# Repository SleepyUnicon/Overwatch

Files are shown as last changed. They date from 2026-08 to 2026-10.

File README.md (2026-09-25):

<div align="center">

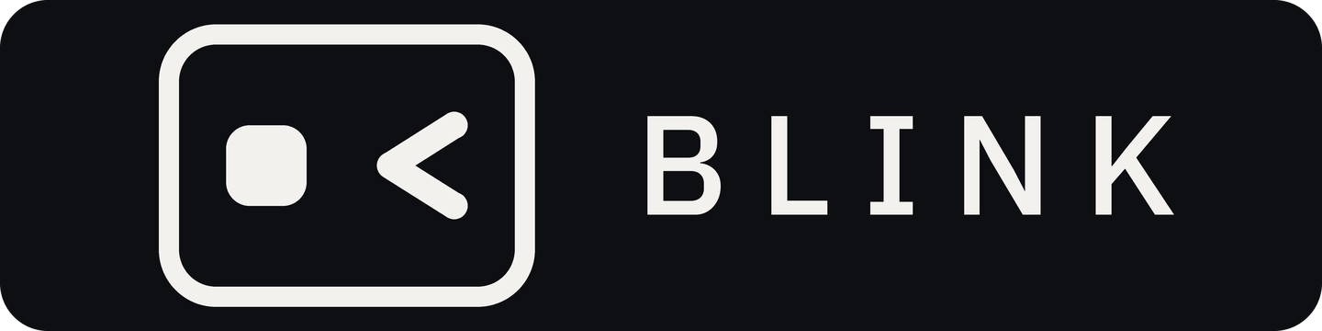
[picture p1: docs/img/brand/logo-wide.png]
OVERWATCH


**Your Claude Code and Codex usage, as two live dials on your desk.**

<p>
  
  
  <a href="https://github.com/openai/codex"><img alt="Works with Codex" src="https://img.shields.io/badge/works%20with-Codex-10A37F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"></a>
</p>
<p>
  
  
  
  
</p>

<table>
  <tr>
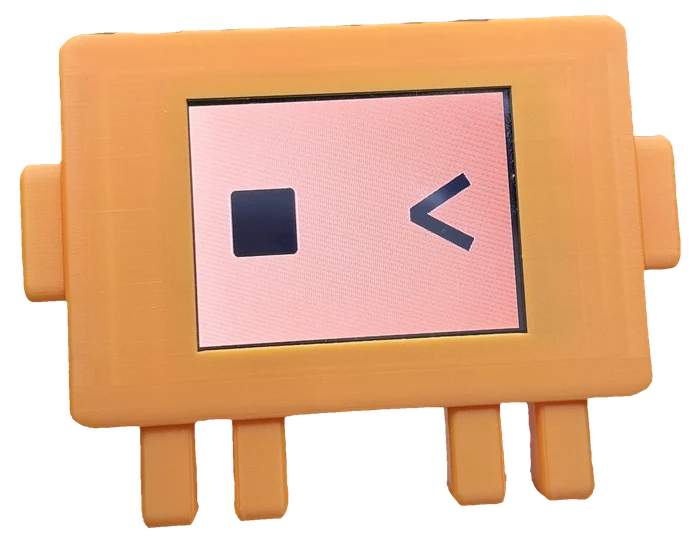
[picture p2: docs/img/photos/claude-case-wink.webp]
The Claude case, mid-overwatch
    <td align="center"></td>
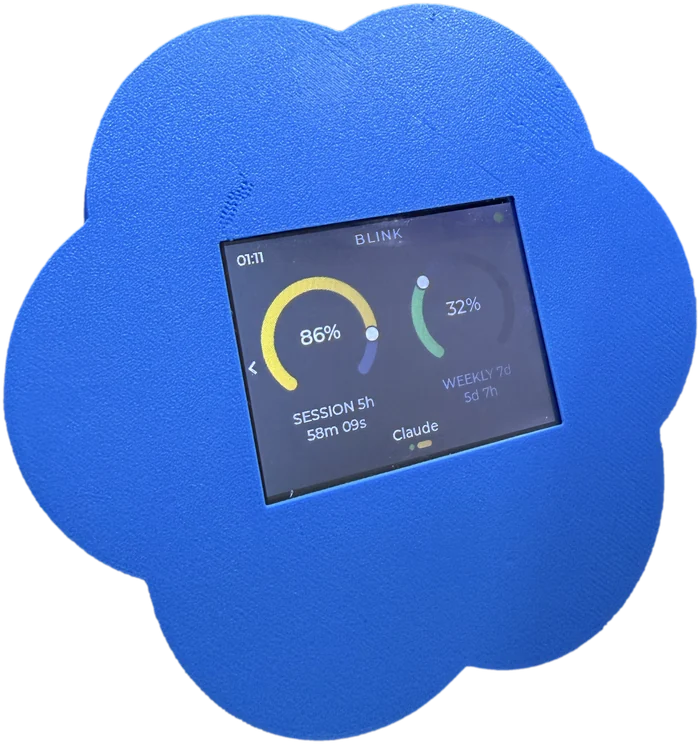
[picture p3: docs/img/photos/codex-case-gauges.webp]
The Codex case, dials live
    <td align="center"></td>
  </tr>
  <tr>
    <td align="center"><sub><b>Claude edition</b></sub>&nbsp;</td>
    <td align="center"><sub><b>Codex edition</b></sub>&nbsp;</td>
  </tr>
</table>

### Don't want to build one?

Ask me for a kit - the printed parts and a flashed board. Free.

</div>

## What it is

OVERWATCH is a small touchscreen that shows the same numbers as Claude Code's `/usage` command, always in view: your **5-hour session** and your **7-day week**, each as a dial that turns from green to amber to red, with a countdown to its reset. It plugs into your computer over USB, sets itself up in one command, and keeps itself updated.

## Open source

**OVERWATCH is open source, and it is free.** Everything the device is made of is
here: the firmware that draws the dials, the app that reads your usage, the
build scripts, the tests. Nothing is held back, nothing is a trial, nothing
expires. The board is an ESP32 "Cheap Yellow Display", about $12 anywhere, and
the case is a 3D print - the files are on
[MakerWorld](https://makerworld.com/en/models/3294736-overwatch-claude-code-codex-usage-monitor).

**You can do anything you like with it, for yourself.** Build one. Build ten.
Change it, rewrite it, put your own name on it. Give them to your friends. Use
it at home, at school, in a club. You will never owe me anything for it.

**The one thing you cannot do is sell it.** Not the device, not the software,
not a product with this inside it. Making money out of OVERWATCH is the only thing
the licence forbids. If that is what you want to do, write to me and ask -
the answer is often yes.

And if you would rather not build one at all, I sell finished units, put
together and tested by hand. That is what pays for the work that goes into
this.

## Features

- **Two dials, two countdowns.** Session and weekly limits, and the time until each one resets.
- **An activity light.** Amber the moment any session - Claude or Codex - is waiting on you; a green pulse while everything is still working; red when a turn dies on an error - a rate limit, most often.
- **A page per provider.** Claude and Codex each get their own screen. Swipe to switch; the needles move from one reading to the other.
- **It sleeps when your computer does.** About thirty seconds after the computer stops answering, the screen closes its eyes and dozes; it opens them the moment the computer is back. A tap while it sleeps shows the last figures.
- **Claude Desktop too.** With Desktop alone the dials show percentages, a five-hour countdown whenever Desktop is holding a reset time, and a weekly countdown once one has been learned. Desktop keeps that reset time only while a window is running and clears it in between, so the countdown comes and goes; the fill rate covers the gaps. The dials follow Desktop's own refresh - about every 5 minutes while you are using it, up to 15 when it sits idle - where Claude Code updates them live.
- **Nothing to sign in to.** It reads figures Claude Code and Codex have already written to disk. No credential, no network, nothing sent anywhere.
- **Updates over the cable.** A new release asks on screen; one tap installs both the firmware and the app. Both halves are signed.
- **Cheap, open hardware.** An ESP32 "Cheap Yellow Display" (~$12) and a 3D-printed case.
- **Company units.** A unit built for a company shows its logo - a still or a short clip - after the boot animation, written once at the factory.

## The screens

<table>
  <tr>
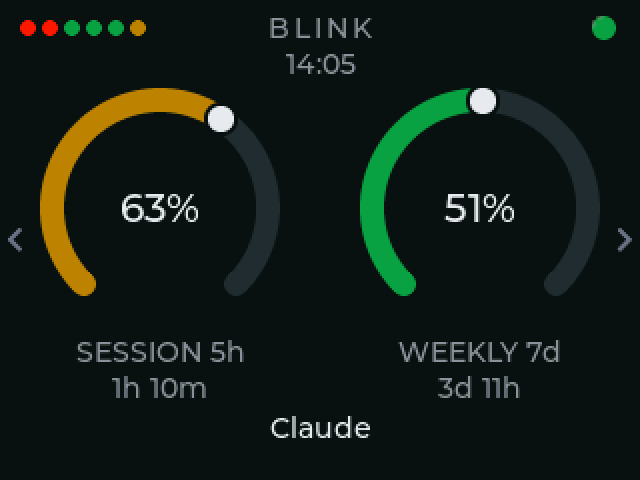
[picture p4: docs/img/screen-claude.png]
The Claude page: six coloured marks in the top-left corner, one per live session, the clock under the OVERWATCH wordmark, and the session and weekly dials.
    <td width="33%"></td>
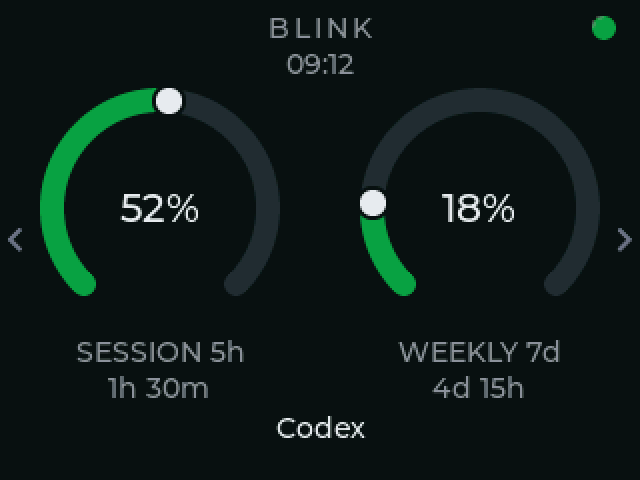
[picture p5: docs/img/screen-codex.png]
The Codex page, with its own session and weekly dials.
    <td width="33%"></td>
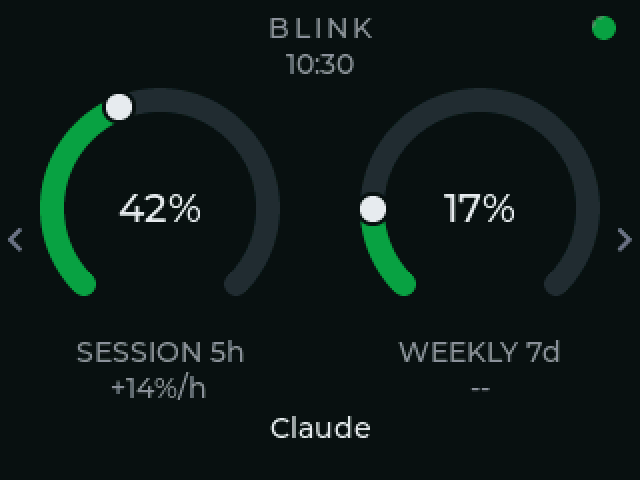
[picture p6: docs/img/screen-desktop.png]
Claude Desktop alone: the session dial shows a fill rate where a countdown would otherwise be.
    <td width="33%"></td>
  </tr>
  <tr>
    <td align="center"><sub><b>Claude</b></sub>&nbsp;</td>
    <td align="center"><sub><b>Codex</b></sub>&nbsp;</td>
    <td align="center"><sub><b>Desktop alone</b></sub>&nbsp;</td>
  </tr>
</table>

Session and weekly, the countdown to each reset, and the time under the wordmark.
The marks in the top-left corner are your live sessions - one per session,
coloured by what each is doing. Claude and Codex each get a page of their own,
and a swipe moves between them. With Claude Desktop alone there is often no reset
time to count down to, so the session dial shows how fast it is filling instead.

*Rendered by the shipping firmware's own drawing code, not mocked up.*

## Setup

One file. Download it, run it, delete it. It copies itself to `~/.overwatch/bin`, finds the board, and starts again every time you log in.

```bash
# macOS (Apple silicon)
curl -fsSL https://github.com/SleepyUnicon/Overwatch/releases/latest/download/overwatch-macos-arm64.tar.gz | tar xz && ./overwatch/overwatch
# macOS (Intel):  .../overwatch-macos-x86_64.tar.gz
# Linux:          .../overwatch-linux-x86_64.tar.gz

```

On Windows, in PowerShell or Command Prompt:

```
curl.exe -fsSL -o overwatch.zip https://github.com/SleepyUnicon/Overwatch/releases/latest/download/overwatch-windows-x86_64.zip && tar -xf overwatch.zip && .\overwatch\overwatch.exe
```

```bash
~/.overwatch/bin/overwatch status      # is the panel getting data?
~/.overwatch/bin/overwatch uninstall   # put everything back
```

Needs Claude Code 2.1.100 or newer. The installer changes one file, `~/.claude/settings.json` (the status line command and one hook per lifecycle event), says so before it does, and keeps your own status line running. Everything it does is reversible with `uninstall`.

## Something's wrong?

```bash
~/.overwatch/bin/overwatch status
```

That one command says whether the service is running, whether Claude Code and Codex are being read, and how old the numbers are. If the panel is dark or wrong, unplug the board and plug it back in first - the app finds it again on its own. If that does not fix it, open an issue on this repository with the output of `overwatch status` and the last lines of `~/.overwatch/bridge.log`; nothing in either is a secret.

**If the board says the app is old.** The board and the app ship together, so normally they match. If they have come apart - the board on a later version than the computer - the board's own update screen cannot fix it, because the half that is behind is the half it cannot reach. `overwatch status` says so and names the cure:

```
Board       COM25 (CH340) -- id 20500d33ff1c, firmware 1.3.2
            the board is on 1.3.2 and this app is 1.3.1 -- they ship together
            run: overwatch update
```

**On Windows, if the board never appears:** the board's USB chip needs a driver Windows does not ship, and the installer puts it in for you - it is the one step that asks for the Windows permission prompt, and it only asks when there is something to install. If you skipped that prompt, or installed an older version, run:

```
%USERPROFILE%\.overwatch\bin\overwatch.exe driver
```

`overwatch status` says which of these you are looking at: a board Windows cannot use yet reads as *"a board is plugged in, but Windows has no driver for it"*, not as an empty desk.

## What it works with

For Claude Desktop, the app learns usage by reading Claude Desktop's own local files on your machine, never anything else - it only ever reads them, and nothing about your usage or your conversations ever leaves the machine.

| You use | You get |
|---|---|
| Claude Code, in a terminal or an IDE | Everything |
| Codex CLI | Everything, on its own page |
| Claude Desktop, without Claude Code | Five-hour percentage and countdown, refreshed within seconds of a turn; weekly percentage on Desktop's own schedule (about 5 min in use, up to 15 idle); a weekly countdown too, once one has been learned, published only while nothing contradicts it; no activity light |
| claude.ai in a browser | Nothing - there is no usage data to read |

## Privacy

OVERWATCH never sees a credential and never sends anything anywhere. It keeps the last usage payload Claude Code wrote, readable by you alone, in `~/.overwatch/`. The device holds no token: nothing to leak, nothing to revoke if you lend it.

## Building units

`tools/burn.sh` programs a unit end to end: it builds signed firmware with the bootloader, flashes it, stamps the edition (Claude or Codex, write-once), and confirms the stamp survives a power cycle. Add `--logo` and the unit shows a company logo after the boot animation. The script fails loudly rather than half-succeeds, and CI runs it on every push against a scripted board so a change to it cannot quietly ship a unit that boots wrong. Details in [docs/README-full.md](docs/README-full.md#programming-a-unit).

## Read more

- **[The full README](docs/README-full.md)** - how the numbers are found, what the installer changes line by line, ports and multiple boards, updates and signing, the decisions behind the first release
- **[firmware/README.md](firmware/README.md)** - building, flashing and signing the firmware yourself
- **[docs/multi-provider.md](docs/multi-provider.md)** - how two sources are merged into one reading
- **[docs/windows-check.md](docs/windows-check.md)** - the ten-minute check a Windows release needs a person for
- **[docs/fleet-testing.md](docs/fleet-testing.md)** - the one command that proves a release on three real desks and three real boards, and what a green run does and does not prove

<div align="center">
<sub>Firmware: Zephyr, C. App: Python, one binary.</sub>&nbsp;<br>
<sub>Board: ESP32-2432S028.</sub>&nbsp;<br>
<sub>Source under <a href="LICENSE">PolyForm Noncommercial 1.0.0</a>.</sub>&nbsp;<br>
<sub>Free to build for yourself. Never to sell.</sub>&nbsp;<br>
<sub>A fork of <a href="https://github.com/KfirLevy258/Blink">Blink</a> by Kfir Levy.</sub>&nbsp;
</div>

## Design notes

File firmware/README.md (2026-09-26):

# Overwatch firmware

The firmware that runs on the **ESP32-2432S028 "Cheap Yellow Display" (CYD)**: two
270° gauges for your Claude Code **session (5 h)** and **weekly (7 d)** usage, a wall
clock, per-model breakdown, and over-the-air updates. Built on **Zephyr** + LVGL,
booting through **MCUboot**, with flash encryption on units whose eFuses are burned.

The firmware version lives in [`src/version.h`](src/version.h) and is reported over
serial in the boot `hello` message.

## How it gets your usage

The board picks a data source at boot - you never choose one:

1. **USB bridge.** If a host daemon answers the boot `hello` over serial, the board
   takes its usage from there (streamed as NDJSON). No Wi-Fi or token on the device.
2. **Wi-Fi.** Otherwise, if it has stored Wi-Fi credentials and a sign-in token, it
   fetches usage itself over TLS, about once a minute.
3. **First-time setup.** With neither available, it shows a setup screen and hosts a
   short phone flow to get onto Wi-Fi and signed in. The setup Wi-Fi is WPA2 with a
   random per-device password carried in the on-screen QR, so the phone types nothing.

## Prerequisites

- **Zephyr v4.3.x** with its Python venv, and **Zephyr SDK 0.17.4**. The build
  scripts find the workspace themselves (`tools/lib_zephyr.sh` looks under
  `~/zephyrproject`, `~/zephyr-v*` and the same two under `~/Projects`); set
  `OVERWATCH_ZEPHYR` to override.

  **Not v4.4.0.** Measured 2026-09-09: its mbedTLS is 4.1.0, which removed the
  legacy `mbedtls/sha256.h` that [`src/ota.c`](src/ota.c) includes, and the
  LVGL it pins moved `gesture_limit` out of the public `lv_indev` headers,
  which [`src/ui_settings.c`](src/ui_settings.c) reads. 4.3.1 has both
  (mbedTLS 3.6.6, `gesture_limit` in `lv_indev_private.h`) and wants SDK
  0.17.4 rather than the 1.0.1 that 4.4.0 asks for. Do not register both SDKs
  at once -- 1.0.1's CMake config breaks 4.3.1's configure even when 0.17.4 is
  registered alongside it.
- The **CYD board** on USB (a CH340 serial port, `/dev/cu.usbserial-*` on macOS).
- Your **signing keys** (see [Keys](#keys)).

## Build

```bash
. tools/lib_zephyr.sh && overwatch_zephyr_activate   # from the repo root

cd firmware
west build --sysbuild -d build-sb -b esp32_devkitc/esp32/procpu . \
  -- -DSB_CONFIG_BOOTLOADER_MCUBOOT=y -DUSE_CCACHE=0 \
  -DSB_CONFIG_BOOT_SIGNATURE_KEY_FILE="\"$HOME/.overwatch/ota_signing_key_p256.pem\""
```

Notes:

- **This builds the shipped configuration: USB only.** `CONFIG_OVERWATCH_WIFI_MODE`
  defaults to `n`, so the captive-portal setup, the OAuth sign-in, the refresh-token
  store and the on-device usage fetch are never handed to the compiler -- absent from
  the image rather than unreachable within it, and about half its size. The source
  stays in `src/`; add `-DEXTRA_CONF_FILE=wifi.conf` to build it back in. `tools/release.sh`
  refuses to publish an image that contains it, checking the artifact and not only the
  config.
- **Sysbuild + MCUboot is required.** Flash encryption needs the MCUboot boot chain;
  a plain single-image build produces something the encrypted chip can't boot.
- The board target is **`esp32_devkitc/esp32/procpu`** - there's no upstream CYD board,
  so [`boards/esp32_devkitc_esp32_procpu.overlay`](boards/) describes the wiring.
  Building with a different `-b` pollutes the build dir; recover with `-p always`.
- **Display SPI is pinned at 25 MHz.** The common 40 MHz CYD overclock white-screens
  some panels (init never latches) - see the overlay comment.

### WiFi mode does not currently link

Tried on 2026-09-26, to test the over-the-air update path. It fails at the
link step:

```
section `.dram0.noinit' will not fit in region `dram1_0_seg'
region `dram1_0_seg' overflowed by 18020 bytes
```

`dram1_0_seg` is 0x18000 -- 96 KB. Two obvious knobs were tried and BOTH
were verified applied in the generated .config, and neither moved the
overflow by a single byte:

| tried | from | to | overflow |
|---|---|---|---|
| `CONFIG_HEAP_MEM_POOL_SIZE` | 86016 | 65536 | 18020 |
| `CONFIG_LV_MEM_SIZE_KILOBYTES` | 64 | 44 | 18020 |

An identical figure across three builds says the thing that does not fit is
none of those -- it is something fixed in `.dram0.noinit`, most likely the
WiFi driver's own static buffers. Whoever picks this up should start by
reading that section out of the map rather than turning config knobs, and
should expect this to be a memory-LAYOUT question (what lives in dram0
against dram1 on this SoC) rather than a sizing one.

Also note `west blobs fetch hal_espressif` is required first; without it
the configure step fails on a missing `libble_app.a`.

None of this is reachable in the shipped build anyway -- `ota.c` is
compiled into every image but `ota_check()`/`ota_install()` are only called
from `net_worker()`, which only standalone mode starts. So the over-the-air
path has never executed on any board.

## Flash

**Not every CYD is fused, so check which one you have first.** A unit whose
flash-encryption eFuses are burned boots *only* images encrypted with its device key;
an unfused unit boots plaintext and cannot read an encrypted image at all. Cross the
two and the board sits in a boot loop (`invalid header: ...`) until it is re-flashed
the other way. Nothing is bricked - flashing burns no eFuses - but a cycle is lost
finding out.

```bash
espefuse.py --port <port> summary | grep FLASH_CRYPT_CNT
```

An **odd** number of bits set means encryption is on; `0` is a plaintext board.

**Fused unit** - use the script, which re-reads the eFuse itself and refuses a
plaintext chip (override with `OVERWATCH_SKIP_EFUSE_CHECK=1`):

```bash
tools/flash_encrypted.sh        # defaults to the first /dev/cu.usbserial* port
```

**Plaintext unit** - two commands, because `west flash` writes only the app at
`0x20000` and leaves MCUboot at `0x1000` untouched:

```bash
west flash -d build-sb --esp-device <port> --esp-baud-rate 115200
esptool.py --port <port> --baud 115200 write_flash 0x1000 build-sb/mcuboot/zephyr/zephyr.bin
```

Port notes: opening the port resets the board, and only one process can own it at a
time. To watch the console without disturbing behavior, use
`tools/passive_log.py <port>` (resets once on open, then read-only). To wipe stored
Wi-Fi / token / setup password for a clean first-run test, erase the NVS region:
`esptool.py --port <port> erase_region 0x3b0000 0x30000`.

Flash map (4 MB): MCUboot `0x1000`, slot 0 `0x20000`, slot 1 `0x170000`,
scratch `0x2C0000` (unused in swap-move mode), **company logo `0x330000`
(512 KB, see `src/logo_parse.h`)**, settings `0x3B0000`. The logo partition is
written only by `tools/burn.sh --logo` / `tools/flash_encrypted.sh --logo` and
read memory-mapped at boot; erase it (`erase_region 0x330000 0x80000`) to turn
a bench board back into an individual unit. `tools/flash_encrypted.sh` erases
it by default -- pass `--keep-logo` when re-flashing a dev board that should
keep its logo.

## Keys

Two secrets live **outside the repo**, in `~/.overwatch/`:

| Key | Purpose |
|-----|---|
| `flash_key.bin` | Encrypts what's written to flash. Override with `OVERWATCH_FLASH_KEY`. |
| `ota_signing_key_p256.pem` | Signs firmware images (ECDSA P-256) so the board will boot them. Override with `OTA_SIGNING_KEY`. |

**Back both up off this machine.** The eFuse copy of the flash key is sealed and
unreadable - the file is the only usable copy. Lose the signing key and you can no
longer ship updates that installed devices will accept (only a USB reflash with a new
key recovers).

## Releasing an update

```bash
# 1. bump OVERWATCH_FW_VERSION in src/version.h, commit
# 2. from the repo root:
tools/release.sh
```

`release.sh` builds from the committed tree (it refuses a dirty tree or a reused
version), signs the image, and attaches `overwatch-fw.bin` + `manifest.json` to the
`overwatch-v<version>` release on **`SleepyUnicon/Overwatch`** - which is the feed every board reads.

On the device there are two ways in, and it picks by itself:

- **Standalone (WiFi).** The board streams the image into its spare slot, verifies the
  SHA-256, reboots, and MCUboot swaps it in.
- **Tethered (USB bridge).** This mode has no network of its own -- `run_usb()` never
  starts `net_worker` -- so the board only *approves*, and the daemon fetches the
  release and writes slot0 with esptool. About 75 s, and no swap, because the bytes
  land where the bootloader already looks. The trade is no automatic rollback on that
  route; it is acceptable only because a machine that can reflash the board is by
  definition already cabled to it. Requires `pip install esptool` wherever the daemon
  runs.

A check runs as soon as the board is up (and daily after that). Anything newer raises a
prompt on the gauge screen -- **Update now** / **Later** -- and the settings row still
offers **Software update → Install x.y.z** on demand. Either route reports the outcome
on the next boot.

## How updates stay safe

Four independent layers, each guarding one thing:

- **TLS with pinned roots** authenticates the *download*.
- **The manifest's SHA-256** pins the *exact bytes*, end to end.
- **MCUboot's ECDSA P-256 signature check** gates *what may boot* - only images signed
  with your private key run, so even a hash-passing forgery is rejected.
- **Automatic rollback** - a fresh image boots in test mode and must prove itself
  (fetch usage) within 90 s. If it hangs or crashes, the watchdog reboots and MCUboot
  restores the previous version, which then reports *"Update failed, previous version
  restored."*

The first three hold on both routes. The fourth does not apply to the USB one, which
writes the running slot in place -- there is no spare copy to fall back to. The daemon
compensates where it can: it verifies the asset against its manifest before writing,
and it reads the chip's eFuses and refuses outright if it cannot tell whether flash
encryption is burned, since a plaintext write to a fused board leaves it dark.

On a fused unit, flash encryption keeps secrets (Wi-Fi password, token) unreadable at
rest. **An unfused development board has no such protection** - its stored Wi-Fi
password and OAuth token are readable from a flash dump, so treat one as a device that
holds live credentials in the clear. Published images hold no secrets either way -
installability is gated by the signing key, not secrecy.

## Hardware notes

Things worth knowing when hacking on the CYD:

- The radio occasionally boots blind (all scans empty) after a soft reset; the firmware
  self-reboots to re-roll it, bounded by a `.noinit` counter.
- Touch (XPT2046) needs averaging (`reads = <8>`), and devicetree properties are
  last-one-wins - a stray duplicate silently degrades it.
- The backlight (GPIO 21) runs on LEDC PWM and is adjustable in Settings.
- A Wi-Fi join only completes from a clean boot on this driver, which is why the
  first-run flow reboots on purpose (invisibly - the CONNECTING bar spans the reset).

## Source map

| Area | Files |
|---|---|
| Boot, orchestration, workers | `main.c` |
| Boot splash (streamed past LVGL) | `ui_boot.c`, `bootanim_dec.c` |
| First-run setup screen | `ui_setup.c` |
| Phone captive portal | `portal.c`, `dns_hijack.c` |
| Gauges, warnings, model card | `usage_view.c` |
| Settings + software-update UI | `ui_settings.c` |
| OTA engine (check, install, verify) | `ota.c`, `ota_parse.c` |
| Networking, time, sign-in, fetch | `net_wifi.c`, `net_time.c`, `oauth.c`, `usage_client.c`, `usage_parse.c`, `tz_fetch.c` |
| Persisted config (A/B, CRC-sealed) | `cfg_store.c` |
| Serial NDJSON protocol | `proto.c`, `msg_parse.c` |

Parsers and the protocol have host-side unit tests under [`../tests/`](../tests/).

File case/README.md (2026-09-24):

# The Overwatch case

A bezel that shows the **picture and nothing else**, and an **empty** tray that
plugs into the back of it. Two printed parts, no screws, no posts, nothing
inside the body at all.

| part | | print it |
|---|---|---|
| `front_bezel.stl` | 90.8 × 54.8 × 11.2 | face **down** |

Assembled the case is **46.2 mm** front to back — the bezel stands 6.2 in front of the tray, so the tray's own 40.0 is not the whole depth.
| `back_tray.stl` | 90.8 × 53.1 × 40.0 | open side **up** |

```sh
openscad -D 'PART="front"' -o front_bezel.stl overwatch_case.scad
```

## What changed, and why

The version before this had two faults that between them cost a panel.

**The aperture was sized to the glass, and the glass was a press fit in it** —
0.3 mm nominal, which an FDM hole can easily print *undersize*. The only way
the panel went in was by being pressed, and pressing a glass module into a
too-small hole cracks the flex between the glass and its board. It then lights
up white and never draws, with nothing in any log to say why.

**Four snap pegs sat inside the panel's footprint** — x=±40, y=±12 against a
board of ±43 × ±25. To reach their sockets they travelled through the space the
board occupies, so assembling it would have pressed four posts into the back of
the panel. They had been moved out of the corners to save border and never
checked against the board.

Both are gone. **The lip now overlaps the glass**, so the glass does not pass
through the aperture at all — it goes in from behind and rests against the lip.
There is no press fit left to be tight. And there are no pegs, because there is
nothing inside.

## The window

Sized to the **lit area**, not the glass. The glass carries 5.7 mm of dead
black each side and 3.4 top and bottom; that dead black was the border you
could see. It is under plastic now.

| | |
|---|---|
| at the glass | 59.6 × 45.2 |
| at the face | 63.6 × 49.2 — chamfered out 2.0 per side |
| visible border | 13.6 sides, 2.8 top and bottom |

The **chamfer is on the left and right only** — 3 mm per side. It keeps the
corners from catching a fingertip reaching for the edge of the picture.

Chamfering all four edges cost 3 mm of border top and bottom, where there is
only 5.4 to begin with: it left a **1.4 mm knife edge** against sides of 9.4
and 15.4. The sides can afford the taper and the top and bottom cannot, so the
top and bottom walls stay square and the border there is 4.4.

The window sits on the **glass's** centre, not the board's — 8 mm of red on
the left against 9 on the right, so centring it on the board would put the
picture half a millimetre out.

### Where the picture actually is

**Measured on the board, 2026-09-24**: the picture starts 11 mm in from one end
of the 86 mm board and 17 mm in from the other — so it is **58.0 wide** and its
centre is **3.0 mm off the board's**.

Two independent measurements agree. Reading off the printed case gave 13 and 20
from the *case* edge; with the board inset 2.4 each side that is 10.6 and 17.6
from the board edge, against 11 and 17 here — within 0.6 mm. The board reading
is the one used, because it does not depend on the case having printed to size.

58.0 also lands 0.4 mm off the nominal 57.6 for a 2.8" 4:3 panel. That kind of
agreement usually means both numbers are right.

The window is drawn 1 mm larger all round, so it sits **1.0 mm outside the
picture on every side** — a sliver of black glass shows and nothing is covered,
which is the direction to err.

**The vertical inset has not been measured.** The picture is assumed centred on
the board's 50 mm, which the glass being full height makes likely — but it is
an assumption, not a measurement. If it turns out to be off, `act_h` and a
vertical offset are the two numbers to add.

### Square corners

`ap_r` is 0.4 — half a nozzle, i.e. as square as an FDM part gets. The
display's own corners are sharp, so a rounded window would leave four crescents
of black glass showing at the corners and nothing else.

## Clearances

**1.0 mm everywhere the panel touches**, against 0.4 before. The old 0.4 is
what made it a press fit, and the press fit is what broke the flex.

## How the halves join

At the **rim**. The bezel carries a 1.4 mm rim reaching back past the board;
the tray's spigot plugs into it. Friction — and the join is at the perimeter
where there is room for it, not through the middle where the panel is.

`rim_fit` (0.2 per side) is the number to tune. Loose, lower it; will not
seat, raise it. Only the tray needs reprinting.

## The panel's seats, and why they are not dead square

The panel has sharp corners, so the seats are cut as square as the geometry
allows — but "as square as allows" is a real limit here, not a shrug.

**The corner radius comes from the clearance.** A sharp corner in a pocket
rounded by *r* clears by `r − √2·|clear − r|` while *r* > clear, and by the
full `clear` once *r* ≤ clear. So `seat_r = clear` is the point where the
corner clears exactly as much as the flats do, and sharper buys **nothing**.

**It cannot go sharper anyway.** The seat's corner is at (44, 26); the outer
profile's corner arc is centred at (41.4, 23.4) with r=4. Dead square leaves
**0.323 mm** of wall there — under one extrusion, so it prints as a hole.

| seat r | wall at the corner | corner clearance |
|---|---|---|
| 1.5 | 0.944 | 0.793 ← what V1 had |
| **1.0** | **0.737** | **1.000** ← here |
| 0.0 | 0.323 | 1.000 — unprintable |

Corner *relief* — a small circle centred on the corner — is out for the same
reason: it would have to be under 0.323 to stay inside the wall. Tried it; it
punched straight through the outside face at all four corners.

### What actually held the first V1 off was the clearance

Not the rounding. At `clear` = 0.4 the board's corner fell **1.556** from the
arc centre against a **1.5** radius: fouling by 0.056 before the printer added
its own corner fillet. At `clear` = 1.0 it clears by the full millimetre. The
rounding only mattered because the clearance was too small to absorb it.

## The bezel-to-tray joint

Measured off the two STLs, on the mating flats:

```
bezel rim opening   ±44.00   outer ±45.40   (a 1.40 ring)
tray spigot         ±43.80   inner ±41.80   (a 2.00 wall)
                 -> 0.20 a side
```

Two surfaces land **at the same moment**: the tray's shoulder on the rim's back
face at z=11.2, and the spigot's nose on the board's back face at z=6.2. The
spigot is 5.0 long and the rim cavity is 5.0 deep, so the joint closes flush
with no step — and the panel is held with **zero nominal slack**.

That is the one number to watch. It is right if the panel really is 3.4 of
glass on a 1.6 board; if it measures 5.2 rather than 5.0, the difference goes
into the glass. Standing the spigot off 0.3 would trade that risk for 0.3 of
play — the shoulder would still be the hard stop, so the joint stays flush.

The corners clear comfortably: the spigot's corner-most point is 0.054 from the
rim opening's arc centre against a 1.0 radius.

## The connector edge

The display's connectors sit on the **back** of the panel and start right at
the edge on the case's right-hand side — negative x, the same edge the USB
comes out of. The spigot's nose overlaps the board by 1.2 all the way round,
so on that edge it landed straight on them.

Nothing *inboard* of the spigot's inner face needed any help: that is open
cavity, 33 deep. Only the 1.2 band where the nose overhangs the board was in
the way, so that band is cut back over `panel_conn` = 3.4 (the 3.0 measured
behind the board, plus 0.4).

```
spigot's -x wall at z=1.0 (in the relief) : -43.80 .. -43.00   0.8 thick
spigot's -x wall at z=4.5 (past it)       : -43.80 .. -41.80   2.0 thick
```

The spigot keeps its full **outer** face there, so it still locates in the
rim — it just stops touching the board on that one edge. The panel bears on
the other three, which is plenty given the glass is also carried by the lip
all the way round.

## The ESP32's perch

The board lies **flat against the back wall**, component side toward it, with
its pins and dupont shells pointing forward into the body — the only place with
room for them. Two rails stand off the wall, each with a groove the board's
long edges slide into. It goes in **from the right** until its port end meets
the wall, so the USB-C lines up with the slot by construction.

The rails' inner faces sit *inside* the board's width, which only works because
it slides in sideways — they could not capture an edge they did not overlap.

### The slot is cut to the board

| | board | slot | slack |
|---|---|---|---|
| width | 27.94 | **28.24** | 0.15 a side |
| thickness | 1.60 | **1.75** | 0.15 total |

It used to leave 0.50 a side and 0.30 on the thickness, which is a rattle, not
a fit. FDM takes most of the new figure back — a slot prints 0.1–0.2 narrow —
so 0.15 lands near zero slack in the plastic.

`esp_fit` is the number to open up if the board will not go in. **Do not force
it.** Forcing a fit is how the first display's flex went.

The three faces are now named rather than derived by arithmetic on the rail's
centreline: `y_grip` (the lip's inner edge, over the board), `y_slot` (where
the board's edge stops) and `y_out` (the rail's outer face). The slot is cut
from the centreline outward so it stays open inboard — a slot closed on both
sides is one the board cannot enter.

### Everything inside is clipped to the cavity

The perch is sized for the **board**, then intersected with `tray_inside()`,
the same shape that hollows the box. Without that clip the end stop — board
width plus the gap plus both rails, 35.14 across — drove a 3 mm tab straight
through the bottom of the case, and the rails broke through by 0.41 over their
last few millimetres.

The cavity is not a box. The underside slants at 15°, so it is **narrower at
the back**: its floor is at −17.43 where the board's groove sits (z 30.4–32.0)
but has climbed to −15.56 by the back wall. A part that clears the floor at
the front can still be outside the case at the back. Clipping makes that
impossible to get wrong again, whatever the perch is later resized to.

### The numbers are the board's own

| | spec | the model used to say |
|---|---|---|
| length | **48.26** | 52.0 — 3.7 too long |
| width | **27.94** | 28.0 |
| pins below the board | **8.50** | *nothing at all* |

### The standoff is set by the PLUG, not the socket

`esp_stand` = 6.0 mm. The connector is only 3.16 tall, so 4 would clear it —
but a USB-C plug's overmould is about 7 across, centred on that socket:

| standoff | plug reaches | back wall at 38 |
|---|---|---|
| 4 | 39.08 | **fouls** |
| 5 | 38.08 | **fouls** |
| **6** | **37.08** | clears by 0.92 |

At 4 mm the cable hits the case before it seats — and the socket would have
looked perfectly fine in a render.

## The vents

**Two rows of hexagons across the top of the back wall**, with the board
directly underneath.

The cell size is not a style choice. The slanted underside has risen to
y = −15.56 by the time it reaches the back wall, so the usable height there is
**42.96 mm** — and the board takes 27.94 of it. That leaves about 12 mm for two
rows, which sets `hex_r` at 2.6.

The board is centred on y=0, spanning −13.97 to 13.97: clear of the floor by
1.59 and topping out just under the vents at 13.6.

### They were sealed too, and by the same arithmetic

The cell was extruded from `rim_d + tray_d + back_t - 1` = 39, through
`back_t + 2` = 4, so it cut 39→43. The back wall spans **38→40**. Every cell
kept a 1 mm skin on its inside face — the identical fault to the port, one
wall over. It now starts at `rim_d + tray_d - 1` = 37.

**Genus was how both were caught.** A closed box with *n* holes through its
walls is genus *n*: it read 0 while both were skinned, and 1 once only the port
was open.

It is not the check to keep, though — genus counts *every* handle, including
three small channels where the lower rail merges into the sloping floor. Shrink
the rails (`-D esp_l=5`) and the tray reads exactly 22, one port and 21 cells.

Cast a ray through each cell instead. That answers the question actually being
asked — **is this hole a hole** — and it does not care what else the part does.

### The port

A **stadium, not a rectangle** — 12.95 × 7.10, fully round-ended, centred at
z = 33.58. Its position is derived, not chosen: `rim_d + tray_d - esp_stand +
usb_shell_h/2`, which puts it on the socket's centreline by construction.

The size is the **plug's**, not the receptacle's. The spec's maximum cable
overmould is 12.35 × 6.50; `usb_fit` adds 0.60 for slop and for FDM printing
holes 0.2–0.4 under. Sizing this opening 8.94 × 3.16 to match the socket would
look right and pass no cable at all.

#### It was sealed shut, and the cavity was why

The opening is cut `wall + 2` long, from x 42.4 to 46.4 — correct for a 2.0
wall whose inner face is at 43.4. But `tray_inside()` carried the **spigot's**
width all the way to the back, putting the real inner face at 41.8 and making
the sides 3.6 thick. The cut stopped 0.6 short and left a skin across the port.

The same mistake cost the board its slot. `x_wall` is `face_w/2 - wall` =
43.4, so the stop sits 48.26 from there — but with the cavity ending at 41.8
the gap was only 46.66, and the ESP32 is 48.26. **It would not have gone in.**

The cavity now steps: the spigot's width through the spigot, where it has a
rim to enter, and the body's width through the body, where it has no reason to
give up 1.6 mm a side. Both faults close together.

A useful tell: a hollow box with a hole through one wall is **genus 1**. While
the skin was there OpenSCAD reported genus 0.

#### Which side is it on?

The viewer's **right**, which is **negative x**. That sign is the whole trap
and I had it backwards.

The screen's face is at z=0 and the body runs back to +z, so the viewer looks
**along +z** with +y up. For a right-handed frame, a viewer whose forward is
+z and whose up is +y has their right hand pointing at **−x**. Write "the USB
is on the right" as +x and the case comes out mirrored — port on the far side,
and the wide border mirrored with it.

Nothing catches this. The box is symmetric enough that no render looks wrong,
and the relational check — *is the port on the same side as the wide border?* —
passes happily while **both** are on the wrong side. It took putting the part
on a build plate, with the slant on the bottom where it belongs, to see it.

So `act_cx` is no longer a signed guess. It is derived from the border the
viewer actually sees on their right:

```
bez_right = 17.0;                                  // measured
act_cx    = -pcb_w/2 + bez_right + act_w/2;        // = +3.0
```

and the board's port end butts `-(face_w/2 - wall)`. Both now read 18.35 on
the viewer's right and 12.35 on their left, against the measured 17 and 11.

#### Could the opening be socket-sized?

Only if the socket's mouth is flush with the outside. It sits `usb_over` = 1.20
proud of the board's end, and the board butts the inner face at 43.4, so the
mouth lands at 44.6 — 0.8 behind the outer face at 45.4. Whatever passes
through that last 0.8 mm has to be plug-shaped.

To get a 9.5 × 3.8 opening instead, pocket the wall 0.8 deep where the board's
end lands, bringing the socket flush; the overmould then stops against the
outside of the case and 1.2 mm of wall remains around the pocket. It hangs
entirely on `usb_over` being right — measure it before committing to it.

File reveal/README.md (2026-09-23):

# The Overwatch films

Four eight-second clips at 1080x1920, built headless in Blender from the same
STLs the case prints from. Nothing is modelled twice: change
`case/overwatch_case.scad`, re-export, and the next render picks it up.

```sh
BL=/Applications/Blender.app/Contents/MacOS/Blender

$BL --background --python scene.py -- --shot reveal  --portrait \
    --res 1080 1920 --samples 64 --anim overwatch_reveal_9x16.mp4

$BL --background --python scene.py -- --shot widgets --portrait \
    --res 1080 1920 --samples 64 --anim overwatch_widgets_9x16.mp4

$BL --background --python scene.py -- --shot sweeps  --portrait \
    --res 1080 1920 --samples 64 --anim overwatch_sweeps_9x16.mp4

$BL --background --python scene.py -- --shot hand    --portrait \
    --res 1080 1920 --samples 64 --anim overwatch_hand_9x16.mp4
```

Drop `--portrait` for 16:9. A single frame, for iterating on the look without
waiting for 240 of them:

```sh
$BL --background --python scene.py -- --shot widgets --portrait \
    --still 85 --res 405 720 --samples 20 --render look.png
```

## Shot 2 - the widgets

The three pages, swiped. Gauges, Spotify, launcher, and back to gauges so the
clip LOOPS - it is going on a feed, and a hard cut back to the first frame is
the one thing a viewer always notices.

The swipe is not a texture swap. `make_screen.py` stacks the three pages into
one tall image and the material maps a third of it onto the panel; sliding the
mapping IS the swipe, so the transition is whatever easing the keys carry.
13 frames of travel, which is about 0.45 s - what a deliberate page change
feels like on the panel.

The barbell is cropped at the sides here on purpose. The subject is the
screen, and holding the whole 182 mm silhouette in frame would put the panel
too far away to read.

## Shot 3 - the sweeps

Four fast moves, each snapping to a new angle and settling, with a push-in on
the third. `snap()` keys them QUAD / EASE_OUT rather than SINE / EASE_IN_OUT,
which is the whole difference between a camera whipping somewhere and a
camera drifting there. Lit from frame one; nothing is being revealed.

## Shot 4 - the hand

A finger, not a hand. A modelled hand that is not very good is worse than no
hand at all; a finger entering soft and slightly out of focus reads as a hand
without claiming to be one. It is a capsule with a warm subsurface skin
shader, and motion blur does most of the work.

**The swipe travels UP, not sideways.** `ui_pages.c` walks the stack
vertically, so a horizontal swipe here would show a gesture the firmware does
not implement.

## Shot 1 - the reveal

| | |
|---|---|
| 0.0 - 1.0 s | Near-dark. Only the rims are up, so the barbell reads as a silhouette before anything else does. |
| 1.0 - 3.0 s | Key and fill come up. The form arrives. |
| 4.0 - 5.0 s | The panel wakes - a stutter, then it holds. |
| 5.0 - 8.0 s | Settles onto the hero three-quarter as the camera rises and slows. |

The order is the whole point: light first, screen second. A panel that is lit
from frame one has nothing left to give at frame 130.

## The launcher icons

`icons/` holds the six app icons, extracted from the installed bundles on this
Mac with `sips` - Claude, Illustrator, Photoshop, Spotify, Brave and PCSX2.
Real icons rather than drawn approximations: a launcher showing what it
launches is the ordinary thing, and hand-drawn near-misses of six brand marks
would look worse and sit less comfortably.

**The firmware draws these icons now.** `tools/encode_icons.py` turns this
directory into `firmware/src/icons_gen.h` - 6 icons at 40x40, RGB565A8,
28 KB of flash - and `ui_launcher.c` draws them, falling back to text for any
key it was not built with. So the clips and the board agree.

Re-run the encoder if you change the icons:

```sh
python3 tools/encode_icons.py --in reveal/icons --size 40
```

## 9:16

`cam_d.sensor_fit = 'HORIZONTAL'` is load-bearing in portrait. On AUTO,
Blender fits the sensor to the LARGER dimension - which in 9:16 is the height
- and the barbell, the widest thing and the whole silhouette, runs off both
edges. Fitting to width is what makes the framing mean the same thing in
either aspect.

## Decisions worth keeping

**EEVEE, not Cycles.** Cycles on the M4 rendered one 960x540 frame in 2 min 11 -
about eight hours for the sequence. EEVEE with raytraced shadows does this
lighting at roughly a second a frame. For a dark studio with four area lights
and one emitter, the difference on screen does not pay for the difference in
time.

**The screen is the real UI.** `make_screen.py` draws the shipping layout -
two arcs, their percentages, the countdowns, the wordmark and the session pips
- at 8x panel resolution so it stays sharp when the camera is close. It is an
emitter, so it lights the bezel around it.

**Emission is 1.85, not 5.** AgX desaturates anything near clipping, and at 5
the blue arcs rendered white. The number is set by what survives the transform,
not by what looks bright in isolation.

**The floor is rough, not dark.** Three rounds of darkening the floor did
nothing about the bright pool in the corner of frame, because it was a
SPECULAR reflection of the rim lights and specular ignores base colour.
Roughness 0.62 and specular level 0.18 are what actually reached it.

**The lights are aimed by constraints,** not by hand-written euler angles. The
hand-set version put a hot pool of floor in the opening frame.

**0.2 mm layer lines.** A wave texture along the print's own Z drives a 0.09
bump. Almost invisible, and it is the difference between a render of a 3D
print and a render of an injection moulding.

## Blender 5 gotchas this script already handles

Three API changes that each cost a debugging round:

- **`action.fcurves` is gone.** Keyframes live in slotted actions now;
  `fcurves_of()` handles both shapes.
- **The compositor is a node GROUP on the scene** (`compositing_node_group`),
  there is no `scene.node_tree` and no Composite node - and the group's Image
  input does NOT carry the render. Wire the group input straight to the output
  and every frame comes out black. Use a Render Layers node inside the group.
- **Node settings are SOCKETS now.** `glare.glare_type` does not exist;
  it is `glare.inputs["Type"]`, and the enum values are title case (`Bloom`,
  `High`), not upper.
- **Video output needs `image_settings.media_type = 'VIDEO'` first.** Setting
  `file_format = 'FFMPEG'` on its own is rejected with a list that does not
  mention video at all.

## Knobs

| | |
|---|---|
| Length | `FPS, SECS` near the top of the animation block |
| Camera | the `(dist, lift)` pairs and the pivot's start/end angles |
| Exposure | each light's `energy`, and the `ramp()` calls that bring them up |
| Screen wake | the `ramp(bs, ...)` stutter keys |
| Bloom | the `put(glare, ...)` calls |

## What this is not

It is a render of a model that has never been printed. The layer lines are
procedural, the plastic is ideal, and nothing sags. When a real one exists,
a photograph of it beats this - use this until then.

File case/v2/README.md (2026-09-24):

# V2 — the wedge

A slanted screen on a flat base. **Two printed parts, no screws.**

| part | what it is | print it |
|---|---|---|
| `v2_shell.stl` | the wedge: slanted front with the window, vertical back with the port and honeycomb, closed top and sides, **open bottom** | on its **back** |
| `v2_base.stl` | the bottom, snaps in and carries the ESP32 | flat, posts up |

Everything enters from underneath — panel, loom and board — so the shell has
no seam anywhere you look at it.

```sh
openscad -D 'PART="shell"' -o v2_shell.stl overwatch_v2.scad
```

**90.8 wide x 70.0 deep x 53.2 tall.**

## Why the port reaches the back here, and could not in V1

A DevKitC carries its USB connector on a **short end, in the plane of the
board**. V1 laid it flat against a *vertical* back wall, so that port pointed
at a **side** wall — the back slot first cut there would have opened onto
solid board.

Lying it flat on a **horizontal** base turns the port to face horizontally.
Aim that end at the back wall and it exits the back. That is the whole trick,
and it only works because the base is flat.

## The depth is not 52, and not 52 plus the lean either

The panel leans back **over** the base, so the board sits under it — they
overlap in plan, and adding the two was wrong.

But the panel's back surface is a sloping line,
`z(y) = y·tan(lean) + panel_d/cos(lean)`, and the board has to start behind
wherever that line sits at the board's own height:

| ESP32 height | board starts at | case depth |
|---|---|---|
| 20 mm (dupont shells standing up) | 18.8 | 73.2 |
| 6 mm (bare board, cables led flat) | 13.7 | 68.1 |

**Lying the cables flat is worth 5 mm of case.** 70 is the built figure.

## 20 degrees

Sitting at a desk — eyes ~35 cm up, device ~40 cm away — your sight line drops
about **41°**, so a screen aimed straight at you would lean **49°**. That
costs 90 mm of depth and is not buildable here.

| lean | height | depth | off-axis |
|---|---|---|---|
| 15° | 48.3 | 64.9 | 34° |
| **20°** | **47.0** | **69.1** | **29°** |
| 25° | 45.3 | 73.1 | 24° |
| 30° | 43.3 | 77.0 | 19° |

29° off-axis is well inside what an ILI9341 takes without washing out. Past
25° the depth climbs faster than the viewing angle improves.

## One coordinate convention, stated once

`wedge()` rotates a profile by `[90,0,90]`, which maps local `(x,y,z)` to
world `(z,x,y)`. So throughout:

```
world X = WIDTH    (centred on 0)
world Y = DEPTH    (0 at the front edge, +depth at the back)
world Z = HEIGHT   (0 at the base)
```

The first version wrote every cut with Y as height and Z as depth — the other
way round — so the window, the port and the vent all landed outside the solid
and removed nothing. **The shell rendered as a featureless box**, which is
exactly what that looks like.

## The front face is thicker than the wall

The glass stands **3.4 mm proud of its board**, so 3.4 of face in front of the
PCB is what makes it finish flush; the board's own 1.6 sits behind that.
`front_t = 5.0`.

2 mm of wall would leave the glass standing 1.4 proud and the pocket cutting
clean through the face — a front you could see straight through, which is
what the second render showed.

The board is held by the two **ledges under the red strips**, as in V1, and
for the same reason: the glass is the full height of the board, so there is no
red top or bottom to grip.

## Two things the first print got wrong

**The base would not seat — it fouled the front.** The shell's front wall
leans, so the cavity's front boundary moves *back* as it rises:
`Y = z·tan(lean) + wall/cos(lean)`. The lip was drawn as a straight-sided
rectangle, so it cleared at the bottom and jammed harder the further in it
went:

| height | cavity starts at | lip front | |
|---|---|---|---|
| 0.0 | 2.13 | 2.25 | clears |
| 2.5 | 3.04 | 2.25 | **1.79 mm clash** |
| 5.0 | 3.95 | 2.25 | **1.70 mm clash** |

The lip's front is now set back to clear at its *tallest* point, which is the
only place that matters: `lip_h·tan(lean) + wall/cos(lean) + lip_fit` = 4.20.

**The ESP32 had nowhere to sit.** The first version was two bare pegs. They
held the board off the floor at roughly the right height and did nothing else
— nothing located it sideways, nothing stopped it sliding, nothing held it
down. Pushing a USB-C cable in would simply shove the board off them.

It is a cradle now: pads to set the height so the port centres on the hole,
side rails with a lip that the board slides under **from the back**, and a
stop at the front. The board slides back until its port end meets the shell's
back wall, so the connector lines up by construction rather than by careful
placement. Plug and unplug without the board moving.

## It only goes in one way

A rib on **one side rail** of the base's lip, 20 mm from the front, and a slot
for it in the shell's matching side wall.

It was on the *back* rail first, meant to be blocked by the leaning front wall
when reversed — but only by **0.52 mm**, because the lip's front is already set
back 1.95 mm to clear that lean, and a reversed base simply eats the slack. The
setback fights the keying.

Off-centre along the **length** cannot be symmetric. The rib spans Y 8–32;
reversed it lands at Y 38–62, where the shell's wall is solid. The two ranges
do not overlap at all, so it cannot even half-seat, and it is blocked by the
rib's full 1.25 mm with nothing to absorb it.

**24 × 4 mm, standing 1.5 proud.** It was 10 × 3 first, which keyed correctly
and could not be *found* — at that size it reads as a print artefact rather
than a feature, and a tab that small snaps off the first time the base is
prised out. Length is free here, since the blocking depth is what does the
keying, so it buys visibility and strength for nothing.

Telling front from back by eye, if you need to: the **finger notch** is on the
front edge, the **cradle rails** are at the back, and the lip sits 4.2 mm in at
the front against 2.25 at the back.

## Room for the flex

The glass is 69 wide on an 86 board, so its flex has to reach the PCB at one of
the two **short** edges — the 8 mm and 9 mm red strips. The pocket gave those
edges **0.4 mm**, which is nothing: a flex that wraps the edge, or merely
stands proud of it, is gripped by the pocket wall. A panel went white after
being fitted, and this is the likeliest reason.

Both short edges are now relieved by `flex_gap` (1.5 mm), over the middle of
the edge only. Relieving the whole edge would leave the board unlocated in X
and the picture would wander in the window; `flex_land` (9 mm) keeps a land at
each corner to place it.

Both edges, because which one the flex exits is not something a photo settles,
and relieving the unused side costs nothing.

## The number to tune

`lip_fit` (0.25 per side) is how tightly the base sits in the shell.

| symptom | change |
|---|---|
| base falls out or rattles | **lower** by 0.05 |
| will not seat, or the shell bows | **raise** by 0.05 |

Only `v2_base` needs reprinting; the shell is unchanged.

## Print notes

The shell prints **on its back**: the back is flat, the open bottom faces
sideways, and the slanted front becomes a 20° overhang — inside the 45° rule,
so no supports.

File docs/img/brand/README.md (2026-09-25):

# Overwatch brand assets

Generated by `tools/logo.py` in the website repo
(`~/Projects/OverwatchWebsite`), which holds the geometry. Do not hand-edit
anything here: run that script and copy the output over.

| file | for |
|---|---|
| `logo-wide.svg` / `.png` | the horizontal lockup - mark left, wordmark right. The README banner. |
| `logo.svg` | the stacked lockup, light ink, for dark grounds |
| `logo-dark.svg` | the same in dark ink, for white |
| `logo-mark.svg` | the mark in `currentColor`, for pasting into a page |
| `logo-mark-light.svg` / `-dark.svg` | the mark with an ink baked in, for opening anywhere |
| `favicon.svg`, `favicon-32.png` | browser tab |
| `icon-512.png`, `apple-touch-icon.png` | app and home-screen icons |

One ink, white on black. The mark has to print on a case in a single colour,
so nothing in it depends on a second one. The wordmark is converted to
outlines, so these files do not need IBM Plex installed to render correctly.

The older `docs/img/logo.*` and `icon.*` copies were removed on 2026-08-29; the
pre-rebrand originals are in git: `git show 5c48743:docs/img/logo.png > old-logo.png`.

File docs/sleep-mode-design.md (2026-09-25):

# Sleep mode — design (2026-08-30)

Approved in conversation 2026-08-30. Ships as 1.2.0 (firmware + app).

## What the user sees

When the computer goes to sleep, the screen closes its eyes and dozes; when
the computer wakes, the eyes open and the dashboard returns.

Three clips, drawn by `tools/make_sleepanim.py`, identical for both editions
except ground/ink colour (Claude: terracotta `#cd795a` / black; Codex: steel
blue `#4c82a8` / white):

1. **Closing** (1.5 s, once) — the eyes as the boot left them, then one slow
   eased fall to two thin bars.
2. **Sleeping** (2.5 s, looped) — Zs rise from above the right eye, three in
   the air, periodic in the 2.5 s; the shut eyes breathe a pixel. Replayed end
   to end for as long as the computer sleeps.
3. **Opening** (1.8 s, once) — eyes open, one quick overwatch, dashboard.

Decisions: 30 s of silence before sleeping; normal backlight; no company logo
on wake; a tap while asleep shows the dashboard (last figures, flagged stale)
with the line "Your computer may be asleep" for 10 s, then the loop resumes;
after a shutdown that leaves the port powered, the face sleeps overnight.

## How sleep is detected

Board-side, from silence. The board pings every 10 s and the app answers;
a sleeping computer freezes the app. After **30 s** without an answer, on a
board that has had a good connection this boot, the board enters SLEEP. The
first message from the app (a pong, or a `welcome` from a restarted app)
ends it. No OS-specific code; works for sleep, lid close and hibernate on all
three platforms.

There is a second way in, added after a field report (2026-09-02): **from a
reading that has stopped moving**. The first rule waits for silence, and a
computer that goes to sleep does not necessarily produce any — the daemon on
it kept answering pings all night while the figures it pushed were 57 hours
old, so `host_lost` never armed and the panel sat awake showing "Reading is
old" until morning. So a machine that has said nothing for **4 h**
(`SLEEP_ABSENT_AFTER_S`), on a board that has shown figures this boot, with
no update in flight and with nothing on screen asking for a person (no
waiting, stuck, failed or running session), also enters SLEEP. It leaves as
soon as that machine speaks again — the next `usage` message after somebody
uses Claude Code — or on any of those conditions changing. A tap peeks as it
always did.

"Said nothing" is the wire's `active_age_s`, and it is deliberately not the
same number as `age_s`, which is how old the figure on the dial is. The two
come apart because the daemon re-offers the last five-hour reading it saw at
that reading's own time, so the dial can be twelve hours old five seconds
after Claude Code rewrote the file it came from. Dozing on the dial's age
closed the panel's eyes on an owner sitting in front of it. The wake-time
stale stamp still asks about the dial, because that dot describes the
figure; only the doze asks about the person.

The threshold is argued for in `firmware/src/sleep_gate.h`: above the
daemon's own 1800 s staleness bound and Claude Desktop's 900 s away-schedule
by a wide margin, so a person at the desk is never dozed on; short enough
that a machine sleeping at 23:00 has a dark panel by 03:00.

Edges:
- **Uninstall** sends a `bye` (new protocol message, additive) before stopping
  the service; the board shows "connecting" for that instead of sleeping.
  Restarts (updates) are shorter than 30 s and are not seen.
- **Firmware update in progress** (OTA UI in DOWNLOADING/REBOOTING) suppresses
  sleep: the port is closed for ~75 s while esptool writes.
- **Crash** reads as sleep until the OS restarts the app; the board then wakes.
- **Boards that lose USB power** in sleep simply go dark and boot on wake.
- **Standalone WiFi mode** is untouched: no host, no sleep.
- Before the first good connection, silence is still "connecting" (unchanged).

## Firmware

- `ui_sleep.c/.h`: plays closing once, loops sleeping, plays opening once; owns
  the tap-to-peek (dashboard + hint, 10 s). Uses the existing BAN1 player
  (`ui_boot.c`'s `bootanim_play`, factored to a shared helper) and the same
  `pump()`.
- `usage_freshness.c/.h`: keeps the `age_s`, `active_age_s` and `state` that
  `proto.c` parses somewhere `main.c` can read them and a laptop can test
  them, and grows both ages with uptime between messages. A message with no
  `active_age_s` — a daemon older than the field — gets `age_s` back for it,
  which is exact rather than approximate: the two only differ because of a
  memory that daemon does not have.
- `sleep_gate.c`: `sleep_stale_should_start()` / `sleep_stale_should_wake()`
  are exact complements, pinned by a grid in `tests/sleep_gate`, because one
  lives outside `ui_sleep_run` and the other inside it.
- Clips compiled in as `sleepanim_<edition>_{close,loop,open}.h`, encoded with
  `tools/encode_bootanim.py --frames` from `make_sleepanim.py` output;
  `bootclip.c` picks the edition's set the way it picks the boot clip.
- State: `proto.c` already tracks `last_host_ms` with `HOST_TIMEOUT_MS`
  (35 s → 30 s). New: `proto_host_silent_for_ms()`; `main.c` USB loop enters
  SLEEP when silent > 30 s && host_seen && had_usage && OTA idle; leaves it on
  the next host message. `bye` sets a flag that routes the silence to
  DISCONNECTED ("connecting") instead of SLEEP.
- "Connecting 1/2" screen gains a hint line under the step name: "Connected
  and the app is running? Try another cable." (shown after 20 s on step 1).

## App

- `protocol.bye()`; `cmd_uninstall` stops the service, opens the remembered
  port and sends `bye` before removing files (best effort, 2 s timeout).
- No other change: pongs and `welcome` already exist.

## Tests

- Firmware host test for the sleep state machine (silence/bye/OTA gates).
- `tests/pc`: `bye` on uninstall, protocol shape.
- Hardware: desk board (Claude) and Lenovo board (Codex): sleep the computer,
  watch closing → loop; wake, watch opening → dashboard; tap while asleep;
  uninstall → "connecting".

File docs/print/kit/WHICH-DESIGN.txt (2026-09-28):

PICK ONE. You do not need both.
===============================

upright-frame/     A picture frame. Screen stands vertical.
                   Two parts: front_bezel + back_tray.
                   46.2 mm front to back when assembled.
                   Print the bezel FACE DOWN, the tray OPEN SIDE UP.

wedge/             A slanted screen on a flat base. Newer design.
                   Two parts: v2_shell + v2_base.
                   Everything goes in from underneath, so there is no
                   seam anywhere you look at it.
                   Print the shell ON ITS BACK, the base FLAT.

Neither needs screws. Neither needs supports if printed in the
orientation above.

notes.md in each folder has the exact dimensions, the tolerances, and
the OpenSCAD command to regenerate the STLs if you want to change
anything.

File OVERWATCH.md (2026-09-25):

# Overwatch

A personal fork of [Blink](https://github.com/KfirLevy258/Blink) that adds two
widget pages beside the usage gauges: a Spotify transport and an app launcher
for the Mac mini.

Written September 2026. Read this first if you are coming back to it cold.

## What state it is in

**The computer half is proven. The board half has never been compiled.**

That split is the whole status, and it is worth being blunt about because the
two halves feel equally finished when you read the code and are not.

| | State |
|---|---|
| `pc/widgets.py`, `pc/spotify.py`, `pc/widget_bridge.py` | 32 tests passing, exercised end to end against the real bridge |
| `firmware/src/ui_launcher.*`, `ui_spotify.*`, `ui_pages.*` | Written against the real LVGL 9 and Zephyr APIs in this tree. Never built. Expect compile errors on the first run. |
| The page-stack logic | Modelled and exercised over 17 transitions, in Python. That model is not the C. |

Nothing here has touched a board. There isn't one yet.

## The idea, in one paragraph

OVERWATCH's board already talks back to the computer -- `pref`, `ping`,
`ota_query` and `ota_flash` have gone up the cable since the first release, and
`ota_flash` means a tap on the panel already makes the computer download a file
and reflash the device. Launching an app is a smaller claim on the host than
the product already makes. So the widgets ride the link that exists rather than
adding one.

## The case

`case/` holds a two-part 3D-printable enclosure - the weightlifter holding the
barbell, screen as its body - modelled parametrically in OpenSCAD from the
reference artwork's own proportions. It renders and exports clean STLs and has
never been printed. `case/README.md` carries the detail.

It does not depend on the firmware at all. If the widget build stalls, the case
still prints and still holds a board running upstream's stock firmware.

## The reveal

`reveal/` builds an eight-second product film headless in Blender, from the
same STLs the case prints from - change the SCAD, re-export, re-render.
`reveal/README.md` has the shot breakdown, the knobs, and the four Blender 5
API changes that each cost a debugging round.

## What was added

    firmware/src/ui_launcher.{c,h}   six buttons, app icons, one message each
    firmware/src/icons_gen.h         generated: 6 icons, RGB565A8, 28 KB flash
    tools/encode_icons.py            PNG -> that header
    firmware/src/ui_spotify.{c,h}    now playing, three transport buttons
    firmware/src/ui_pages.{c,h}      the flat page stack and its tap rail
    pc/widgets.py                    slot number -> app, and the ack
    pc/spotify.py                    one osascript call, three commands
    pc/widget_bridge.py              Bridge subclass; no edits to his bridge
    tests/pc/test_widgets.py         14 tests
    tests/pc/test_spotify.py         18 tests

## What was changed in his files

143 lines added, 6 removed, across five files. `git status` still shows it
un-committed on purpose -- that is the clearest view of the fork there is.

- `proto.c` / `proto.h` -- two send functions, three inbound handlers
- `ui_settings.c` -- navigation routed through `ui_pages_can_step()` instead of
  `usage_view_can_page()`, so the vertical swipe walks the longer stack
- `main.c` -- `ui_pages_init()` at three mode sites, `ui_spotify_tick_1s()`
  beside the gauge tick, `ui_pages_detach()` at the deinit
- `CMakeLists.txt` -- three sources
- `prj.conf` -- `CONFIG_LV_USE_IMAGE=y` for the launcher's icons

Everything else is additive. The daemon side is a *subclass*, which is
deliberate: he ships releases on his own cadence, and a fork that patches his
files turns every one of them into a merge conflict.

## Decisions worth not re-litigating

**Overlays, never a second LVGL screen.** `usage_view_deinit()` records why --
with no PSRAM the heap cannot hold two, which is why the settings panel is an
overlay too. A second screen does not fail at build time. It fails as an
allocation returning NULL somewhere in a repaint, once both are populated.

**No new gesture, because there were none left.** Left opens settings, right
replays the boot clip, up and down walk the stack, and both edge strips are
already tap targets. The widget pages are reached by continuing past the end of
the providers -- `usage_view_can_page()` was already the function that knows
where that end is.

**Every navigation has a tap path.** Swipes land about half the time on this
panel and that is physics, not tuning. See `docs/multi-provider.md` 4d before
touching any of it.

**The board sends a slot number, never an app name or a path.** The computer
owns the table. Nothing the panel can say names a program the daemon has not
already agreed to run.

**`tell application "Spotify"` launches Spotify.** The read script is guarded
with `application "Spotify" is running`, which does not. There is a test
pinning that string, because it is the kind of line someone tidies away.

**Spotify's `duration` is milliseconds; `player position` is seconds.** Range-
checked at the parser, which is the only place the unit is known -- the same
way this codebase already handles the desktop cache sitting beside Codex.

## Where to pick up

1. Buy an **ESP32-2432S028R**. The R matters: resistive touch, XPT2046. The
   whole swipe implementation is built around its physics.
2. Toolchain: Homebrew, then **Zephyr 4.3.x and SDK 0.17.4**. Not 4.4.0, which
   cannot build this firmware, and do not register SDK 1.0.1 alongside 0.17.4.
3. Generate your own signing key into `~/.overwatch/`. Your board will then accept
   updates only from you, never from his feed. Back it up off the machine.
4. **Flash his stock firmware first, unmodified.** It separates "can I build
   and flash at all" from "does my code work", and if step 2 was miserable you
   find out without my code confusing the question.
5. Then build this tree. `firmware/README.md` has the exact commands and
   `tools/dev.sh flash` is the loop -- it stops the daemon first, because only
   one process can own the serial port.
6. Point `claude_usage_bridge.py` at `WidgetBridge` instead of `Bridge`.

Known unknowns for the first build: the LVGL symbol names
(`LV_SYMBOL_PLAY`/`PAUSE`/`PREV`/`NEXT`/`UP`/`DOWN`), and whether the rail's
160x40 tap halves are big enough -- 48 px was his measured floor and these are
40. `ui_pages.c` names the remedy if they miss.

## Licence

Upstream is PolyForm Noncommercial 1.0.0 with an added permission. Build as
many as you like for yourself, change them, give them away. **Selling is the
one thing forbidden** -- a unit, a printed case, the software, or any product
whose substantial value is a work based on it. Renaming it Overwatch does not
change that.

If you pass a copy to anyone, `LICENSE` and its `Required Notice:` line go with
it. That is the licence's own requirement, not a courtesy.

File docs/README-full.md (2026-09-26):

<div align="center">

OVERWATCH

**A little desk gauge for your Claude Code and Codex usage.**
Your 5-hour session and 7-day week, as two live dials you can glance at all day.

<p>
  
  
  
  
</p>

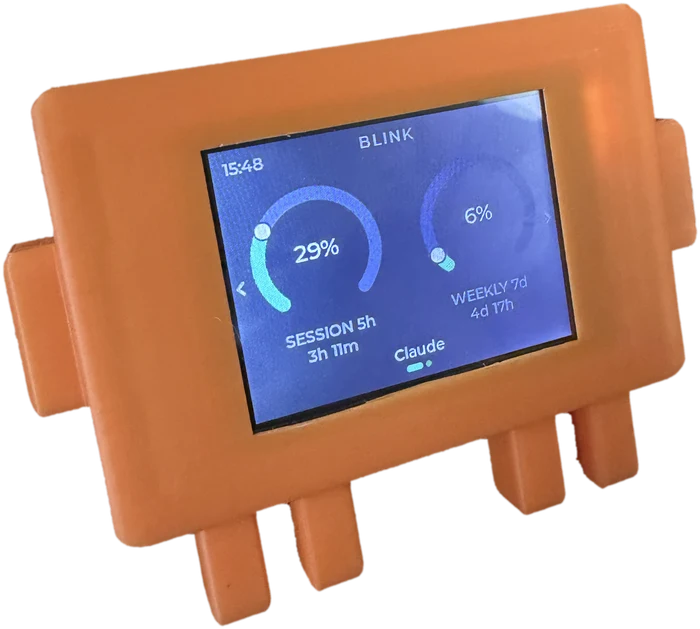
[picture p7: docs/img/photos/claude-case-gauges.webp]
Overwatch in its Claude case, both dials live


</div>

<table>
  <tr>
    <td width="33%">The Claude page: six coloured marks in the top-left corner, one per live session, the clock under the OVERWATCH wordmark, and the session and weekly dials.</td>
    <td width="33%">The Codex page, with its own session and weekly dials.</td>
    <td width="33%">Claude Desktop alone: the session dial shows a fill rate where a countdown would otherwise be.</td>
  </tr>
  <tr>
    <td align="center"><sub><b>Claude</b></sub>&nbsp;</td>
    <td align="center"><sub><b>Codex</b></sub>&nbsp;</td>
    <td align="center"><sub><b>Desktop alone</b></sub>&nbsp;</td>
  </tr>
</table>

Session and weekly, the countdown to each reset, and the time under the wordmark.
The marks in the top-left corner are the live sessions, one per session, coloured
by what each is doing.

*The three screens above are rendered from the shipping firmware's own drawing code (`tools/panel_render`), not mocked up.*

## What is Overwatch?

Overwatch is a small desk display that shows how much of your Claude Code usage you've spent - the same numbers as the `/usage` command, but always in view. It reads your **5-hour session** limit and your **7-day weekly** limit and draws each as a dial, green while you have room, amber as you get close, red when it's nearly gone. Glance over, know where you stand, keep working.

Beside the dials is a small pip telling you whether anything is waiting on you - across every Claude Code and Codex session you have open, one light: amber the moment a session has finished or is asking permission, a green pulse while everything is still working, red when something is stuck or rate-limited. Under them, a countdown to each window's reset.

It runs on a cheap (~$12) ESP32 touchscreen. Plug it into your computer, run the setup once, and it sits on your desk and keeps itself up to date.

### Where the numbers come from

Overwatch never sees a credential and never sends anything anywhere. It reads figures other programs have already worked out, from files they already write, and keeps only the figures: from Codex's session log it takes the one rate-limit line and nothing of the conversation; from Claude Code's status line it keeps the last payload (which also names your working directory and session), readable by you alone.

### What it supports, and how well

| You use | What the panel shows | |
|---|---|---|
| **Claude Code in a terminal** | Everything: both limits, both countdowns, the activity light | **Full** |
| **Claude Code in the VS Code / JetBrains extension** | The same. The extension runs the same CLI and reads the same `~/.claude/settings.json`, so the status line and hooks work identically | **Full** |
| **Claude Desktop, without Claude Code** | Both percentages and how fast the five-hour window is filling, on Desktop's own refresh: about every 5 minutes while it is in use, every 15 (occasionally 30) when it sits idle, and at once when its usage panel is opened. **No countdowns, no activity light** | **Partial** |
| **Codex CLI** | Both limits and both countdowns, on its own page | **Full** |
| **claude.ai in a browser** | Nothing | **Not supported** |

**How current the Desktop figure is.** OVERWATCH never asks the server; it reads the sample Desktop last wrote. Measured over 1,672 samples on one Mac (July-August 2026): Desktop writes one every 5 minutes while it is being used, every 15 minutes in the background (occasionally 30), and immediately when its usage panel is opened. The daemon reads the file every minute, so the board is at most a minute behind Desktop, and Desktop is at most 5-15 minutes behind the server. A person watching the board while the app sits idle sees the figure move in 15-minute steps - reported 2026-08-30 as "stuck on 16 %, then 21 %" - which is the app's clock, not a fault.

**Sleep.** The board pings the app every 10 s. Thirty seconds without an answer, on a board that has shown figures this boot and is not mid-update, means the computer is asleep: the screen plays a closing clip, loops a sleeping one, and plays an opening clip when the app answers again. Uninstall sends a `bye` first so a removed app shows "connecting" instead. Clips: `tools/make_sleepanim.py`; design: `docs/sleep-mode-design.md`.

**Why Claude Desktop is only half.** The five-hour window has a real countdown: Claude Desktop's own Local Storage carries a reset time next to its percentage, refreshed within seconds of a turn. The seven-day window does not - an exhaustive search in August 2026 (every JSON file the app writes, its LevelDB, Session Storage and IndexedDB stores, its caches and its preferences plist) found no seven-day reset time anywhere a chat-only customer's machine writes one. So OVERWATCH remembers one, the first time any source reports it, and counts it forward a week at a time; that countdown is published only while nothing has contradicted it, and withdrawn the moment something does. Wherever a window has no countdown to show, the panel shows a **rate** instead (`+14%/h`) - measured from readings actually taken, not a guessed reset time. The activity light needs Claude Code's hooks, which a machine without Claude Code does not have. `overwatch install` says all of this on a machine in that state rather than reporting four successful steps.

**Why claude.ai is not supported.** A browser extension was built to read usage from response headers and measured against the real site: 178 responses, none carrying a rate-limit header of any kind. There is nothing to read. It was removed rather than shipped as a feature that does nothing. [`docs/next-steps.md`](next-steps.md) §A has the measurement.

### The sources

| Source | Gives | Needs |
|---|---|---|
| Claude Code's status line | both limits, reset times | nothing - set up by `overwatch install` |
| Claude Code's hooks | per-session busy / waiting / finished / rate-limited | nothing - set up by `overwatch install` |
| Claude Desktop's usage cache | both limits, and the burn rate derived from its history | nothing - read if the app is installed |
| Claude Desktop's Local Storage | a five-hour reset time, refreshed within seconds of a turn | nothing - read if the app is installed |
| A remembered weekly boundary | a weekly reset time, once one has been learned from any of the sources above; published only while nothing contradicts it | nothing - learned automatically, never configured |
| Codex CLI's own session log | both limits and reset times, for Codex | nothing - read if Codex is installed |

**How each source is tested.** Claude Code: CI installs real releases (oldest supported, stable, latest, next) and checks the status-line contract is still there. Codex: CI reads the struct that defines `rate_limits` in Codex's own source at the latest release, and fails the day a field is renamed - Codex will not write a log without an account, so the parser is pinned to a real captured log instead. Claude Desktop: a closed app no runner can launch; the parser is pinned to a real captured cache file, and `overwatch status` reports on the customer's machine whether today's file still parses.

When two of them disagree, the most recently observed number wins - field by field, so a source that knows your reset time still supplies it even when a fresher one takes over the percentage. [`docs/multi-provider.md`](multi-provider.md) has the details.

**Two providers get a page each**, rather than sharing the dials. The name at the bottom of the screen says whose numbers you are looking at, and tapping it switches - as does a swipe up or down. Each page carries its own freshness, so a Codex reading that has gone quiet never puts "reading is old" over live Claude numbers. Changing page moves the needles from one reading to the other instead of redrawing the screen, because this is an instrument and that is what an instrument does.

## What's in here

| Path | What's there |
|---|---|
| `firmware/` | The device firmware (Zephyr, C) - this is the product |
| `firmware/src/ota.c` | The update engine: signed install + automatic rollback |
| `pc/`, `claude_usage_bridge.py` | The USB bridge and its setup, shipped as one binary - this is how a board gets its numbers |
| `tools/` | Build, flash, and release helpers |
| `docs/img/` | Logo, icons, and the screen renders above |

## Hardware

Overwatch runs on the **ESP32-2432S028 "Cheap Yellow Display" (CYD)** - a popular all-in-one board with a 2.8" 320×240 touchscreen, for around $12. The common variants all work.

**Get the board:** [search AliExpress for "ESP32-2432S028"](https://www.aliexpress.com/w/wholesale-esp32%2D2432s028.html)

### Enclosure

A 3D-printable case gives the bare board a home on your desk. **[Download the CAD files](#)** *(coming soon)*

## Connecting it

Overwatch reads your usage over the **USB cable**, from Claude Code itself. Plug the board into your computer and run the setup below; your usage streams over the cable, and the same connection handles updates.

The device never joins your network, never signs in to anything, and never holds a credential - the numbers come from the Claude Code already running on your machine.

**Which port, and what if you have two boards.** It does not scan. The daemon
writes down the board it connected to, so every later start opens that port
directly.

On a machine that has never seen a board — a new install — there is nothing to
remember, so it identifies one by asking. It shortlists ports by USB-serial
chip id, then asks each politely: a short message the board answers and
nothing else does. If none answers quickly it goes round once more listening
for longer, because a board plugged in seconds ago may still be booting and
will send an unprompted ping shortly. Only then does it stop. That matters because the CH340 in these boards is also in a great deal
of hardware that is not one. A device that stays silent is left alone
**permanently**: the daemon then waits for something to be plugged or
unplugged rather than reopening ports on a timer, so a stranger's Arduino is
opened once and never poked again.

Only a board it has identified before may be reset. That is the recovery a
genuinely wedged unit needs, and it is precisely the thing an unknown device
must never be given.

### Windows: the driver the shortlist depends on

All of the above enumerates **serial ports**. On Windows the CH340 does not
become one until a driver is installed, and Windows has never shipped that
driver — so a customer's board sat in front of them showing the setup wizard
while `overwatch status` said `Board not plugged in`, which was the one thing that
was definitely untrue (2026-09-06). Windows knew about the device the whole
time; it was just not reachable through anything that lists COM ports.

`overwatch install` now stages WCH's driver into Windows' driver store with
`pnputil /add-driver /install`, which is the one step that raises a Windows
permission prompt — and it raises it only when there is genuinely something to
install, so a re-run on a healthy machine is silent. A board plugged in
afterwards binds to the staged driver with no prompt at all. `overwatch driver`
does the same thing on demand, for anyone whose install predates this or who
declined the prompt.

Separately, and for free: `pc/win_driver.py` asks Windows' configuration
manager directly, so `overwatch status` and `bridge.log` distinguish an empty desk
from a board Windows cannot use, and name which it is. That half needs no
administrator and no bundled driver, so it works even in a build carrying
neither.

What it asks for is worth recording, because the obvious question is the wrong
one. An undriven board does **not** carry a problem code. Measured on the
Windows 10 release desk with the driver package deleted and the machine
rebooted so the board enumerated fresh: the device reported problem 0, and
`pnputil /enum-devices /problem` reported "No devices were found on the
system", while there was no COM port and no way to reach the board at all.
Windows does not treat a device with no function driver as broken — it is
simply a device that does nothing. The first version of this module keyed on
`CM_PROB_FAILED_INSTALL`, reasoning from the yellow triangle a customer had
described, and reported that desk as healthy.

So the signal is that no driver is **bound**: the devnode has no Service.
Problem codes still count — a device really can be disabled, or fail its
install, which is the shape the customer's machine was in — but they are the
rarer half.

The driver itself lives at `vendor/ch341ser/`, and its README records where it
came from and how to replace it. It is bundled into the Windows build only —
the other two platforms would be carrying a Windows `.sys` around for nothing —
and a Windows build that cannot find it **fails** rather than quietly producing
a download that cannot set up a board. That guard exists because the only
symptom downstream is a single line of `overwatch install` output.

Detection does not depend on any of it. A build carrying no driver still names
the problem and points at the vendor's download, which is what `overwatch status`
does on a machine where the install was declined.

**One daemon drives one board.** With several attached, the first that answers
wins and the others are ignored — the protocol, the board-side preference and
the update path are all written around a single unit. Name a specific one with
`overwatch run --port /dev/cu.usbserial-XXXX`. A second daemon on the same machine
waits rather than fighting for the port, and says so.

### Setting it up

**One file. Download it, run it, done.** No Python, no package manager,
nothing to keep installed.

```bash
# macOS (Apple silicon)
curl -fsSL https://github.com/SleepyUnicon/Overwatch/releases/latest/download/overwatch-macos-arm64.tar.gz | tar xz && ./overwatch/overwatch
# macOS (Intel):  .../overwatch-macos-x86_64.tar.gz
# Linux:          .../overwatch-linux-x86_64.tar.gz

```

That is the whole setup. It finds the board by itself and starts again every
time you log in - plug the cable in and the panel comes up.

**Then delete the file.** It copies itself to `~/.overwatch/bin` on the way
through, so nothing has to stay in your Downloads folder.

```bash
~/.overwatch/bin/overwatch status      # is the panel getting data?
~/.overwatch/bin/overwatch uninstall   # put everything back
```

*Downloading with `curl` rather than a browser is deliberate: macOS marks
browser downloads as quarantined and refuses to run them until the app is
notarised. `curl` does not, so this works today. See
[notarisation.md](notarisation.md) for what it would take to make the release
page's download work too.*

**Needs Claude Code 2.1.100 or newer.** Overwatch reads the usage figures from
the status line, and older versions do not put them there - 2.1.0 has no
usage figures in that payload at all, so the panel would stay blank. Update
Claude Code first if yours is older.

### What the installer changes

Over USB, Overwatch reads the usage figures Claude Code has already worked out,
rather than asking Anthropic for them itself. Claude Code hands those figures
to whatever command is set as its **status line**, so that is the one setting
Overwatch has to change.

| | |
|---|---|
| Changes | two keys in `~/.claude/settings.json`: `statusLine.command`, and one entry under `hooks` for each of ten Claude Code lifecycle events (`SessionStart`, `PreToolUse`, `Stop`, ... - the activity light is derived from them). Your own hooks are left in place |
| Creates | `~/.overwatch/` (readable by you alone) - a copy of the program, the status line script, the hook script, and a `state/` directory holding one small file per open session (event name, time, and the session and agent ids Claude Code generates - nothing else) |
| Creates | a login item, so the bridge starts with your session (a LaunchAgent on macOS, a user systemd unit on Linux, a Scheduled Task on Windows) |
| Leaves alone | every other key in `settings.json`, and the file's own formatting and permissions. Nothing is installed system-wide |
| Keeps | the last status line payload Claude Code sent, in `~/.overwatch/statusline.json`. Alongside the two usage figures it carries the session id, working directory and transcript path; only the figures are read, and nothing in it leaves the machine |
| Reads | Claude Desktop's usage cache and the tail of Codex's session log, when present; from each only the usage figures are kept. No credential, no token |

**It does this without asking**, so that plugging the board in is the whole
setup. It prints all of the above before it changes anything, and every part
of it is reversible:

```bash
~/.overwatch/bin/overwatch uninstall
```

**If you already have your own status line, it keeps working.** Overwatch records
your existing command, and runs it after capturing the usage figures - your bar
renders exactly as before. Uninstalling puts your command back unchanged, and
will not touch a status line Overwatch did not install.

## Programming a unit

If you are building a unit to ship, this is the whole job:

```bash
tools/burn-claude.sh          # or tools/burn-codex.sh
```

It finds the board, refuses a fused chip (this path writes plaintext, which a
fused ROM cannot read), builds signed with MCUboot, flashes **both** images,
boot-verifies, stamps the edition, then reboots and confirms the stamp
survived. It stops the local daemon for the duration and puts it back
afterwards, including on Ctrl-C.

The edition is **write-once**. Stamp every unit, not just Codex ones — `0`
means both "Claude" and "never stamped", so an unstamped Claude board can be
turned into a Codex one by anyone with a cable. A re-burn of the same edition
passes and says so; a burn of the *other* edition fails and tells you what the
unit already is. A unit programmed before the latch existed arrives **latched
as Claude** the first time it boots this firmware - every unit built before
it was a Claude unit, and the alternative was delivering all of them
re-stampable by their owners. A bench board meant to become Codex needs its
config partition erased first (`esptool.py erase_region 0x3b0000 0x30000`).

Pass `--port` to name a board when more than one is attached, and `--no-build`
to reuse the last build.

**What it flashes is not the release artifact.** `zephyr.signed.bin` is signed
but not *confirmed*: its MCUboot trailer says "boot this once". That is right
for OTA, where the image lands in slot 1 and the firmware confirms it after it
proves itself, and wrong for a direct flash - a board on the bench has no
daemon and no network, never becomes healthy, and reverts at 90 seconds. On a
blank unit that is invisible, because there is nothing to revert to; on a
re-burn it silently undoes the flash minutes after the script printed PASS.

So `tools/sign_confirmed.py` re-signs the same image with `--pad --confirm` and
that is what goes to the board. It reads the signing parameters out of the
build's own `build.ninja` rather than repeating them, and it checks the trailer
it produced - an image that comes back with `image_ok` unset fails the burn
before esptool is called. Measured on hardware 2026-09-07: a confirmed image's
uptime runs straight through the 90-second deadline, where the unconfirmed one
rebooted.

### Company units

A unit sold to a company shows the company's logo after the boot animation:

```bash
tools/burn.sh --edition claude --logo acme.png     # a still, held for 3 s
tools/burn.sh --edition claude --logo acme.bin     # a clip built by tools/encode_logo.py
```

`--logo` takes a picture (scaled to fit the screen), a short video, a folder of
320x240 frames, or a `.bin` already built with `tools/encode_logo.py` (which
also previews one as a GIF: `--info acme.bin --preview acme.gif`). The logo is
written to its own flash partition in the same call as the firmware, and the
boot check insists the board saw it. It is a clip in the boot animation's own
format, so a still costs a few KB and a 3-second animation a couple of hundred;
the partition holds 512 KB.

There is no flag to set: the partition **is** the flag. A unit that never had
one written boots as an individual unit, and a burn *without* `--logo` erases
the partition, so a re-burned board is an individual unit again. Nothing over
USB can change it - like the edition, it takes esptool with the board in
bootloader mode - but unlike the edition it is not write-once, because a logo
is a fact about the customer, not the enclosure. OTA never touches it: the
firmware slots and the settings partition are exactly where they were.
Edition and logo are independent - a company unit is still a Claude or a
Codex one.

### Tested without a board

`tests/ci/check_factory.sh` runs both scripts, unmodified, on every push: it
puts stub `esptool.py` / `espefuse.py` / `espsecure.py` on the PATH that
record their calls, and a fake `serial` module that plays a board - it
replays a boot transcript on every reset and answers the edition message.
Eleven scenarios cover what matters on a production line: the images and
addresses of an individual burn and a company burn, that the logo partition
is erased when no logo was asked for, that a fused chip is refused, that a
board which cannot see the logo it was given (or shows one it should not
have), a wrong edition, a stale build, or a flash that dies mid-way each end
in `FAILED` rather than a boxed unit. Run it locally with
`sh tests/ci/check_factory.sh` (needs numpy and pillow).

## Build &amp; flash by hand

You only need this to put firmware on a board yourself (after that, it updates over the air). It uses the [Zephyr](https://zephyrproject.org/) toolchain.

The default build is what ships: USB only, with no radio, no sign-in and no token store compiled in. The on-device Wi-Fi path is still here and still builds - add `-DEXTRA_CONF_FILE=wifi.conf` to the command below - it is simply not in anything released.

```bash
. tools/lib_zephyr.sh && overwatch_zephyr_activate   # finds the workspace itself

cd firmware
west build --sysbuild -d build-sb -b esp32_devkitc/esp32/procpu . \
  -- -DSB_CONFIG_BOOTLOADER_MCUBOOT=y -DUSE_CCACHE=0 \
  -DSB_CONFIG_BOOT_SIGNATURE_KEY_FILE="\"$HOME/.overwatch/ota_signing_key_p256.pem\""

# Which flash path you need depends on the board -- stock CYDs are unfused,
# and the two kinds cannot boot each other's images:
espefuse.py --port <port> summary | grep FLASH_CRYPT_CNT   # odd bits set = encrypted

# Unfused board -- two commands, because west flash writes only the app at
# 0x20000 and leaves MCUboot at 0x1000 untouched:
west flash -d build-sb --esp-device <port> --esp-baud-rate 115200
esptool.py --port <port> --baud 115200 write_flash 0x1000 build-sb/mcuboot/zephyr/zephyr.bin

# Fused board (flash-encryption eFuses burned) -- the script re-checks the
# chip itself and refuses one it would leave dark:
../tools/flash_encrypted.sh
```

Full details - the signing key, the encrypted-flash setup, and the release flow - are in **[firmware/README.md](../firmware/README.md)**.

## Updates

Overwatch is two halves that ship as one release: the firmware on the board, and the app on your computer. They always carry the same version number.

Overwatch checks for a new release as soon as it starts up, and if it finds one it asks you - **Update now** or **Later** - right on the gauge screen. One tap installs both halves. If the release also carries a newer app, the screen says so, and that half goes first: the new app is what knows how to drive the new firmware.

The board has no network of its own, so the app does the work. It downloads the release, checks it against the hash the release publishes, and writes it over the same cable - then reads it back off the chip to confirm what landed there. The screen goes dark for about four minutes while that happens; it tells you first, and comes back on the new version. Because this route writes the running slot directly it has no automatic rollback, which is a fair trade when the machine that can reflash it is the one already plugged in.

You get a confirmation on screen once the new version is up.

**Updating the app on your own.** You can also run it yourself:

```sh
~/.overwatch/bin/overwatch update     # fetch and install a newer app
~/.overwatch/bin/overwatch status     # which versions are you on?
```

The settings screen shows both versions, and says **App is old** when the half on your computer is the one that is behind.

Automatic app updates are off unless a release turns them on. To keep them off whatever a release says, `touch ~/.overwatch/no-auto-update`.

**Both halves are signed, by two separate keys.** Firmware images are signed with a key only you hold, and the bootloader rejects anything else - so nobody can push firmware to your device, not by forking this repo, not by uploading a release, even though the repo is public. The release manifest that drives app updates is signed with a second key, and the app refuses to read a manifest that does not verify. Two keys rather than one because they protect different things, and one compromise should not be two.

## Decisions

The things that were open before the first release, and how each was settled.

| | Decision |
|---|---|
| **Name** | **OVERWATCH.** The panel, the app (`overwatch`), its directory (`~/.overwatch`), the login service and this repository all say it. Earlier names (Clauge, "Claude usage") are gone. |
| **Editions** | Two - Claude and Codex - from **one firmware image**, chosen by a write-once stamp at the factory (`tools/burn-claude.sh` / `tools/burn-codex.sh`). Never user-changeable; a unit from before the stamp existed arrives latched as Claude. |
| **Company units** | The same image plays a company logo (a still or a short clip) after the boot animation when the factory wrote one to the `logo` partition (`tools/burn.sh --logo`). No logo partition, no logo: individuals are the default, and a re-burn without `--logo` erases it. |
| **One board per computer** | The app drives one OVERWATCH. A second one attached is ignored; `--port` picks one deterministically. |
| **What is supported** | Claude Code in a terminal or IDE extension: everything. Codex CLI: everything, on its own page. Claude Desktop alone: a five-hour countdown whenever Desktop is holding a reset time - it keeps one only while a window is running and clears it in between, so the countdown comes and goes and the fill rate covers the gaps - a weekly countdown once one has been learned, and no activity light. claude.ai in a browser: nothing. |
| **Automatic app updates** | **Off** for the first release. The signed manifest carries the switch (`daemon.auto`), so it can be turned on for a later release - and off again within minutes - without touching any installed machine. |
| **What the app keeps on disk** | Exactly what the table under "What the installer changes" says, readable by the user alone, sent nowhere. |
| **Not yet** | macOS notarisation. The pipeline is written and CI calls it (`tools/macos_sign.sh`, `tools/macos_notarize.sh`); it is dormant until six repository secrets exist, which needs a paid Apple Developer account. Until then the binary is unsigned beyond PyInstaller's ad-hoc signature and Gatekeeper refuses a BROWSER download of it -- the `curl` install line is unaffected and always was. See [notarisation.md](notarisation.md), which also records why the hardened runtime cannot simply be switched on. Apple Silicon runs the full suite and the real installer in CI, but has not yet been watched by a person. (Windows has: a real Windows 10 PC with a Hebrew user name, 2026-08-29 - which found four things that CI's ASCII English runners could not, fixed in 1.0.3 and 1.0.4.) **Claude Desktop's cache location has only been seen on macOS**; on Windows (`%APPDATA%\Claude\`) and Linux (`~/.config/Claude/`) it is the Electron convention, and `overwatch status` prints the path it looked at so the first person beside a signed-in Desktop there can confirm it in one glance. |

## Security &amp; privacy

- **Only you can update your device.** Firmware must be signed with your private key (kept off this repo, at `~/.overwatch/…`); the bootloader rejects anything else. App updates must be signed with a second key of yours, or the app will not install them. The public repo only lets people read and download the firmware, which holds no secrets.
- **The device holds no credential.** It never signs in and never talks to Anthropic. The figures come from the Claude Code on your own machine, which has already worked them out, and reach the board over the cable. There is no token on the device to leak, and nothing to revoke if you sell or lend it.
- **The setup touches one file.** `~/.claude/settings.json`: its `statusLine.command`, and a hook entry per lifecycle event - see "What the installer changes" above for exactly what is written and what is kept. All of it is reversible with one command.
- The on-device Wi-Fi and sign-in path still exists in this repository, behind `CONFIG_OVERWATCH_WIFI_MODE`, but is **not built into shipped firmware** - the release script refuses to publish an image containing it.

## The status dot

A small dot in the top-right corner is one light for the whole desk: what
your sessions need from you, across Claude Code and Codex together, worst one
wins.

| Dot | Meaning |
|---|---|
| 🟢 green, pulsing | Everything is working; nothing needs you |
| 🟠 amber | **Your turn** - a session has finished its answer (Claude or Codex), even if others are still working |
| 🟠 amber, pulsing | A session is asking permission right now |
| 🔴 red | A turn died on an API error - a rate limit shows here |
| 🟢 green, steady | Connected, live data, no session has anything to say |
| ⚪ grey | Not connected |

Stale numbers also show amber, with "Reading is old" on the page: the last
good reading is kept on screen because Claude Code has not refreshed it
recently, or the window it describes has since reset.

"Your turn" is deliberately ranked above "working": a finished answer is
waiting on you, and the sessions still running are not, so one finished
session shows through any number of busy ones. A terminal you opened and have
not typed into claims nothing, and neither does one that has ended. Codex has
no hook interface, so its state comes from its own session log: a turn that
started, finished or was interrupted. Codex permission prompts are not in that
log, so a prompt shows as "working" until you answer it.

## Support

`~/.overwatch/bin/overwatch status` first: it names the service state, every source it
reads and the age of each reading. Then a replug of the board. If neither
helps, open an issue on this repository with that output
and the tail of `~/.overwatch/bridge.log` (neither contains a credential or any
message text).

Every line in that log carries the local date and time it was written. The
file is capped at 4 MB and the four previous ones are kept beside it as
`bridge.log.1` through `bridge.log.4`, so it uses at most 20 MB and holds
something over a month on a busy machine - one customer's reached 2 MB in a
week, growing without any limit at all, before this existed. If the problem
you are reporting is older than the log, send `bridge.log.1` too.

The daemon does not write a line for every message it sends. The board's
10-second keepalive is counted rather than printed, and a usage reading that
repeats what the previous one said is held back; both are reported as a count
every ten minutes. So a quiet stretch in the log means a quiet desk, not a
daemon that stopped.

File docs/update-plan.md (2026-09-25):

# Update plan: one release, two artifacts

Status: **implemented** on 2026-08-22, branch `credential-free-usage-source`.
Written as a plan, kept as the record of why it is shaped this way.

Covers three asks: a real self-update path for the daemon, a version
compatibility check on both sides of the serial link, and SHA-256 verification
of what we flash.

## What shipped, and where the plan was wrong

All four workstreams landed. Three things the hardware or the machine changed:

- **No baud escalation.** §2 planned to raise the flash speed to pay for the
  read-back. The CYD's CH340 fails at 460800 -- three consecutive attempts died
  with "Invalid head of packet" immediately after the baud change, while the
  same transfer at 115200 moved 1 MB cleanly in 96 s. A failed read is free; a
  failed *write* leaves a slot0 that will not boot. So the read-back stays and
  the speed does not move, which makes an update take about four minutes rather
  than two -- and the board's on-screen promise was corrected to match.
- **The self-test needs a generous timeout.** 60 s looked ample for
  `overwatch --version` (about 2 s of CPU). Measured at 97 s on a machine under
  load average 89, which is exactly when someone might run an update. Timing
  out means refusing a good release, so it is 300 s.
- **CI cannot sign.** §4.5 assumed the workflow could assemble the manifest.
  It cannot: the release key stays on one machine, so `tools/release.sh` builds
  and signs the manifest locally after downloading what CI published, and
  `release-binaries.yml` lost its `release: published` trigger -- that trigger
  would have rebuilt the binaries after signing, and PyInstaller output is not
  reproducible, so every daemon would have refused its own release.

Verified on hardware: board at 0.6.0, daemon at 0.6.0, `[proto] host connected:
app 0.6.0, protocol 2`, usage flowing, OTA check answering correctly against
the live feed.

---

## 0. What is true today

Facts, with references, so the plan below is not arguing against a strawman.

| | |
|---|---|
| One release carries both | `tools/release.sh` tags `v<version.h>` and attaches `overwatch-fw.bin` + `manifest.json`; publishing fires `release-binaries.yml`, which builds the four PyInstaller binaries **from the same tag** and attaches them. |
| Firmware updates | Board emits `ota_query{cur}` (`proto.c:148`) → daemon compares against `releases/latest/download/manifest.json` (`bridge.py:97`) → `ota_avail` → user consents on the panel → `ota_flash` → daemon runs esptool against slot0 (`ota.py:148`). |
| Daemon updates | **None.** No version constant, no check, no `update` subcommand. |
| Protocol version | `PROTO_VERSION 2` (`proto.c:20`) and `VERSION = 2` (`protocol.py:9`). Both sides stamp `"v"` on every message. **Neither side ever reads it.** |
| Daemon version on the wire | `Bridge(app_ver="0.3.0")` — a hardcoded default that matches nothing. The board prints `[proto] host connected` and discards it. |
| SHA-256 | The manifest's hash crosses to the board in `ota_avail` and is stored in `ota_m.sha256`, but in USB mode **nobody hashes the bytes**. `_on_ota_flash` checks `len(blob)` only (`bridge.py:127`). `ota.c`'s hashing is the WiFi path, now compiled out. |
| Safety net when flashing | MCUboot's signature check at boot. Slot0 is written in place, so there is no test-boot and no auto-revert (stated at `proto.c:132`). |
| Stale claim | `pc/ota.py`'s module docstring still says "the board re-hashes what it received". That stopped being true when the transfer moved to esptool. |
| Board-side stall | There is no timeout on `OTA_UI_DOWNLOADING`. If the daemon dies mid-flash the panel sits on "keep it connected" forever. |

The asymmetry that matters commercially: **firmware auto-advances and the
software that drives it never does.** `RELEASE_BASE` is pinned to `/latest/`,
so a binary a customer downloaded a year ago will happily fetch and flash
today's firmware.

---

## 1. Load-bearing decisions

**D1 — one version number for the pair.** A release is `X.Y.Z` and both
artifacts carry it. Firmware and daemon do not get independent version lines.
This is a locked release train, not a library ecosystem; two version axes buy
flexibility we do not want and a test matrix we cannot afford.

**D2 — `PROTO_VERSION` is a capability floor, not a wire-format switch.**
Protocol changes are additive: new fields, ignored by anything that does not
know them (`msg_get_*` already ignores unknown keys). `v` only increments for a
change that genuinely breaks an older peer. This keeps the compatibility check
below to two rules instead of a matrix.

**D3 — manifest changes are additive, from launch onwards.** `version`, `size`
and `sha256` sit at the top level and mean *firmware*. Nothing is installed
anywhere yet, so that shape is still a free choice — **the last moment it is
one is the first release**. After that, an app on someone's machine is reading
those keys and they cannot move without stranding it, since a stranded app is
exactly the thing that cannot be reached to be fixed.

**D4 — consent stays on the board.** The panel is where the customer already
approves an update. A pair update is one tap there, not a separate thing to
discover on the computer.

**D5 — the daemon updates itself by replacing its binary and letting the
supervisor restart it.** launchd `KeepAlive` + `ThrottleInterval 10` and
systemd `Restart=always` + `RestartSec=10` both do this for free. Windows does
not — `schtasks /sc onlogon` has no restart-on-exit — so the Windows path
re-launches explicitly before exiting.

**D6 — sign the daemon manifest.** The firmware has a signature chain: a
compromised GitHub account cannot push an image the bootloader will run. The
daemon has nothing — it is a login agent, on a customer's machine, updating
itself from a URL. That gap should not ship. Details in §4.5.

---

## 2. Workstream A — SHA-256 (small, independent, ship first)

1. `pc/bridge.py::_on_ota_flash` — after the size check:
   ```python
   digest = hashlib.sha256(blob).hexdigest()
   if digest.lower() != self._manifest["sha256"].lower():
       self._ota_reset()
       self._write(protocol.ota_error("sha256 mismatch"))
       return
   ```
2. `pc/ota.py::flash` — optional second gate: run `esptool verify_flash
   0x20000 ` after the write. Catches a bad write before the board reboots
   into it. Costs ~20 s on a 1.3 MB image; worth it, since the failure mode it
   catches is a device that will not boot.
3. Fix the false claim in `pc/ota.py`'s module docstring.
4. `firmware/src/ui_settings.c` — surface `ota_error`'s `why` in the failure
   notice instead of collapsing every cause into "Update failed". The board
   already receives it; `proto.c:275` throws it away.
5. `firmware/src/ota.c` / `ui_settings.c` — time out `OTA_UI_DOWNLOADING`.
   Over USB the board gets no progress messages at all, so the timeout must be
   generous: no host message for 5 minutes → `OTA_UI_FAILED`.

Tests: `tests/pc/test_bridge.py` — mismatch refuses and reports; match still
flashes; a manifest with an uppercase hash still matches.

---

## 3. Workstream B — version diff on both sides

### 3.1 One source of truth per side

- New `pc/version.py`: `RELEASE_VERSION = "0.6.0"`, `PROTO_VERSION = 2`.
  `pc/protocol.py` imports `PROTO_VERSION` rather than defining its own `VERSION`.
- `firmware/src/version.h` keeps `OVERWATCH_FW_VERSION`; move `PROTO_VERSION` there
  from `proto.c:20` so one header answers both questions.
- New `tests/ci/check_versions.sh`: greps both files, fails if
  `RELEASE_VERSION != OVERWATCH_FW_VERSION` or the two `PROTO_VERSION`s differ.
  Runs in CI **and** as the first thing `tools/release.sh` does.

### 3.2 Put the real numbers on the wire

- `Bridge.__init__` takes `app_ver=version.RELEASE_VERSION` — delete the
  `"0.3.0"` default outright rather than updating it, so it cannot rot again.
- `welcome` already carries `v` and `app_ver`. Nothing new needed on the wire in
  this direction.
- Board `hello` already carries `fw` and `v`.

### 3.3 The two rules

Read `v` on both sides and act on exactly two cases:

| Case | Meaning | Behaviour |
|---|---|---|
| `welcome.v < board PROTO_VERSION` | The computer's app is older than the firmware | Board: persistent settings notice "The Overwatch app on your computer is out of date", plus the update badge. Usage keeps flowing — that path is proto-stable. |
| `hello.v > daemon PROTO_VERSION` | Same thing, seen from the daemon | Daemon logs it once and **refuses to offer firmware updates**: it cannot safely drive a board it does not understand. `ota_query` gets `ota_none`. |

The reverse (daemon newer than board) is the normal upgrade path and needs no
special handling under D2.

### 3.4 Refuse to flash across a floor

`manifest.json` gains `fw.proto_min`. `_on_ota_query` will not offer an image
whose `proto_min` exceeds the running daemon's `PROTO_VERSION`; it logs
"firmware 0.7.0 needs a newer app" and — once Workstream C lands — offers the
daemon update instead. This is what stops a year-old binary from flashing a
firmware it cannot talk to.

### 3.5 Show it

Settings panel gains a line: firmware version *and* app version (from
`welcome.app_ver`). Cheapest support tool we will ever build.

---

## 4. Workstream C — daemon self-update

### 4.1 Manifest v2

Additive, per D3. Old daemons keep working because the first three keys never
change meaning.

```json
{
  "version": "0.6.0",
  "size": 661744,
  "sha256": "<firmware>",

  "schema": 2,
  "fw":     { "proto_min": 2 },
  "daemon": {
    "version": "0.6.0",
    "proto": 2,
    "auto": false,
    "artifacts": {
      "macos-arm64":       { "size": 11917888, "sha256": "..." },
      "macos-x86_64":      { "size": 11901234, "sha256": "..." },
      "linux-x86_64":      { "size": 11550000, "sha256": "..." },
      "windows-x86_64.exe":{ "size": 12100000, "sha256": "..." }
    }
  }
}
```

`daemon.auto` is a server-side kill switch: ship with `false` (manual updates
only), flip to `true` once the path has proven itself, flip back within minutes
if a release goes wrong. That switch is the reason to build auto-update at all —
without it, auto-update is a mechanism with no brake.

### 4.2 New module `pc/update.py`

- `platform_key()` → `macos-arm64` | `macos-x86_64` | `linux-x86_64` |
  `windows-x86_64.exe`, from `platform.system()` + `platform.machine()`.
  Note: an Intel binary under Rosetta reports `x86_64`, which is correct — we
  want the artifact matching the *running process*, not the silicon.
- `check(manifest)` → `(available: bool, version, artifact)` using the existing
  `ota.is_newer`.
- `download_and_verify(url, size, sha256)` → bytes; raises on either mismatch.
- `apply(blob) -> (ok, message)`:
  1. write `~/.overwatch/bin/overwatch.new` (same directory, so the replace is atomic)
  2. `chmod 0755`
  3. **run `overwatch.new --version` and require it to print the expected version.**
     Non-negotiable: this is a login agent. A corrupt binary that gets as far as
     being the service's target is a device that never comes back and a customer
     who has to start over. A 200 ms self-test buys that away.
  4. `os.replace(installed_bin(), installed_bin() + ".old")` — required on
     Windows, harmless elsewhere; `_make_way_for_copy()` in `cli.py` already
     does this dance and should be reused
  5. `os.replace(overwatch.new, installed_bin())`
  6. restart (§4.3)
- Rollback: a failure at 1–3 deletes `.new` and changes nothing. A failure
  between 4 and 5 leaves `.old` in place; `cmd_run` and `cmd_status` gain a
  `_recover_from_old()` that restores it when `installed_bin()` is missing or
  zero bytes. `.old` is cleaned up on the next successful start.
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

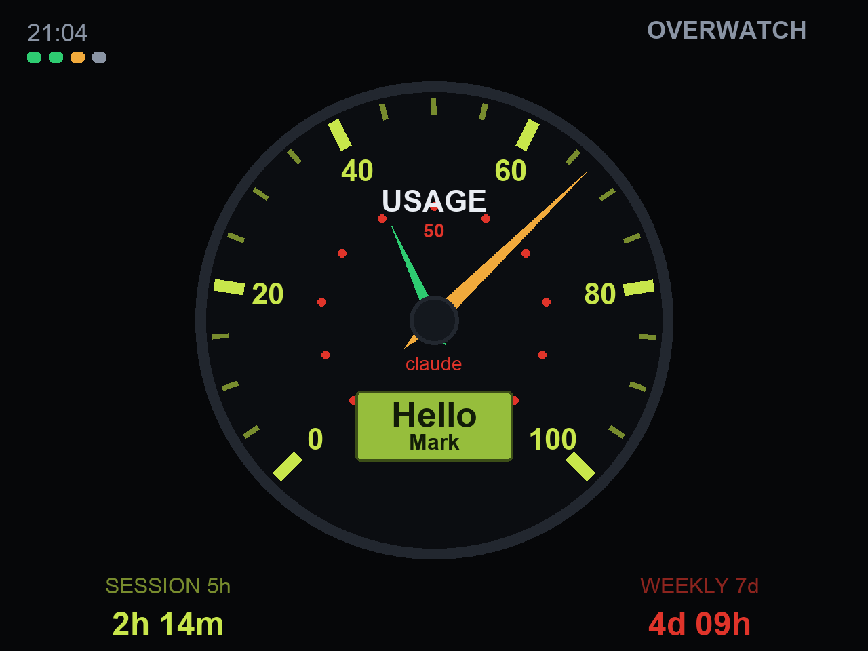
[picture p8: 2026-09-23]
design/car-dial/dial_mockup.png

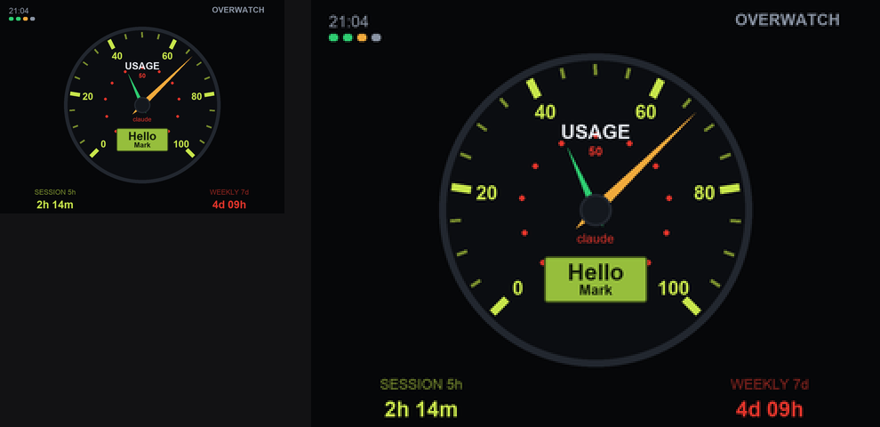
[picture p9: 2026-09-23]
design/car-dial/dial_compare.png

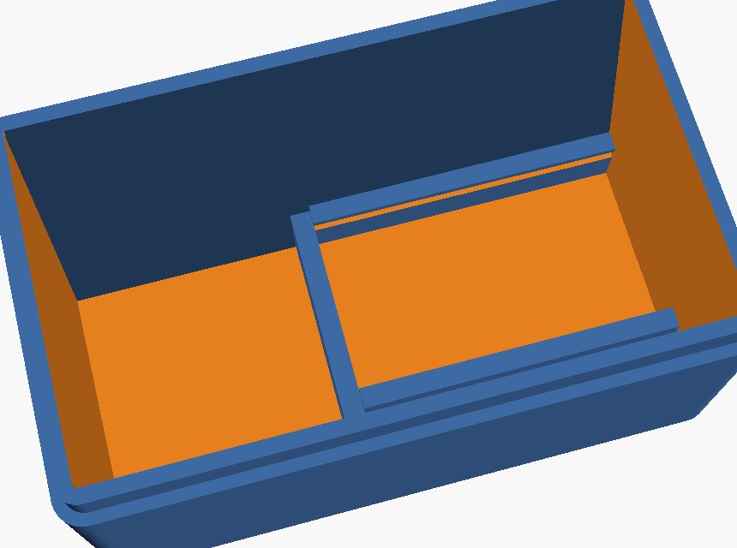
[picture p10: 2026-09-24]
case/3_tray_inside.png

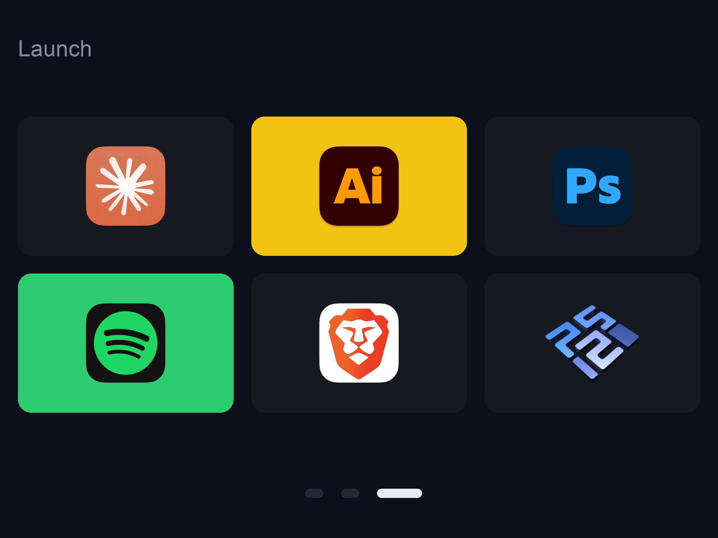
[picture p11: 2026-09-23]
reveal/page_launcher.png

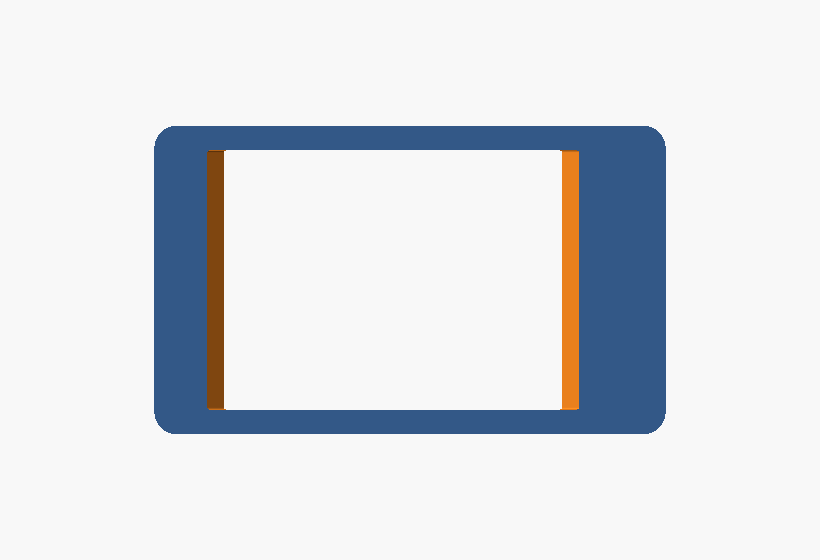
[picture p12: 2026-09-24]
case/1_bezel_face.png

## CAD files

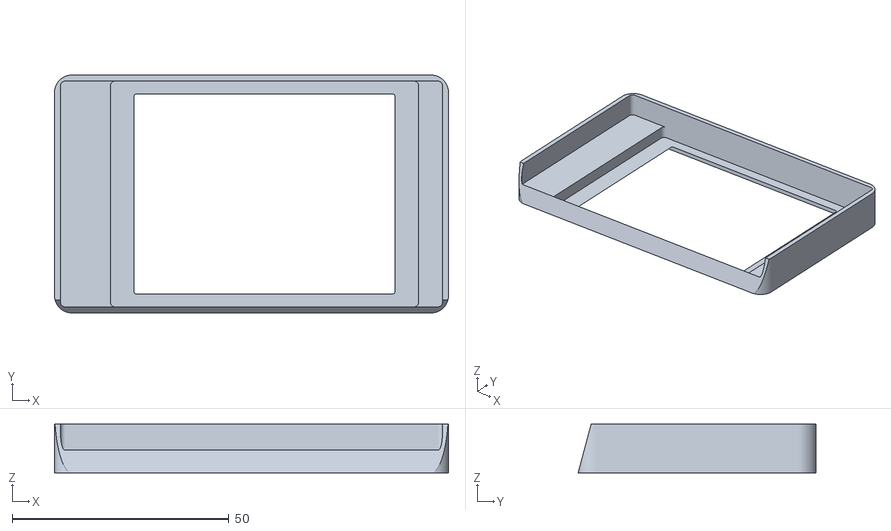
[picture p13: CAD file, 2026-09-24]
case/front_bezel.stl
90.8 x 54.8 x 11.2

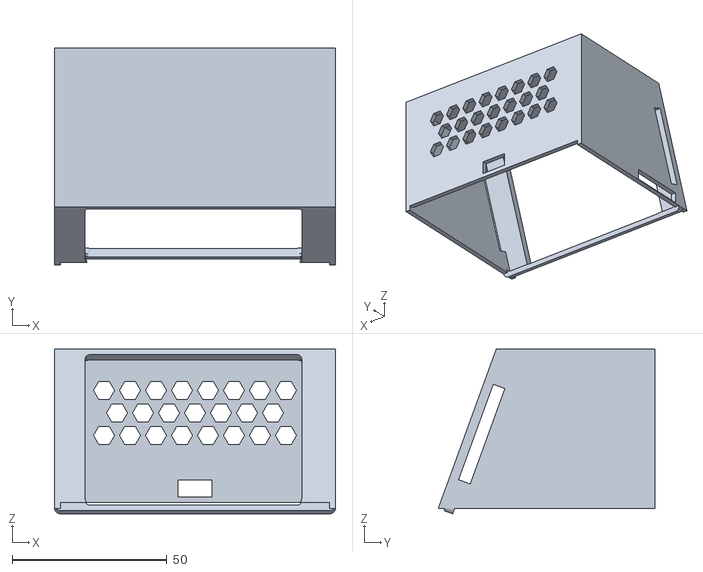
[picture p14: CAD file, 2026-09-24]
case/v2/v2_shell.stl
90.8 x 70.0 x 53.2

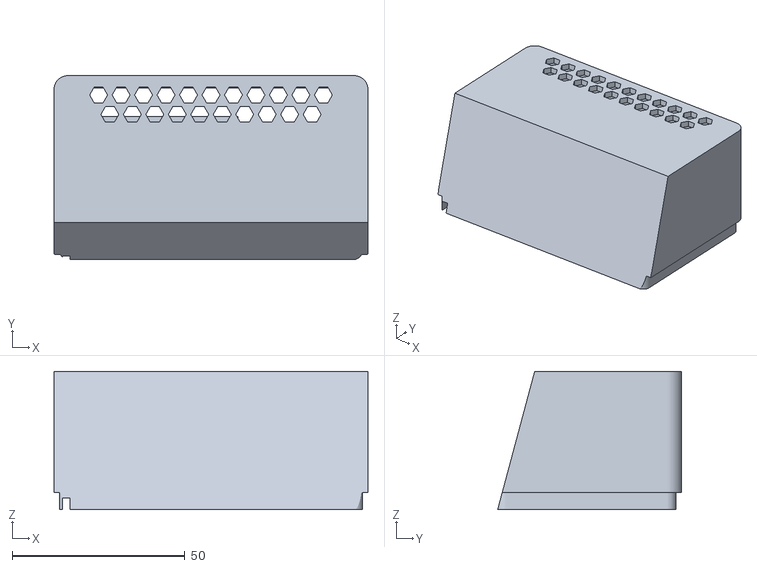
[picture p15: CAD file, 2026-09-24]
case/back_tray.stl
90.8 x 53.1 x 40.0

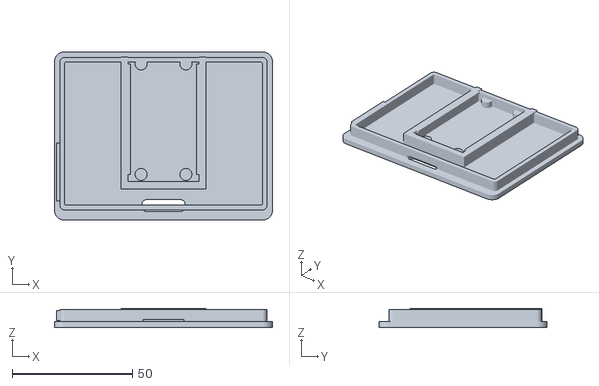
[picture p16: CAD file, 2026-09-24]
case/v2/v2_base.stl
90.8 x 70.0 x 8.10

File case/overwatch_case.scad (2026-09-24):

// =====================================================================
// Overwatch - the case
//
// A bezel that shows the PICTURE and nothing else, and an EMPTY tray that
// plugs into the back of it. Two printed parts, no screws, no posts, and
// nothing inside the body at all.
//
// WHAT CHANGED, AND WHY
//
// The version before this had two faults that between them cost a panel.
//
//   1. The aperture was sized to the GLASS and the glass was a press fit
//      in it -- 0.3 mm nominal, which an FDM hole can easily print
//      UNDERSIZE. The only way the panel went in was by being pressed,
//      and pressing a glass module into a too-small hole cracks the flex
//      between the glass and its board. The module then lights up white
//      and never draws, with nothing in any log to say why.
//
//   2. Four snap pegs sat at x=+/-40, y=+/-12 -- INSIDE the panel's
//      +/-43 x +/-25 footprint. To reach their sockets they travelled
//      through the space the board occupies, so assembling it would
//      press four posts into the back of the panel. They were moved out
//      of the corners to save border and never checked against the board.
//
// Both are gone. The lip now overlaps the glass, so the glass does not
// pass through the aperture AT ALL -- it goes in from behind and rests
// against the lip. There is no press fit left to be tight. And there are
// no pegs, because there is nothing inside.
//
// THE HALVES JOIN AT THE RIM. The bezel carries a 1.4 mm rim reaching
// back past the board; the tray's spigot plugs into it. Friction, and the
// join is at the perimeter where there is room for it -- not through the
// middle where the panel is.
//
// PRINT ORIENTATION
//   bezel  face DOWN. The chamfer round the window then prints as an
//          overhang off the bed's first layer, which is where it is
//          cleanest, and the face people look at gets the bed finish.
//   tray   open side UP.
// =====================================================================

$fn = 48;

// ---- the panel, measured -------------------------------------------
pcb_w      = 86.0;
pcb_h      = 50.0;
pcb_t      = 1.6;
glass_w    = 69.0;
glass_h    = 50.0;   // the full height of the board
glass_left =  8.0;   // UNUSED, kept as the raw measurement. Careful:
                     // "left" here is off the photograph, not the
                     // model's +x. See WHICH WAY IS RIGHT.
glass_pro  =  3.4;   // glass stands this proud of its board

// The whole module, front to back: 8.0 measured. Glass 3.4 + PCB 1.6
// leaves 3.0 of ribbon and driver reaching BACK into the tray, which is
// the figure the tray's depth has to start from. The perch was sized
// against an assumed 5.8, so it was conservative rather than wrong.
disp_d     =  8.0;
panel_back = disp_d - glass_pro - pcb_t;   // 3.0, into the tray

// The LIT area, and where it sits on the BOARD.
//
// Measured on the board itself, 2026-09-24: the picture starts 11 mm in
// from one end of the 86 mm board and 17 mm in from the other, so it is
// 58.0 wide and its centre is 3.0 mm off the board's.
//
// Two independent measurements agree on this. Reading off the printed
// case gave 13 and 20 from the CASE edge; with the board inset 2.4 each
// side that is 10.6 and 17.6 from the board edge, against 11 and 17 here
// -- within 0.6 mm. The board reading is the one used, because it does
// not depend on the case having printed to size.
//
// 58.0 also lands 0.4 mm off the nominal 57.6 for a 2.8" 4:3 panel, which
// is the kind of agreement that means both numbers are probably right.
//
// The picture is centred vertically: 3 mm from the board edge at the top
// and 3 at the bottom, measured.
act_w      = 58.0;
// MEASURED too, now. The glass is the board's full 50 mm height and the
// picture starts 3 mm in from the board edge top and bottom, so it is 44
// tall. That was derived as 43.5 (4:3 from the measured 58.0 width); the
// measurement is 0.5 more. 58.0 x 44.0 is 1.318:1 against a nominal
// 1.333, which is either a slightly wide panel or a rounded reading --
// and well inside the 1 mm the window carries either way.
act_h      = 44.0;

// WHICH WAY IS RIGHT
//
// The screen's face is at z=0 and the body runs back to +z, so the
// viewer looks along +z with +y up. In a right-handed frame that puts
// the viewer's RIGHT at NEGATIVE x. Not positive. This is the whole
// trap: every left and right in the notes -- the 11/17 borders, "USB on
// the right" -- is from in front of the screen, and writing them against
// +x mirrors the case. The port lands on the far side and the wide
// border goes with it, and a box this symmetric will not look wrong in
// any render.
//
// So don't write act_cx as a signed guess. Derive it from the border
// the viewer sees on their right, and it cannot come out mirrored.
bez_right  = 17.0;   // border on the viewer's RIGHT, measured
bez_left   = 11.0;   // and on their left -- 11 + 58 + 17 = 86 = pcb_w
act_cx     = -pcb_w / 2 + bez_right + act_w / 2;   // = +3.0

// ---- the ESP32 ------------------------------------------------------
// From the board's own spec sheet, not estimated. The model previously
// carried 52 x 28 with no allowance at all for the pins, which was wrong
// in both directions: 3.7 mm too long, and it would have sat the board
// flat on the floor and bent 38 header pins.
esp_l      = 48.26;  // PCB length
esp_w      = 27.94;  // PCB width
esp_t      =  1.60;  // PCB thickness
esp_pins   =  8.50;  // header pins hanging BELOW the board
esp_shield =  3.10;  // WROOM module, above the board

// USB-C, on the short end. Centred on the width (13.97 from either edge),
// 8.94 across the metal shell, 3.16 tall from the PCB's top surface, and
// it overhangs the board's end by 1.20.
usb_shell_w = 8.94;
usb_shell_h = 3.16;
usb_over    = 1.20;

// The opening has to pass a PLUG, not the receptacle: a USB-C overmould
// is a good deal bigger than the 8.94 x 3.16 socket it goes into. These
// are the spec's maximum cable-plug overmould, so any compliant cable
// fits; usb_fit is the whole allowance, print shrink included (FDM holes
// come out 0.2-0.4 under).
usb_plug_w = 12.35;
usb_plug_h =  6.50;
usb_fit    =  0.60;

function usb_w() = usb_plug_w + usb_fit;   // 12.95
function usb_h() = usb_plug_h + usb_fit;   //  7.10

// ---- the ESP32's perch ----------------------------------------------
// The board lies FLAT against the back wall, component side toward it,
// just below the vents -- the arrangement in the mock-up. Its pins and
// the dupont shells point forward into the body, which is the only place
// with room for them.
//
// THE STANDOFF IS SET BY THE PLUG, NOT THE SOCKET. The connector is only
// 3.16 tall, so 4 mm would clear it. But a USB-C plug's overmould is
// about 7 across, centred on that socket, and at 4 mm it reaches z=39.08
// against a back wall at 38 -- the cable fouls the case before it seats.
//
//   s=4 -> plug reaches 39.08   FOULS
//   s=5 -> plug reaches 38.08   FOULS
//   s=6 -> plug reaches 37.08   clears
// The display's own connectors sit on the BACK of the panel and start
// right at the edge on the case's right-hand side -- negative x, the same
// edge the USB comes out of. The spigot's nose overlaps the board by 1.2
// all the way round, so on that edge it would land straight on them.
//
// Nothing inboard of the spigot's inner face needs any help: that is open
// cavity, 33 deep. Only the 1.2 band where the nose overhangs the board
// is in the way, so that band is cut back over the connectors' height.
// The spigot keeps its full OUTER face there, so it still locates in the
// rim -- it just stops touching the board on that one edge.
panel_conn = 3.4;    // connector height off the board, 3.0 measured + 0.4

esp_stand  = 6.0;    // board's component face to the back wall
// The slot is cut to the BOARD, not to a round number. It used to leave
// 0.50 a side on the width and 0.30 on the thickness -- the board sat in
// it loose enough to rattle.
//
// FDM takes some of this back: a slot prints 0.1-0.2 narrow. So 0.15 a
// side lands near zero slack in the plastic, which is what snug means.
// It is THE number to open up if the board will not go in. Do not force
// it -- forcing a fit is how the first display's flex went.
esp_fit    = 0.15;   // per side, on the width     -> slot 28.24 / 27.94
esp_fit_t  = 0.15;   // total, on the thickness    -> slot  1.75 /  1.60

rail_back  = 1.5;    // material behind the slot
rail_grip  = 1.0;    // how far the rails reach over the board's edges
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

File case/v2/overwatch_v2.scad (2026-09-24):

// =====================================================================
// Overwatch V2 - the wedge
//
// A slanted screen on a flat base. Two printed parts, no screws.
//
//   v2_shell   the wedge: slanted front with the window, vertical back
//              with the USB port and a honeycomb vent, closed top and
//              sides, OPEN BOTTOM.
//   v2_base    the bottom, which snaps in and carries the ESP32.
//
// EVERYTHING ENTERS FROM UNDERNEATH. The panel, the loom and the board
// all go in through the bottom, so the shell has no seam anywhere you
// look at it.
//
// WHY THE PORT REACHES THE BACK HERE, AND COULD NOT IN V1
//
// A DevKitC carries its USB connector on a SHORT END, in the plane of
// the board. V1 laid it against a vertical back wall, so that port
// pointed at a SIDE wall -- the back slot cut there would have opened
// onto solid board.
//
// Lying it flat on a HORIZONTAL base turns the port to face sideways-on,
// i.e. horizontally. Aim that end at the back wall and it exits the back.
// The board's long axis has to run front-to-back for that, which is what
// sets the depth.
//
// THE DEPTH IS NOT 52, AND NOT 52 PLUS THE LEAN EITHER
//
// The panel leans back OVER the base, so the board sits under it -- they
// overlap in plan, and adding the two was wrong. But the panel's back
// surface is a sloping line, z(y) = y*tan(lean) + panel_d/cos(lean), and
// the board has to start behind wherever that line is at the board's own
// height. At 20 degrees with the cables lying flat that is 13.7, so
// 13.7 + 52 + walls = 68. Let the dupont shells stand up instead and it
// costs 5 mm more case.
//
// PRINT ORIENTATION
//   shell  on its BACK. The back is flat, the open bottom faces sideways,
//          and the slanted front becomes a 20-degree overhang -- inside
//          the 45 rule, so no supports.
//   base   flat, posts up.
// =====================================================================

$fn = 48;

// ---- the panel, measured -------------------------------------------
pcb_w      = 86.0;
pcb_h      = 50.0;
pcb_t      = 1.6;
glass_w    = 69.0;
glass_h    = 50.0;   // the full height of the board
glass_left =  8.0;   // red showing on the left
glass_pro  =  3.4;   // glass stands this proud of the PCB
panel_d    = 10.8;   // glass face to the back of its cables

// ---- the ESP32 ------------------------------------------------------
esp_l      = 52.0;   // long axis: runs front-to-back
esp_w      = 28.0;
esp_h      =  6.0;   // bare board on its standoffs, cables led away flat
usb_w      = 11.0;   // USB-C, plus room
usb_h      =  5.5;
usb_z      =  4.0;   // port centre above the base's inner face

// ---- print settings -------------------------------------------------
wall       = 2.0;
clear      = 0.4;
bezel      = 1.2;
glass_gap  = 0.5;    // per side. 0.3 was too tight: an FDM hole comes
                     // out 0.2-0.4 undersize, so it can print smaller
                     // than the glass and then the panel only goes in by
                     // being pressed -- which cracks the flex between the
                     // glass and its board. Costs 0.4 mm of visible gap.

// The front face has to be THICKER than the wall, or the panel has
// nowhere to sit. Glass stands 3.4 proud of its board, so 3.4 of face in
// front of the PCB is what makes the glass finish flush; the board's own
// 1.6 sits behind that. 2 mm of wall would leave the glass standing 1.4
// proud and the pocket cutting clean through the face -- which is what
// the first render showed, a front you could see straight through.
front_t    = glass_pro + pcb_t;   // 5.0

// ---- room for the flex ----------------------------------------------
// The glass is 69 wide on an 86 board, so its flex has to get down to the
// PCB at one of the two SHORT edges -- the 8 mm and 9 mm red strips. The
// pocket gave those edges 0.4 mm, which is nothing: a flex that wraps the
// edge, or merely stands proud of it, is gripped by the pocket wall. A
// panel went white after being fitted, and this is the likeliest reason.
//
// Relieved over the MIDDLE of each short edge only. Relieving the whole
// edge would leave the board unlocated in X and the picture would wander
// in the window; leaving a land top and bottom keeps it placed while the
// flex gets its room.
flex_gap   = 1.5;    // extra clearance at each short edge
flex_land  = 9.0;    // pocket wall kept at each corner, to locate the board

// ---- the wedge ------------------------------------------------------
// 20 degrees, and the reasoning is in BRIEF.md: at a desk your sight line
// drops about 41 degrees, so a screen aimed straight at you would lean 49
// -- which costs 90 mm of depth and is not buildable. 20 leaves 29 off
// axis, which an ILI9341 takes without washing out.
lean       = 20;

face_w     = pcb_w + 2 * (wall + clear);        // 90.8
face_len   = pcb_h + 2 * (wall + clear);        // 54.8, measured UP THE SLOPE
// The face has to come out EXACTLY face_len long, because that is what
// the window is centred in. height = face_len*cos(lean) does that.
// It was face_len*cos(lean) + wall + 2, which made the face 59.1 and
// dropped the panel 2.2 mm off the bottom edge.
height     = face_len * cos(lean);
depth      = 70.0;
corner_r   = 4.0;

// ---- the base -------------------------------------------------------
base_t     = 2.5;
lip_h      = 5.0;    // how far the base's lip reaches up inside the shell
lip_fit    = 0.25;   // per side. THE number to tune if the base is loose.

// ---- the ESP32's cradle ---------------------------------------------
// The board slides in from the BACK until its port end meets the shell's
// back wall, so the USB-C lines up with the hole by construction rather
// than by being placed carefully.
//
// The first version was two bare 5 mm pegs. They held the board off the
// floor at roughly the right height and did nothing else: nothing located
// it sideways, nothing stopped it sliding, and nothing held it down --
// so plugging a cable in would simply push the board off them.
esp_lift   = 3.0;    // standoff, so the port centres on the hole
rail_t     = 3.0;    // the side rails
rail_h     = 5.6;    // tall enough to get a lip over the board
rail_gap   = 0.8;    // per side, around the board's 28 mm width
clip_over  = 1.0;    // how far the rails' lip reaches over the board

// ---- keying ---------------------------------------------------------
// A rib on ONE SIDE rail of the lip, well forward of centre, and a slot
// for it in the shell's matching side wall.
//
// It was on the BACK rail first, blocked by the leaning front wall when
// reversed -- but only by 0.52 mm, because the lip's front is already set
// back 1.95 mm to clear that lean and a reversed base simply eats the
// slack. The setback fights the keying.
//
// Off-centre along the LENGTH cannot be symmetric: reversed, the rib
// lands at depth - key_y, where the shell's wall is solid, and is blocked
// by its full depth with nothing to absorb it.
key_y      = 20.0;   // forward of the middle, so reversing moves it 30 mm
key_w      = 24.0;   // along the length.
                     //
                     // Was 10, which worked and could not be FOUND: at
                     // 10 x 3 it reads as a print artefact rather than a
                     // feature, and a tab that small snaps off the first
                     // time the base is prised out. Length is free here
                     // -- the blocking depth is what does the keying, and
                     // that is unchanged -- so it buys visibility and
                     // strength for nothing.
key_t      = 1.5;    // how far the rib stands out sideways
key_h      = 4.0;

// ---- the vent -------------------------------------------------------
hex_r      = 3.4;    // across the flats
hex_gap    = 1.6;    // web between cells

// =====================================================================
// helpers
// =====================================================================

module rrect(w, h, r) {
	hull() for (x = [-1, 1], y = [-1, 1])
		translate([x * (w / 2 - r), y * (h / 2 - r)]) circle(r);
}

// The side profile: a right trapezoid. Vertical back, flat base, front
// leaning back by `lean`. Extruded along X to make the wedge.
module wedge_profile(d, h, inset = 0) {
	offset(r = -inset)
		polygon([[0, 0],
			 [h * tan(lean), h],
			 [d, h],
			 [d, 0]]);
}

module wedge(d, h, w, inset = 0) {
	rotate([90, 0, 90])
		linear_extrude(w, center = true)
		wedge_profile(d, h, inset);
}
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

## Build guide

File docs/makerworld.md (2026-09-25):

<!--
The MakerWorld model page. Everything from the heading down to the *** rule is
what gets pasted into the description box; the notes under it are for us.

Shaped to match what the platform's own successful CYD listings do - read off
three of them on 2026-09-11, noted at the bottom. In short: open with why you
built it, then a features list, then what to buy, then print settings, then
assembly, then links out. They all repeat the print settings in the description
even though the profile carries them, because that is what a person checks
before clicking print.

Plain hyphens throughout, never -- or an em dash: nothing converts them, so
both characters just show.

THE DESCRIPTION BOX IS A WYSIWYG EDITOR, NOT A MARKDOWN FIELD. It has a
Paragraph dropdown, B/I/U, lists and a table button. Pasting this file raw puts
literal ## and ** on the page. Get formatting in by pasting rendered HTML from
a browser instead:

    sh tools/makerworld_paste.sh

which writes ~/Downloads/overwatch-makerworld-paste.html from the body below.
Open it, select from the heading down, copy, paste. Headings, bold and bullets
survive; MakerWorld restyles them to its own look.

Keeping this file as markdown is still right: it diffs, it renders on GitHub,
and the HTML is derived from it rather than the other way round.
-->

# OVERWATCH

**Your Claude Code and Codex usage, as two live dials on your desk.**

Your 5-hour session and your 7-day week, each as a dial that runs green to
amber to red, with a countdown to when it resets. It reads the figures Claude
Code and Codex have already written on your own computer, so there is no
account, no sign-in, and nothing leaves the machine.

## What it does

- Two dials: the 5-hour session and the 7-day week, with the time until each
  one resets.
- A mark in the top-left corner for every coding session you have running,
  coloured by what it is doing.
- Claude and Codex each get a page of their own. Swipe between them.
- It dozes when your computer sleeps and wakes when it wakes.
- Updates itself over the same USB lead.

## What to buy

- **An ESP32-2432S028** - the "Cheap Yellow Display". 2.8 inch, 320x240, touch.
  Sold everywhere as a CYD, about $12.
- **A USB data cable.** Power and readings share the one lead, so a
  charge-only cable will not do.

Links are in the Bill of Materials. That is the whole shopping list: no screws,
no heat-set inserts, no magnets, and nothing to solder.

## Printing

Six parts on three plates, already laid out and oriented in the 3MF. Printed in
PLA on a P1S with a 0.4 nozzle, but there is nothing printer-specific about it.

- **Layer height** 0.2 mm
- **Material** PLA. The ones in the photos are Bambu PLA Basic, Pumpkin
  Orange (10301).
- **Walls** 2, with 5 top layers and 3 bottom
- **Infill** 30%, grid
- **Brim** auto, 5 mm

**Supports:** the front needs them and they are already painted on. The back
needs none, and the project has them switched off for it. **Leave them off.**
The stand prints in place in a shallow recess, and support material in that gap
is what welds it shut.

The three plates are the front, standing on its edge so the screen opening
rises vertically; the back, flat; and the four small screen spacers.

## Assembly

1. Drop the board into the front, screen first, so the display sits in the
   window.
2. Push the four spacers down over the posts at the corners of the board. They
   hold the screen against the front, so they go on before anything closes over
   them.
3. Fit the back on, lining the USB socket up with its opening. It only goes on
   one way round: the vent slots run across the top.

## The stand

The stand is part of the print. It folds flat into a recess in the back, so the
case lies flat in a bag, and swings out to hold the screen at an angle.

1. It prints folded away, and the back looks flat.
2. Hook a fingernail under the bar and slide it down until it is clear.
3. Swing it out from the back until it stops. It stops where it stops.
4. Stand it up. It folds back in the same way.

Gently. Nothing here needs force.

## Making it work

The firmware and the app are free and open source, and one command installs
both. Everything, including what to run on your computer:

**https://github.com/KfirLevy258/Blink**

## Would rather not build one?

I build them, test them and post them - flashed, assembled, and checked on a
real desk before they go out.

**https://blink-buddy.com**

## Licence

Print as many as you like, for yourself. Beyond that, please keep it here:
don't sell it, don't pass the printed cases on, and don't re-post the files
elsewhere.

The firmware and the app are a separate matter, and far more open. They live on
GitHub under their own licence, and you are free to read them, change them and
build on them.

***

## The print profile

Its own name and description field, separate from everything above. The name
is already right: "0.2mm layer, 2 walls, 30% infill".

The description box is a small editor with bullets but no headings. Paste this
as a bulleted list. The third line is the only one that can ruin a print, so it
is not buried at the bottom.

> - 0.2 mm layer height, 2 walls, 5 top and 3 bottom, 30% grid infill
> - Three plates: the front on edge, the back flat, and four screen spacers
> - Tree supports are painted on the front only, and are already in the file
> - Leave supports OFF for the back. The stand prints in place in a shallow
>   recess, and support material in that gap welds it shut
> - Printed in Bambu PLA Basic, Pumpkin Orange (10301), on a P1S with a 0.4
>   nozzle. Nothing here is printer-specific
> - Every part fits an A1 mini bed: the tallest is the front at 88 mm standing
>   on a 19 x 120 mm footprint

IF THE PAUSE STAYS IN THE UPLOADED 3MF, a sixth line has to go in, naming what
to drop in at 1.6 mm. A printer stopping with nothing on the page to explain it
reads as a fault. If the pause is stripped, say nothing.

Printer compatibility: leaving every box ticked is right. Checked the geometry
against the smallest bed Bambu sells (A1 mini, 180 x 180 x 180) and all six
parts fit with room to spare.

***

## The community post

Enabling Community Post opens its own text box, capped at **500 characters** -
not words. It is a feed post, not the description: two paragraphs, the first
naming the problem, the second the build. 445 characters, so there is room to
adjust a line without a rewrite.

> If you use Claude Code or Codex you have a 5-hour limit and a 7-day one, and
> no way to see where you stand without stopping to check. OVERWATCH shows both on
> your desk: two dials, green to amber to red, counting down to each reset. It
> reads what the tools already write on your own machine, so nothing leaves it.
>
> One $12 ESP32 board and six printed parts. No screws, nothing to solder, and
> a stand that prints in place and folds flat into the back.

What had to go, and why, in case the cap ever moves: the session pips, the
sleep behaviour, the two provider pages, the supports warning, and the "post a
make" invitation. All of them are in the description, which has no such cap.
Markdown is left out entirely - 500 characters is too few to spend on asterisks
that may render literally.

***

<!--
BEFORE PUBLISHING

  [ ] decide what to say about the PAUSE (below)
  [ ] pick the MakerWorld licence (below)
  [ ] fill the Bill of Materials field with the board and the cable, with links
  [ ] check the assembly steps: the 3MF says what the parts ARE, not the order
      they go together in, so those three lines are inference from the geometry
  [ ] optional: open with why you built it. Two of the three comparables do,
      and it is the part nobody can copy. Left out rather than invented.
  [ ] fill the Bill of Materials: CYD board x1, USB data cable x1 under "List
      other parts"; Bambu PLA Basic / Pumpkin Orange (10301) / Filament with
      spool under Filaments. The buy list says "Links are in the Bill of
      Materials", which is false until that field exists
  [ ] optional: the 3MF's filament swatch is #FF6A13 (Bambu Orange 10300), but
      the units were actually printed in Pumpkin Orange 10301 (#FF9016), so
      the slicer colour was never updated when the spool changed. Cosmetic
      only - the PLA Basic profile prints the same either way - but someone
      opening the project sees a colour the BOM contradicts
  [ ] add the model's URL to README.md, in the Open source section

No print TIME here on purpose: the project is unsliced, so the file carries
none, and MakerWorld works its own out from the upload anyway.

THE PAUSE AT 1.6 mm

Metadata/custom_gcode_per_layer.xml in overwatch_claude_edition.3mf puts `M400 U1`
- a pause - at top_z 1.6 on more than one plate. A printer that stops on its
own, with nothing on the page to explain it, reads as a fault.

Our own units have an NFC tag under the shell (step 02 on the boxed card), and
1.6 mm is about where you would drop one in, so that is the likely reason. A
maker has no tag to insert. Either strip the pause from the uploaded 3MF, or
keep it and say on the page what it is for. Do not leave it silent.

THE LICENCE: STANDARD DIGITAL FILE LICENSE (decided 2026-09-12)

Kfir's call, made looking at the form: no commercial use, and nothing changed.
That is the Standard Digital File License, the strictest MakerWorld offers -
"You shall not share, sub-license, sell, rent, host, transfer, or distribute in
any way the digital or 3D printed versions of this object, nor any other
derivative work... The objects may not be used without permission in any way
whatsoever in which you charge money, or collect fees."

Set the four radios to No / No / No / No. The badge under the box should read
Standard Digital File License; it is the default, so nothing needs changing.

The description's licence section was rewritten to match. It previously said
"free to change, free to give away", which this licence forbids, and a listing
whose prose contradicts its own badge is worse than either alone.

TWO THINGS THAT FOLLOW FROM IT

  - A LICENCE BINDS LICENSEES, NOT THE OWNER. Kfir holds the copyright, so
    SDFL on MakerWorld does not stop him publishing the same STLs on GitHub,
    blink-buddy.com, or anywhere else, under any terms he likes. Nothing here
    is a lock-in for him; it only binds people who download from MakerWorld.

  - IT DISAGREES WITH README.md. The repo's Open source section says "Build
    one. Build ten... Give them to your friends." Under SDFL a person may not
    hand on a printed case. The software and the model are separately licensed
    and may legitimately differ, but if anyone ever asks, that is the answer,
    and it is worth saying out loud rather than discovering.

WHAT WAS CONSIDERED INSTEAD

Read off three real CYD listings on 2026-09-11. The choice is wider than
Creative Commons, and every option already forbids selling - so the platform,
not our paragraph, is what actually enforces it.

  - Standard Digital File License (HandyHack, 1940770): "You shall not share,
    sub-license, sell, rent, host, transfer, or distribute in any way the
    digital or 3D printed versions of this object, nor any other derivative
    work." Forbids selling AND all redistribution. Too strict for us: it
    contradicts "free to give away".

  - MakerWorld Exclusive License (CYD Desk Buddy, 2787810): derivatives are
    allowed but must be published EXCLUSIVELY on MakerWorld, and commercial use
    is "strictly prohibited". The no-selling half is right; the exclusivity
    half locks remixes to one platform, which is not our bargain to impose.

  - Creative Commons BY-NC-ND (Case for ESP32 CYD, 1033712): no derivatives at
    all, so it contradicts "free to change".

CC BY-NC-SA 4.0 remains the pick: print it, change it, re-share it, credit
OVERWATCH, never sell it, and pass the same terms on. It is the only one of the
four that says what the description says.

This governs the MODEL FILES. The software keeps its own licence in LICENSE at
the root of the repo. The two need not match; they only have to agree about
selling, and all of these do.

WHERE THE SHAPE OF THIS PAGE CAME FROM

  - CYD Desk Buddy (2787810) is the closest comparable and the best written:
    what it is, why I made it, Features, Hardware, Printing, Assembly/Wiring,
    Notes. Plain headings, no emoji. This page follows it.
  - HandyHack (1940770) uses emoji headings and a longer feature list. Louder,
    and it works for a bristling gadget; wrong register for this one.
  - Case for ESP32 CYD (1033712) is four short paragraphs and a GitHub link -
    about as thin as a listing gets, and it still repeats its print settings.

  All three repeat print settings in the description even though the profile
  carries them, and all three name the exact board. Two of the three open with
  why the maker built it before saying what it is.

  There is a structured BILL OF MATERIALS field, separate from the description,
  that takes purchase links. "Links are in the Bill of Materials" above is the
  same line the best comparable uses, and it is a lie until that field is
  filled.

A SHORTER VERSION EXISTS

The 285-word cut is in the scratchpad as makerworld-minimal.md. It reads well
but it is thinner than anything on the platform, and it drops the two things
every comparable keeps: the print settings and the exact board behaviour.
-->

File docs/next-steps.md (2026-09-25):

# Next steps

What is left, and what has been closed off. Written against the code as it
stands on `desk-hud-universal`.

---

## A. Browser usage: measured, and not available (CLOSED 2026-08-28)

The one place usage happens that neither the CLI hook nor the desktop cache
can see is a claude.ai tab. A browser extension and a matching localhost
receiver were built to close that gap, and then run against the real site on
2026-08-27: a page load, three reloads and one complete message turn, the
completion request included.

**178 responses from `https://claude.ai/*`, zero carrying a rate-limit
header.** Not a partial match, not an unrecognised name — nothing shaped like
a limit, a remaining count, a reset time or a used percentage.

That is the whole finding, and it is recorded here so nobody rebuilds the
apparatus to ask the question again. Two details it is worth keeping with it:

  - **`extraHeaders` would not have changed the result.** That flag exists for
    `Set-Cookie` and the CORS-restricted set; `onHeadersReceived` already sees
    every ordinary response header. There is no hidden header to go and find.
  - **The remaining mechanisms are worse, not merely untried.** Reading the
    response body or injecting a content script both mean touching page
    content rather than observing metadata, and the second is already on the
    project's concerns list. Neither should be started without deciding that
    deliberately.

The extension, the `pc/webbridge.py` receiver, `ClaudeWebProvider`, their
tests and the `Browser` line in `overwatch status` were all removed on
2026-08-28. Three things paid for a source that returns nothing: a listening
socket open on loopback for the daemon's whole life — the only one this
product had — an install that asks a buyer to grant a browser extension read
access to their Claude traffic, and about a thousand lines to keep working.
The code is in git history if claude.ai ever grows the headers; reviving it is
a revert, not a rewrite.

## B. Session and agent status (DONE 2026-08-26)

**This section described unbuilt work for two days after it was built.** It is
kept, rewritten, because the decision it turned on is worth having on record --
and because a plan that describes shipped code as pending is worse than no
plan: it sends someone to build a thing twice.

### What was built

`tools/overwatch-hook.sh` writes one file per session (`~/.overwatch/state/<id>.state`)
and one per agent, so two terminals no longer overwrite each other.
`pc/providers/claude_state.py` reads the directory, derives a state per session
from the last event, sweeps what has died, and reports the worst of them plus
an exact live agent count. Ten hook events are installed:

    SessionStart  UserPromptSubmit  PreToolUse  PostToolUse  Notification
    Stop  StopFailure  SessionEnd  SubagentStart  SubagentStop

Three of those came from reading the hooks reference rather than assuming:
there is no `session_id` environment variable (only `CLAUDE_PROJECT_DIR`), so
it is parsed from the payload; `SubagentStart`/`SubagentStop` carry `agent_id`,
which is what makes an exact lock-free count possible (one file per agent); and
`StopFailure` runs INSTEAD of `Stop` when a turn dies on an API error, carrying
`error: "rate_limit"` — the headline on a usage gauge, so it earned its own
state ranked above `stuck`.

### The decision that came first, and how it went

Every option here needed the shim to capture **more than an event name and a
timestamp**, which is what made the metadata-only promise structural rather
than a matter of restraint. It was taken deliberately: the capture widened to
`session_id` and `agent_id` and **nothing else** — no prompt, no tool
arguments, no paths, no message text. The install disclosure, the README and
`check_hook_shim.sh` were updated in the same change, and the shim is asserted
under sh, bash and dash against a payload that deliberately contains all the
things it must not keep.

The session id becomes a FILENAME, which makes it the only attacker-shaped
input on a path in this product. The character class in the shim's `sed`
pattern is the sanitiser, and traversal is pinned by test.

### What is still open

`stuck` is inferred from silence at 180 s, which is a guess about how long a
tool may legitimately take. Nothing has been measured against real long-running
tools. And a subagent that outlives `ABANDONED_AFTER_S` (1 h) is swept from the
count even though it is still running, because the shim never refreshes its
file's mtime.

## C. Codex, and the second page (DONE 2026-08-27)

The firmware has had a second provider page since `bca447f` — one provider per
screen, vertical swipe between them, a rail dot each — and the settings screen
has let you pick Codex as the main source for longer than that. **Nothing ever
reported Codex.** So `set_preferred("codex")` was refused every time the board
announced it (`board asked for provider 'codex', which is not reporting`),
`page_count()` stayed at 1, and both vertical swipes were no-ops. The feature
existed at every layer except the one that produces numbers.

`pc/providers/codex_cli.py` closes that. Codex CLI appends its own
`rate_limits` to the rollout log it keeps per session:

```
~/.codex/sessions/<YYYY>/<MM>/<DD>/rollout-<stamp>-<uuid>.jsonl
  → event_msg / token_count → rate_limits
      primary   {used_percent, window_minutes: 300,   resets_at}
      secondary {used_percent, window_minutes: 10080, resets_at}
```

Same shape as every other source here: a figure another program has already
worked out, read from a file it writes for its own reasons. No credential, no
prompt text, no network.

Three decisions in it worth not re-deriving:

  - **Windows are matched by `window_minutes`, not by `primary`/`secondary`.**
    Those are positions in a file we do not control, and getting them the
    wrong way round swaps the two dials silently. Position is the fallback,
    used only when the length is absent.
  - **`resets_at` is seconds, and is range-checked.** Claude Desktop's sample
    timestamps in the same daemon are milliseconds, so this is a live
    difference between two files, not a hypothetical one. Out of range costs
    the reset time and keeps the percentage.
  - **The newest file is not the newest reading.** A terminal left open moves
    its rollout's mtime without ever writing a `token_count`. The provider
    reads the tail of the few most recently touched files and takes the
    freshest *event*, then emits ONE frame — the percentages are account-wide,
    so six terminals are six copies of one answer.

Verified live, 2026-08-27: real rollout parsed, board flashed with this
branch, `p2: 'codex'` on the wire, and the board's stored `codex` preference
honoured for the first time (`[bridge] main source: codex`).

**The "main source" setting is gone (2026-08-27).** It chose which provider
owned the outer ring back when both shared one gauge. They do not: each has a
page, and "which one is in front" is answered by the page you are looking at.
`cfg_get/set_main_src` stay, because the value still goes to the host on every
`hello` where the daemon uses it to break ties when merging sources — that is
a host-side meaning and not something to settle from across the room with a
fingertip.

---

## D. The Codex edition (DONE 2026-08-27/28)

A second SKU: same board, same firmware image, same wordmark, **different boot
clip and nothing else**. Which one a unit plays lives on the UNIT — an
`edition` byte in the sealed config record, written once over USB with
`overwatch provision --edition codex|claude`, read once at boot by
`bootclip_active()`.

A build-time flag was rejected because it forks OTA: the manifest names one
firmware and `hello` carries no edition, so a Codex unit would be offered the
Claude image and revert silently in the field, months later. Both clips are
compiled in instead; the second costs 17 KB on an image using 601 KB of 4 MB.

**It is WRITE ONCE, and that took two locks, not one (2026-08-28).**

  - `cfg_set_edition()` latches: the first successful write sets
    `edition_locked` and every later one returns `-EPERM`. "Not reachable from
    the settings screen" was being treated as the whole enforcement and is not
    — the message arrives over USB from whatever is on the other end of the
    cable, and `overwatch provision` is the same binary the customer installs.
  - **The edition survives `cfg_reset()`.** Factory reset used to wipe the
    whole record, which made the settings menu a second route to the same
    change: reset, re-provision, and a Codex box plays the Claude clip. Two
    taps and a cable, no CLI. A reset wipes what the USER put on the device;
    the edition is a property of the enclosure the board is screwed into.

What remains is erasing the config partition with esptool over USB with the
board held in bootloader mode — a factory operation by construction, which is
the boundary that was wanted. That applies to dev boards too.

`proto.c` had a matching hole: it skipped the write whenever the stored
edition already equalled the requested one. `0` means both "Claude" and "never
stamped", so provisioning a blank board as claude reported success, wrote
nothing, and left it stampable as codex by anyone with the cable. The latch
decides now, not the value.

**The clip is DRAWN, not filmed.** Four iterations built it out of the shipped
Claude clip's own frames and the panel showed "glitters and jitters" around
every shape. That clip is h264: its edges are antialiased and motion-blurred,
and hard-thresholding them to two colours leaves 13-30 stray pixels per frame
that MOVE every frame — invisible on the original's busy ground at speed,
boiling on a flat held box. `tools/make_bootanim_codex.py` draws everything at
4x and thresholds, so identical geometry gives identical pixels. Blob halved to
7,571 B. **Generalise it: never threshold filmed material into a two-colour
panel asset.**

Done 2026-08-28: the ground is now `#4C82A8` (4.15:1 against white; it was
`#76B1DB` at 2.31:1, under the 3:1 floor). `tools/make_bootanim_codex.py`
defaults to it.

---

## Rough order

Everything with a section of its own is closed. What is left is not
implementation:

1. **Decided, 2026-08-28** (the README's "Decisions" table is the public
   record): the name is **OVERWATCH**, everywhere, repository included; a config
   record from before the edition latch migrates **latched as Claude**, since
   every fielded unit is a Claude unit and the open reading would have handed
   each owner `overwatch provision --edition codex`; `daemon.auto` ships **off**;
   the Codex clip's ground is now `#4C82A8` (4.15:1 against white, up from
   2.31:1).

   Still open: the Claude Desktop cache path on Windows and Linux -- an
   Electron convention, never observed; `overwatch status` names the path it
   looked at, and one run beside a signed-in Desktop settles it; macOS
   notarisation (needs an Apple developer account); a board
   id on the settings screen; the disclosure question on the five known
   concerns -- four of which are WiFi-build only and are not compiled into
   the shipping image, but whose code is public; and whether the Codex clip,
   which mirrors the Claude clip and lands on a `>_` glyph on Codex blue,
   trades on a second company's mark.
2. **Merge and cut a release.** The published v0.6.0 predates the second page,
   the swipe detector, Codex as a provider, the Codex edition, per-page
   freshness, the burn rate and every fix from the August review.
3. **Two things nobody has watched run**: Windows, and an M-series Mac. CI
   exercises the installer on both; no human has seen the product work there.

Smaller, still open:

- **`overwatch status` says nothing about which providers are reporting.** With
  two on the wire and a preference living on the board, "Usage data fresh
  (1s old)" is less than it could say.
- **The wire carries float noise** — `session_pct: 14.000000000000002` was
  observed. Harmless to the panel, but they are bytes inside a 512-byte line,
  and the fully loaded frame already measures 484 of it.
- **`cfg_set_main_src()` has no callers** since the "Main source" row was
  removed from the settings screen. The board therefore always announces
  `pref: claude`, so a user running both cannot make Codex the primary dial.
  Three files still describe it as a live user choice. Either delete the field
  and its migration, or give the choice a home -- the page pill is the obvious
  candidate -- but it is a design decision, not a bug to patch.
- **A state-only frame is dropped by the normalizer.** On a machine with the
  hooks installed but no statusline payload and no desktop app, the activity
  light has nothing to ride on: `merge()` returns None for a provider group
  carrying no percentage, and sending one would blank the dials instead. The
  real answer is a `state`-only wire message that does not touch them.

**The pip row (2026-09-02).** The header's single execution-state dot became a
row of pips, one per live session, in the gap between the clock and the brand
— which was empty the whole time. The clock is back in its corner and the
rings are back to 120 as a result, and the hint line no longer counts
sessions, because the row does. `fmt_pips()` owns every decision (mode, order,
overflow); `usage_view.c` only positions and colours.

Verified live on the board, 2026-09-02, five frames driven through the real
daemon with `up_ms` climbing 10,263 → 241,128 ms across all of them and no
reset:

| sessions | on the wire | what the row must show |
|---|---|---|
| 3 | `n_run 1` | pip mode, 3 pips: 1 green, 2 amber |
| 6 | `n_run 4` | pip mode, 6 pips — the threshold |
| 7 | `n_run 4, n_stuck 1` | counts mode, an empty state skipped |
| 8 | `n_run 4, n_wait 1, n_stuck 1` | counts mode, `finished` dropped by the overflow rule |
| 16 | `n_run 12, n_wait 1, n_stuck 1` | counts mode, a two-digit tally through the measured-width path |

The daemon omits a zero, so `n_wait`/`n_stuck` are simply absent below —
absent means zero on both sides.

**Not verified: the panel itself.** Every row above is the wire and the board's
liveness, not a photograph. `usage_view.c` needs LVGL and has no automated
coverage of any kind, so whether six pips read as *six* rather than a smear —
the threshold the whole design turns on — is still unanswered, as is whether
the row visibly clears the clock and the wordmark. One session below 3 was
never driven, because reaching it would have meant deleting the owner's real
state files.

**Re-flashed 2026-09-02, and why the table above was briefly wrong.** The
frames in that table were driven at `199df2d`. Two commits later the tally
numeral moved from y=8 to y=6 — its line box had been ending exactly on
`STATUS_Y`, with no clearance to the hint line at all — and
`usage_view_set_counts()` gained the `if (!built)` guard its siblings have.
So the evidence described firmware the branch no longer had, and the one fix
whose whole purpose was a visible 2 px had never run on the board.

Re-flashed at `2ad00ec` and re-driven: 8 sessions (`n_run 4, n_wait 1,
n_stuck 1` — the overflow rule) and 16 (`n_run 12, n_wait 1, n_stuck 1` — the
two-digit tally, which is the case the numeral's Y actually matters in).
`up_ms` 10,263 → 120,346 ms, no reset. The five rows above still hold; only
the image they were taken from changed.

**The hour took the row (2026-09-02, later the same day).** The line under
OVERWATCH read "Working" over a row of green pips — the panel spending its one
sentence to repeat what colour already said. It shows the time instead, and
yields to a sentence only while something wants a person: a failed turn, a
wedged session, an open prompt. "Finished" stays a pip on the owner's call —
not an error, and a desk that finishes a session every few minutes would
never see the clock.

The clock leaving the corner gave the pip row the whole 120 px from the bezel
to the wordmark, up from 75. Counts mode holds **four** groups now, so
`finished` is no longer dropped on an ordinary desk and the overflow rule is
the edge case it was always described as.

Verified on the board at `cecd489`: `state: idle` (clock holds the row),
`waiting` and `failed` (each takes it), then back to `idle` when the probes
cleared. `up_ms` 10,265 → 120,350, no reset.

Verified by rendering, which is the part the board cannot show: the six
scenes in `tools/panel_render/render_main.c` compile `usage_view.c` unchanged
against real LVGL. Six pips read as six. Four count groups fit. Two 9999
groups fit and the rest are dropped by the wall guard rather than crossing it.

Two numbers were wrong and are now derived rather than typed:
`BRAND_W` — "OVERWATCH" measures 52 px at montserrat_14 with the letter_space of
2 the code sets, so the wordmark starts at 134, not the 136 a comment claimed
from a tracking value this code has never used. The clock's worst case was 49,
not 47. Both errors ran in the direction that eats the row's clearance.

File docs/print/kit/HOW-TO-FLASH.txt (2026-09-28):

FLASHING THE BOARD
==================

Wire it first IF you are using a separate ESP32 and panel rather than an
all-in-one CYD board. See wiring-discrete-esp32-only.md in this folder.
On a CYD there is nothing to wire - skip straight to the command.

    *** SDO / MISO STAYS DISCONNECTED. ***

    It would land on GPIO 12, which the ESP32 reads at power-on to pick
    its flash voltage. A wire there stops the board booting at all, and
    it is the last thing you would suspect, because somebody told you to
    fit it.

THE COMMAND
-----------

Plug the board in over USB, then:

    overwatch flash --image overwatch-@VERSION@.bin

Run it from inside this folder. It finds the board on its own, stops the
daemon so the serial port is free, writes the image, and verifies what it
wrote.

Takes a minute or two. THE SCREEN STAYS DARK THE WHOLE TIME. That is
normal - do not unplug it.

AFTERWARDS
----------

The board reboots by itself and should light up.

If it stays dark: the firmware has already been verified by esptool, so
the flash is not the problem. Check the wiring, and check the panel.

Optional, only for a unit that should boot to the Codex mark instead of
the Overwatch one:

    overwatch provision --edition codex

WHY THIS FILE AND NOT THE RELEASES PAGE
---------------------------------------

overwatch-@VERSION@.bin  (this folder)   bootloader + program, one file,
                                     flashed at offset 0. For a board
                                     that has never run anything.

overwatch-fw.bin     (releases page) program only. For a working board
                                     updating itself over USB.

Both start with "overwatch-" and end with ".bin". Only this one works on
a blank board.

SHA256SUMS in this folder is the checksum of the file that should be here.

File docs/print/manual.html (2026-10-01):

OVERWATCH

# Installation, Setup and Project Record

A desk display that shows your Claude Code and Codex usage as live dials, plus a music transport, an app launcher and a face — built on an ESP32, driven by a small daemon on your computer over USB.

Release @VERSION@ · @DATE@
Repository github.com/SleepyUnicon/Overwatch
Setup page sleepyunicon.github.io/Overwatch
Document @DATE@
Licence PolyForm Noncommercial 1.0.0

# Contents

1. Part I — The manual
2. 1 What Overwatch is
3. 2 What you need
4. 3 Installing it on a computer
5. 4 Pairing the board
6. 5 Using it
7. 6 Keeping it updated
8. 7 Uninstalling
9. 8 Troubleshooting
10. Part II — What has been built
11. 9 From BLINK to Overwatch
12. 10 Hardware bring-up
13. 11 The case
14. 12 Firmware
15. 13 The daemon and the web app
16. 14 Updates and release engineering
17. 15 Testing and CI
18. 16 The most recent work, in detail
19. 17 Release history
20. Part III — Reference
21. 18 Commands
22. 19 Where things live
23. 20 Repository layout
24. 21 Rules learned the hard way
25. 22 Open threads

# Part I — The manual

## 1What Overwatch is

A small touchscreen that sits on your desk and tells you things your computer knows but hides.

Its first page is a pair of dials showing the same numbers as Claude Code's /usage command — your 5-hour session and your 7-day week — each turning green through amber to red, with a countdown to when it resets. Codex and Claude Desktop are read the same way.

Swipe left for a music transport, right for an app launcher. Tap the gear for settings. Leave it alone and a drawn face takes over the screen.

It plugs in over USB. There is no WiFi to configure, no account to make, and no cloud service in the path: a small program on your computer reads your local usage files and pushes frames down the cable.

### The two halves

Half | What it does
The board firmware, C, Zephyr | Draws the pages, handles touch, plays the boot clip, applies firmware updates it is offered. Knows nothing about your accounts.
The daemon Python, on your computer | Reads Claude Code's status line, its hooks, Codex's logs and Claude Desktop's cache; works out the numbers; sends them down the cable. Also launches apps and reads your music player when the board asks.

Licence

PolyForm Noncommercial 1.0.0, with an added permission. Build one, build ten, change it, rewrite it, give them away. The one thing the licence forbids is selling it — the device, the software, or any product with it inside.

## 2What you need

### 2.1 The board

Either of two things works. The firmware is written for the first and has been proven on the second.

#### Option A — the integrated board

An ESP32-2432S028, sold everywhere as a "Cheap Yellow Display" (CYD): an ESP32 with a 2.8 inch 320×240 resistive touch panel on one PCB, about $12. Nothing to wire.

#### Option B — a discrete ESP32 and panel

An ESP32 DevKitC (WROOM-32) and a standalone KMRTM28028-SPI 2.8 inch module, joined by 13 jumpers. This is the combination this project actually runs on, verified 23 September 2026: screen draws, colours correct, touch lands on target, daemon connects.

The pin map is unchanged from the CYD's, so no device-tree overlay needs editing:

Module pin | ESP32 | Note
VCC | 3V3
GND | GND
RESET | EN | resets with the board
CS | GPIO 15
D/C | GPIO 2
SDI (MOSI) | GPIO 13
SCK | GPIO 14
LED | GPIO 21 | no transistor
SDO (MISO) | not connected | see warning below
T_CLK | GPIO 25
T_CS | GPIO 33
T_DIN | GPIO 32
T_OUT | GPIO 39 | printed VN on the DevKitC
T_IRQ | GPIO 36 | printed VP on the DevKitC

Leave SDO disconnected

It would land on GPIO 12, which the ESP32 samples at reset to choose its flash voltage. The CYD's panel never drives MISO — the display is declared write-only — so the CYD gets away with wiring it. A module that does drive it stops the board booting, and the wire you were told to fit is the last thing you would suspect.

Two more traps on the same connector: the pin is T_OUT, not T_DO — both spellings exist on these modules. And the DevKitC silkscreen calls GPIO 36 and 39 VP and VN, so they are not where you will look for them.

The full recipe, including the two config files and the macOS and zsh gotchas, is in firmware/WIRED.md.

### 2.2 The computer

Requirement | Detail
Operating system | macOS, Linux or Windows
Claude Code | 2.1.100 or newer. Older versions do not put the usage figures in the status line at all
Python | None. The download is a self-contained binary
Driver | Only on Windows, and overwatch install offers it

### 2.3 The case

A 3D print, in two designs — a Claude edition and a Codex edition — both snap-fit, sized to the glass rather than the lit area. Files are on MakerWorld; the OpenSCAD source is in case/.

## 3Installing it on a computer

### 3.1 One command

Open a terminal and paste the line for your machine. It downloads the program, unpacks it, and runs it.

#### macOS — Apple Silicon

curl -fsSL https://github.com/SleepyUnicon/Overwatch/releases/latest/download/overwatch-macos-arm64.tar.gz | tar xz && ./overwatch/overwatch

#### macOS — Intel

curl -fsSL https://github.com/SleepyUnicon/Overwatch/releases/latest/download/overwatch-macos-x86_64.tar.gz | tar xz && ./overwatch/overwatch

#### Linux

curl -fsSL https://github.com/SleepyUnicon/Overwatch/releases/latest/download/overwatch-linux-x86_64.tar.gz | tar xz && ./overwatch/overwatch

#### Windows — PowerShell

curl.exe -fsSL -o overwatch.zip https://github.com/SleepyUnicon/Overwatch/releases/latest/download/overwatch-windows-x86_64.zip && tar -xf overwatch.zip && .\overwatch\overwatch.exe

Use the command, not a download link

macOS marks anything downloaded by a browser as quarantined and Gatekeeper refuses to run it until the app is notarised — you get "cannot be opened because the developer cannot be verified". curl sets no quarantine flag, so the line above just works. This is the reason the install is a command rather than a button.

### 3.2 What overwatch install does

Running the unpacked program with no arguments is the same as overwatch install. It is the only step, and it is reversible.

Step | What changes
Copies itself | to ~/.overwatch/bin/, so you can delete the folder you downloaded
Status line | adds a statusLine entry to ~/.claude/settings.json. If you already have one it is chained, not replaced — yours still renders
Claude hooks | registers 10 events (SessionStart, UserPromptSubmit, PreToolUse, PostToolUse, Notification, Stop and others) so the board can show what each session is doing
Codex hooks | the same, in ~/.codex/hooks.json, if Codex is present
Driver | Windows only — offers the CH340 USB driver
Login service | registers a background service that starts at login and restarts if it dies

It refuses rather than guesses. If settings.json does not parse, it changes nothing and says so — the alternative would be writing a fresh file over one you were halfway through editing.

### 3.3 Running at login

This is automatic, and part of install. On macOS it is a launchd LaunchAgent at ~/Library/LaunchAgents/com.overwatch.bridge.plist, with RunAtLoad and KeepAlive set, and a 10-second throttle so a repeatable crash cannot become a spin. Linux gets a systemd user unit; Windows gets a Scheduled Task with an at-logon trigger.

Login, not boot

It starts when you log in, not when the machine powers on — and that is correct rather than a shortcut. The daemon needs your user session to read ~/.claude and to hold the serial port. A boot-time daemon would start earlier and be unable to do its job.

Confirm it with overwatch status, which should say running (launchd, pid N).

## 4Pairing the board

Plug the board in over USB. The daemon finds it on its own — there is nothing to select.

A board that has never seen a computer shows a setup screen with a QR code and an address. This exists because of a hardware fact: the board is an ESP32 behind a USB-to-serial chip, so to a computer it is a serial port and nothing else. It cannot autorun, cannot pretend to be a keyboard and type a URL, and cannot mount a drive with a shortcut on it. Those need native USB, which this silicon does not have. So the board shows the address and a person carries it across.

### 4.1 From the panel

1. Scan the QR with a phone. It opens sleepyunicon.github.io/Overwatch.
2. The code carries a pairing token in the URL fragment, so the page opens already connected to your computer. Browsers never send a fragment to a server, so the secret reaches the page without crossing the network — GitHub never sees it.
3. Follow the install command on the page.

The address printed under the code is deliberately shorter than what the code carries: no scheme, no token. It is the thing a person could reasonably type. Anyone typing it lands unpaired and finishes from the computer instead.

### 4.2 From the computer

The daemon serves a small page on the loopback address only:

http://127.0.0.1:8730

From there you can see whether the board is seen, start the service if it is stopped, and choose the launcher's tiles. The setup screen on the board steps aside by itself as soon as the daemon introduces itself.

## 5Using it

Gesture | What happens
Tap an edge | moves that way. The gauges page has a tap strip on all four sides — ‹ and › mark the left and right, the face cue marks the bottom, and the top goes to settings. Every navigation on this device has a tap path, because a sliding finger on this panel loses contact: one stroke arrives as five or six presses.
Swipe left / right | moves between pages — music, gauges, launcher — when it lands. Tapping always does.
Tap the top edge | settings: theme, edition, the setup QR, factory reset. This is the one direction with no mark on it — the header owns that band and there is nowhere to put one.
Tap the face cue | the idle face, on its own page
Tap a launcher tile | brings that app to the front on your computer — or sends a keystroke, or runs a command (see below)
Tap a panel tile | does that panel's job: snaps a window, mutes your microphone, raises a call
Tap a panel's title | moves to the next panel. The counter beside it — "2/4" — says where you are and that there is more. Swiping works too when it lands; tapping always does.
Long-press the version line | reveals the detail behind it

### The pages

- Gauges — session and week as two rings, with the unit and percentage inside each and a countdown below. A status row appears only when something wants you; the clock holds it otherwise.
- Music — what is playing on your computer, with transport controls.
- Launcher — six tiles, each one an app. The board sends only a slot number; the computer decides what that means, so the mapping changes without reflashing.
- Face — two eyes and a mouth, drawn rather than played, with moods that blend into one another.
- Panels — three pages the computer fills in: your machine, the window in front, and the call you are on. See below.

### The panels

Tap the title to move between them, and read the counter beside it. A sliding finger on this panel loses contact — one stroke arrives as five or six presses — so every navigation on this device has a tap path, and this is the panels' one.

Four pages whose contents come from the computer, not the firmware. The board reserves four slots and draws whatever rows and tiles arrive; it is told nothing about what they mean, and a tap goes back as a slot number and a tile number. So a new panel is a Python file on the computer — no firmware build, no release, no reflash.

- Your machine — disk free, memory free, uptime, and on Linux the temperature and fan speed as well. Titled after the machine's own name rather than its platform, because "This Mac" on a Linux desktop is the kind of small lie that makes everything else suspect.
- Window — which window is in front and which screen it is on, with six tiles: left half, right half, top half, bottom half, fill, and the next display along. The same set macOS offers behind its green button, on the desk instead of behind a menu. Each acts on the display the window is already on, so "Left" on a three-monitor desk means the left half of the monitor you are looking at.
- Meeting — whether you are in a call, and whether your microphone is live. Mute toggles it, Sound silences the speakers, and Show brings the call back to the front.
- Tools — the tools of whichever application is in FRONT, six to a page. Bring Illustrator forward and the panel becomes Illustrator; tap Pen and it selects the pen. It follows the front window rather than the launcher, so it also works after you switch with the keyboard, or for an application that was open before Overwatch was.

Mute means the system microphone

Not the meeting's own mute button. Zoho Meeting, Google Meet and half of Teams run in a browser tab, and driving their buttons would mean guessing each application's keyboard shortcut. The system microphone is one control for all of them, needs no window focus, and — the part that matters for a panel — can be read back, so the row shows what is true rather than what the last tap intended.

The trade-off: the meeting still shows you as unmuted, because as far as it knows you are. Nobody hears you, and the other participants see an open microphone icon. If you would rather drive the application's own button, bind its shortcut to a launcher tile instead.

A call is detected from the browser's open tabs on macOS and from window titles on X11. The Linux side is weaker and says so: no browser publishes its tabs to the window manager, so a call in a background tab will not be seen.

What the panels need, per platform

Panel | macOS | Linux
Your machine | nothing | nothing
Window | Accessibility — System Settings › Privacy & Security › Device Control and Data Access on macOS 27, and Accessibility on macOS 26 and earlier: Apple renamed the same list. Not the Accessibility pane in the sidebar, which configures VoiceOver and Zoom and does nothing for this. Until the grant is given the panel says "Accessibility off" and offers no tiles, rather than offering tiles that would do nothing. | xdotool and wmctrl, and X11. Wayland forbids one program from moving another's windows, so the panel refuses there rather than failing quietly.
Meeting | Automation for your browser, to read tab addresses. The microphone itself needs nothing. | pactl for the microphone, wmctrl to see the call.
Tools | Accessibility, to send the keystroke at all. | xdotool, and X11.

On Windows both panels say "not on this OS" and show no tiles. Only the machine panel works there.

Six tiles wrap, and cost two rows

Up to four tiles sit in one row. Five or six wrap to a second row of three, because six across a 320 px screen would be 41 pixels a button — about five characters, which fits neither "Select" nor "Direct". Three across is 90 pixels and fits everything worth writing.

The second row of buttons stands where the fourth and fifth text rows would be, so a panel with more than four tiles shows three rows of text instead of five. Both halves enforce that: the computer trims the extra rows before sending them and the board declines to draw them.

### The tools panel

Overwatch ships tool sets for Adobe Illustrator, Photoshop and InDesign. Any other application shows "none set" until you name it in ~/.overwatch/tools.json:

{
  "Blender": [
    {"label": "Move",   "keys": "g"},
    {"label": "Rotate", "keys": "r"},
    {"label": "Scale",  "keys": "s"}
  ]
}

Naming an application replaces its shipped set rather than adding to it, so you can remove a tile you do not want. Six is the limit; a seventh would be accepted and never drawn, so it is dropped here instead.

Why the shipped tiles only change tools

Every default is a single key that selects a tool and does nothing else. That is deliberate, and the reasoning is worth knowing before you add your own. A tool shortcut is idempotent — pressing it twice is pressing it once — and visible, because the palette changes where you can see it. Press the wrong one and the next tap undoes it.

Nothing that writes to a document has either property, and a tile is one tap away from work you have not saved. So Overwatch refuses delete, cmd+s, cmd+w, cmd+q and cmd+z even when a config file asks for them. If you want one of those on your desk, put it on a launcher keys tile, where you have had to think about it.

Sending a keystroke needs the same Accessibility permission the window panel does — see the table above, and the note in §6.2 about losing it on every update.

### Launcher tiles that are not apps

The six launcher slots live in ~/.overwatch/apps.json, and a slot can be three things. The board is unchanged by any of it — it still sends a slot number and draws an icon or a label.

[
  "Terminal",
  {"keys": "cmd+shift+4", "label": "Shot"},
  {"run": ["pactl", "set-sink-mute", "@DEFAULT_SINK@", "toggle"],
   "label": "Mute", "icon": "settings"},
  "Visual Studio Code",
  "", ""
]
- A name — the app to bring to the front. On Linux the command comes from the application's own desktop entry, not from the name run as if it were a program.
- keys — a keystroke to send. Write cmd on either platform; on Linux it becomes Super. Needs Accessibility on macOS and xdotool on X11.
- run — a command to start. It is not waited for, so a tile may launch something long-running.
- icon — optional on any of them. One of claude, illustrator, photoshop, spotify, brave, chrome, vscode, terminal, obs, pcsx2, settings. An icon beats a label on the tile; an unknown name is ignored and the label is drawn instead.

run must be a list, never a string

A list is passed straight to the operating system as a program and its arguments. A string would be handed to a shell, and the difference between the two is the difference between running a program called x; rm -rf ~ and running the second half of it. A string is therefore refused outright, as is an empty list — the slot falls back to the stock grid rather than the daemon refusing to start.

The web picker on 127.0.0.1:8730 edits this file too, and keeps hand-written keys and run entries it cannot draw. An earlier version kept only the plain names, so editing any one tile silently erased every command in the file.

### Themes

Light is the default. Dark is in settings. Switching rebuilds the screen rather than restyling it — LVGL keeps no back-reference from a styled object to the colour it was given, so a live switch would mean walking every object on every screen and knowing which role each colour played. Getting one wrong leaves a single unreadable label that nobody finds until a customer does.

## 6Keeping it updated

Two things update, and they ship together from one tag so they always carry the same version number.

### 6.1 The app on your computer

~/.overwatch/bin/overwatch update

It reads a signed manifest from the release feed, checks the signature against a public key compiled into the program, downloads the archive for your platform, verifies its SHA-256, replaces itself and restarts the service.

### 6.2 The firmware on the board

Nothing to do. When the board says hello and its version is behind the feed, the daemon offers the update and the board shows a prompt. Tap it. The whole thing takes under a minute over the cable.

12:48:16 [bridge] ota: offering 2.1.0 (561659 bytes)
12:48:20 [bridge] <- {'t': 'ota_flash'}
12:48:23 [bridge] ota: flashing 2.1.0
12:49:09 [ota] update landed: wanted 2.1.0, running 2.1.0 (from 2.0.9)

A failed update is retried rather than abandoned, and the board asks again after two minutes. If a board is running a protocol this app does not speak, no update is offered at all — the daemon writes the slot in place with no test boot behind it, so "probably fine" is not a good enough basis for the one operation that can leave you holding a device that does not start.

After a self-update — fixed in 2.3.2

Older versions said "the background service is not running" immediately after update, and were wrong. Replacing the running binary invalidates its code signature and macOS kills the old process (last exit reason = OS_REASON_CODESIGNING); launchd restarts it, but the check gave up before it came back.

Not by a little. Measured on 30 September 2026: the bounce went out at 10:21:57, the check gave up at 10:22:02 after its five-second budget, and the new daemon's first log line is 10:22:08 — eleven seconds to start, because macOS has to assess the signature of a freshly written 12.8 MB bundle and its fifty-one inner Mach-O files before it will run any of them. A bounce of a binary already assessed answers in 0.02 s, so the wait is only ever spent when something is genuinely slow. The budget is now thirty seconds and prints a line so it does not read as a hang.

If you are updating from a version before 2.3.2 you will see the old message one last time, because the old code is the code running the bounce. Confirm with overwatch status and carry on.

## 7Uninstalling

~/.overwatch/bin/overwatch uninstall

Removes the login service, takes the status line and hooks back out of settings.json — restoring any status line of yours that was chained behind it — and leaves your own files alone.

It deliberately leaves Codex's trust records in ~/.codex/config.toml and says so, naming the file. Removing them looks tidier and is wrong: under codex exec a distrusted hook is skipped silently, with no prompt and no output, so a reinstall on a headless machine would produce a hook that is installed, correct, registered and permanently invisible.

## 8Troubleshooting

Symptom | What to do
Board sits on "Link the PC daemon" | The daemon is not running or not paired. overwatch status; if the bridge is not running, overwatch install.
"Usage data — none yet" | Open Claude Code once so it renders its status line. Nothing is read until it does.
Board not found | Try a different cable first. Many USB-C cables are charge-only. Four drops in one day traced to one cable, one of them reporting the serial TX path down.
Nothing on screen after flashing by hand | Almost certainly MCUboot written into the app slot. See §21.
"developer cannot be verified" on macOS | You downloaded through a browser. Use the curl line in §3.1.
Setup screen will not leave | Fixed in 2.0.7. Update the app, then unplug and replug the board.
Service "not running" right after an update | A false alarm, fixed in 2.3.2 — and shown one last time by the update that installs the fix. See the note in §6.2. Confirm with overwatch status.
Window or Tools panel says "Accessibility off" | macOS: allow Overwatch under System Settings › Privacy & Security › Device Control and Data Access — on macOS 26 and earlier the same list is called Accessibility. Not the Accessibility pane in the sidebar, which is a different page with the same name. Linux: install xdotool and wmctrl. The panel names which.
There is no "Accessibility" in Privacy & Security | You are on macOS 27, where it is called Device Control and Data Access. Same list, same switch.
It was granted, and stopped working after an update | Expected, and not something the update did wrong. macOS keys that permission to the program's exact bytes, so a new build is a new program to it. Switch Overwatch on again. It will keep happening until the program is signed with a Developer ID.
A panel says "not on this OS" | That panel has no implementation for this platform — window snapping and call detection are macOS and X11 only. Nothing to fix.
Nothing else works | macOS and Windows: the log is ~/.overwatch/bridge.log and it is verbose. Linux: there is no such file — systemd keeps it, so use journalctl --user -u overwatch -n 40. Looking for the file on Linux wasted a day once.

# Part II — What has been built

## 9From BLINK to Overwatch

Overwatch began as a fork of KfirLevy258/Blink and stopped being one.

Forty-eight commits separate it from upstream. The work falls into six strands, described in the sections that follow. The rebrand itself was a deliberate, complete separation rather than a change of name:

What moved | From → to
Name and wordmark | BLINK → OVERWATCH, including the boot animation
State directory | ~/.blink/ → ~/.overwatch/, with a migration that runs once on a real machine
Release feed | upstream's releases → this fork's
Signing key | upstream's public key → this fork's own keypair
Version line | continued at 2.0.0 as its own product
Repository | made public at SleepyUnicon/Overwatch

The migration was the delicate part. It renames the directory, then rewrites every string inside it that names the old one — the two markers that tell uninstall which hooks are ours, and the shims themselves. Renaming the files is not enough: the hook shim computes its own state directory as $HOME/.blink/$sub, so a shim that moved and was renamed still wrote where it always did. That recreated ~/.blink within a minute of the move, on the first hook that fired afterwards.

## 10Hardware bring-up

The board this project runs on is not the one the firmware was written for. A discrete ESP32 DevKitC and a standalone 2.8 inch module were wired on 13 jumpers and brought up on 23 September 2026 — screen, colours, touch, daemon, gauges.

Two findings were worth the trouble and are recorded in firmware/WIRED.md: the SDO wire that stops the board booting (§2.1), and touch arriving inverted on both axes after the panel change, fixed in the device-tree overlay by dropping invert-x and adding invert-y.

## 11The case

Two snap-fit designs, sized to the glass rather than the lit area, written in OpenSCAD and verified numerically rather than by eye — STLs were ray-cast and analysed for shell count and genus after every change.

That verification earned its keep. Six defects were found in geometry that looked correct in a render:

Defect | Cause
USB-C port sealed shut | the cavity used the spigot's width along its whole length; it now steps
All 21 vents sealed | the extrude began at 39 against a wall spanning 38–40
Port and aperture mirrored | the viewer's right is negative x — the whole front had to be unmirrored
Perch protruding 2 mm | unclipped by the tray's inside profile
Corner relief through the wall | only 0.323 mm of material was available; the seat radius now comes from the clearance
desk_cut silently deleted | an over-wide replacement span; OpenSCAD only warns, so the module list is now diffed before and after

The board's slot was also cut to the board — the ESP32 had been 1.6 mm short — and the spigot relieved where the display's connectors begin right at the edge.

## 12Firmware

### 12.1 Pages and theme

A page stack with cross navigation — gauges in the centre, music left, launcher right — plus settings, setup and sleep as overlays. Ten files used to carry their own #define COL_BG, which was survivable while they agreed and stopped being survivable the moment they did not: the gauges moved to white while the widget pages stayed near-black, so one swipe crossed from a white screen to a dark one. Colours now live in one palette structure with a light and a dark set.

### 12.2 The boot animation

The Overwatch wordmark, generated from the logo and encoded as BAN1 delta-RLE clips, replacing upstream's eye animation. The Codex edition gets its own variant with inverted ink. Frames are isolated by connected-component labelling so the mark is separated from its background cleanly.

### 12.3 The face

Two eyes and a mouth, drawn rather than played. The sleep screen used to play encoded clips of about 300 KB each, which is the right shape for one filmed animation and the wrong one for a face with moods: eight expressions times five gaze directions is not a clip library, it is a sprite sheet nobody can edit. The face is five rectangles and a table instead — an expression is a set of numbers and the tick eases toward whichever is current, so every expression blends into every other one for free, at a cost of a few hundred bytes.

### 12.4 The setup screen and QR

A brand-new board shows where to go, because it cannot send anyone there itself. The QR is drawn dark-on-light whatever the theme is doing — a code the theme made pretty and unscannable would fail in exactly the situation it exists for.

## 13The daemon and the web app

### 13.1 Extension without forking

The widget half is a subclass of the upstream bridge rather than an edit to it. Everything is additive, and unknown message types still fall through to the original handler, which ignores them exactly as before. That keeps upstream's releases from becoming merge conflicts.

### 13.2 The local page, and the security around it

The daemon serves a small page on 127.0.0.1:8730. Making it useful to a page hosted on GitHub Pages meant closing several holes at once:

- Origin allowlist plus loopback, rather than a wildcard.
- A pairing token in a header, compared with a constant-time comparison, stored at ~/.overwatch/pair.json with mode 0600.
- Private Network Access headers, so a public page is permitted to reach a loopback service at all.
- A CSRF hole closed — simple requests need no preflight, so the state-changing routes were made to require the token and the pairing route made same-origin only.

### 13.3 The setup site

A page on GitHub Pages that opens with the same animation the device plays, lays the steps out as tiles, and — once paired — mirrors the device's own UI so you can assign launcher tiles by clicking the picture of the thing on your desk. Phone detection is done in CSS rather than JavaScript, after innerWidth was measured reporting 1190 on a 375-pixel viewport.

## 14Updates and release engineering

A release is one tag carrying the firmware and four platform binaries, with a manifest signed on the maintainer's machine — the release key never reaches CI.

Property | How
Integrity | ECDSA P-256 over a manifest naming each file's SHA-256
Firmware safety | MCUboot; signed is not the same as confirmed, and an unconfirmed image reverts after 90 seconds
Pinned downloads | fetches are pinned to the release tag, not /latest/ — a release published mid-download once produced two halves of different builds
Retry | a failed update is offered again after two minutes, through a door of its own

## 15Testing and CI

Two suites, both gating merges.

Suite | What it covers
installer 66 jobs | 1,525 Python tests on four OS/version cells; the shipped binary built and smoke-tested on three platforms; 15 real install scenarios per platform including a spaced home, an unreadable settings file and install → uninstall → install; self-update against a locally signed feed; the shims under dash, busybox and bash; and a watch on Claude Code's status-line contract across four versions
firmware host tests 19 suites, 1,370 checks | the firmware's pure logic compiled and run on a plain runner — parsing, layout geometry, colour contrast, sleep gating, boot-clip decoding, update prompts

There is also a fleet harness that drives a real board on a real desk, and a gate that refuses to cut a release without a green run for that exact commit. It is currently overridden — see §22.

## 16The most recent work, in detail

Three pieces of work completed 26–28 September 2026.

### 16.1 macOS signing and notarisation

The pipeline is written, wired into the release workflow, and dormant. With no certificate in the repository's secrets every step prints why the build is unsigned and exits successfully — which means the credential-free path is exercised on every push rather than discovered on the first release after somebody adds a certificate.

The finding that shaped it is worth stating plainly, because it would otherwise have surfaced at two in the morning after paying Apple:

The hardened runtime breaks a PyInstaller binary

Notarisation requires the hardened runtime. The hardened runtime enables library validation, which refuses to load any library whose Team ID differs from the process's own. Signing all 53 Mach-O files ad-hoc with --options runtime produces a binary that does not start at all:

Failed to load Python shared library '.../_internal/Python':
  ... not valid for use in process: mapping process and mapped
  file (non-platform) have different Team IDs

An ad-hoc signature carries no Team ID, so nothing can match anything. The hardened runtime is therefore set only on the Developer ID path, where all 53 files share one identity.

Because that last part cannot be rehearsed without a paid certificate, the signing script's final act is to run the binary it just signed and refuse to pass it on if it does not start — naming the entitlement escape hatch if the failure is that one.

Other details settled: the embedded Python.framework is signed as a bundle, not as the bare Mach-O inside it; every file is verified individually, because --deep says nothing about a one-directory build; and there is deliberately no stapling, since a ticket cannot attach to a loose executable or a tarball.

Enabling it needs six repository secrets and an Apple Developer membership. The steps are in docs/notarisation.md.

### 16.2 The Windows test suite

The installer workflow had been red on every push for weeks: 64 passing, two failing, and the Windows job's 17 failures had been read as path noise. Two of them were the product being broken on Windows.

Cause | Detail
Migration did nothing real bug | The rewrite built its search strings from os.sep, so on Windows it looked for \.blink\blink-hook.sh. Every string it has to rewrite there is spelled with forward slashes — the shims are POSIX sh, and the commands in settings.json go through a helper that converts every backslash because a backslash is an escape under Git Bash. So a Windows migration moved the directory and left every reference inside it pointing at the old one, which the hook shim then recreated on the next tool call.
Mixed-separator path real bug | expanduser("~/.codex") replaces the tilde and leaves the slash alone, giving C:\Users\k/.codex. Windows opens it happily, so it went unnoticed — but it is not string-equal to the native spelling, so anything comparing or printing it disagreed with everything else, including the path shown to the user during uninstall.
Tests pinned to one platform 15 failures | Seven hardcoded sh <shim> <event> where Windows deliberately emits bash; three set HOME but not USERPROFILE, so they wrote to one directory and read another; one used chmod(0o000), which on Windows only toggles read-only; one asserted behaviour that cannot exist there.

One of the seven had been passing on Windows while proving nothing: its "customer wrapper around our command" did not mention the command at all on that platform.

### 16.3 The firmware host tests — and a real regression

Three suites had been failing. All three were telling the truth.

#### What's New overran its page

Seven release-note lines were over the 33-character limit, up to 36. Past that the label wraps, and a wrapped line is a row the pagination arithmetic did not count, so the text overruns the page it was measured for.

#### Dark mode shipped the palette the test exists to forbid

The contrast suite kept its own copy of eight colours and grepped the view source to prove they still agreed. When the scattered colour defines were gathered into a theme file, those defines stopped containing values — so the grep matched nothing and reported all eight as drifted, which read as noise about a file move.

It was hiding this. Every WCAG rule had been running against the copy, and the copy was a set of values that by then existed nowhere. Meanwhile the real dark palette had been filled in from the widget pages, which had never had the severity ramp fixed. Dark mode was shipping:

band spread   2.30x   (amber 11.39:1 over red 4.95:1)   need <= 1.35
green sat     0.775   (the "green looks grey" fault)      need >= 0.85
red   sat     0.740

An inverted severity ramp — loudest at "getting close", quiet at "critical" — and a green that reads as grey at 60 cm. Both had already been fixed once on the gauge screen; gathering the palettes handed them back.

Fixed in 2.1.0

The dark ramp is restored to the measured trio: 1.16x spread, saturation 0.92 and up. The test keeps no copy — it parses both palettes out of the theme file and checks both, and an unreadable file is now a failure rather than a skip.

#### The layout test was two revisions behind a correct screen

Here the firmware was right every time. A dead constant the caption had stopped using; an arc position that moved deliberately and an assertion that did not follow; a percentage that is no longer centred alone because a unit line was stacked above it; and a hardcoded brand edge that was the left edge of a centred "BLINK", summed by hand from the font table, for a word that is now nine glyphs and sits at the right bezel.

Three numbers the screen depends on were prose rather than constants, which is how they went stale unseen. They are constants now, and the test reads them.

## 17Release history

Version | What changed
2.4.5 | Tap the edges to move pages · Arrows now show you where
2.4.4 | Every button is on the screen · The window page has room
2.4.3 | Snap windows on any monitor · Halves, top, bottom and next
2.4.2 | Tap the title to change panel · It shows which one you are on
2.4.1 | Panels say what they need · And where to switch it on
2.4.0 | Your app's tools on the desk · Six buttons on a panel now
2.3.2 | No false alarm after updating
2.3.1 | Updates know when they worked · A stuck one says what to do
2.3.0 | Mute your mic from the desk · Snap windows where you want
2.2.5 | The panel names your machine · Temperature and fans on Linux
2.2.4 | The desk panel works on Linux
2.2.3 | The launcher finds Linux apps
2.2.2 | Music really works on Linux now
2.2.1 | Music controls work on Linux
2.2.0 | A page your computer can fill · It says why it will not link
2.1.0 | In dark mode, red means red · Update notes fit their page
2.0.9 | The face stays on its own page
2.0.8 | A failed update can be retried
2.0.7 | The setup screen steps aside
2.0.6 | Scan the code to pair a computer
2.0.5 | A QR to set up on any computer · Pick launcher apps on the web
2.0.4 | A setup page from the first boot
2.0.3 | Codex edition boots to the mark · A smaller, cleaner boot clip
2.0.2 | A face with moods when idle · It naps after a minute
2.0.1 | It boots to its own mark now · Updates arrive over the cable
2.0.0 | Five pages, swipe between them · A launcher, music, a light theme

Twenty-six releases between 25 and 30 September 2026, plus an initial 0.1.0 on 23 September. Each carries firmware and four platform binaries under one tag. The board shows the same notes on its own screen, sixteen releases deep; older entries are trimmed from the tail as new ones arrive, because the page array it draws them into holds sixteen.

# Part III — Reference

## 18Commands

Command | What it does
overwatch install | set everything up — the default if you run it with no arguments
overwatch uninstall | put it all back
overwatch status | is the panel getting data? Add --wire to see the frame the bridge would send
overwatch update | fetch a newer version of the app
overwatch config | choose which apps the launcher shows
overwatch run | run the bridge in the foreground
overwatch driver | install the board's USB driver (Windows)
overwatch flash | put firmware on a blank board (kit builders)
overwatch provision | stamp a unit's edition (factory step, once)

## 19Where things live

Path | What
~/.overwatch/bin/overwatch | the installed program — what the login service runs
~/.overwatch/bridge.log | the log, and it is verbose
~/.overwatch/apps.json | the launcher's six slots
~/.overwatch/pair.json | the pairing token, mode 0600
~/.overwatch/board.json | what is known about the board
~/.overwatch/*-installed-command* | markers proving which entries in settings.json are ours
~/.overwatch/overwatch-{hook,statusline}.sh | the shims Claude Code runs
~/Library/LaunchAgents/com.overwatch.bridge.plist | the login service, macOS
~/.claude/settings.json | edited by install; yours is chained, not replaced
~/.codex/hooks.json | the Codex registration

## 20Repository layout

Directory | Contents
firmware/src/ | the C the board runs — pages, theme, face, boot clips, OTA, protocol
pc/ | the daemon: bridge, ingest, providers, widgets, install, update, webconfig
tests/ | 1,525 Python tests, 19 firmware host suites, CI scripts, fixtures
tools/ | build, release, signing, flashing, encoders, the fleet harness
case/ | OpenSCAD sources for both case designs
docs/ | the setup site, the full README, design notes, open bugs

## 21Rules learned the hard way

Never use west flash on this board

It writes MCUboot into the application slot at 0x20000 and the screen goes dark. Flash with explicit esptool offsets instead: MCUboot at 0x1000, the application at 0x20000.

Rule | Why
Release notes: 33 characters, hard | Beyond that the label wraps and the page overruns. Seven lines shipped over it because nothing was running the test that says so.
Zephyr 4.3.1, SDK 0.17.4 | 4.4.0 cannot build this firmware: its mbedTLS removed the header the OTA code includes, and its LVGL moved a field the settings screen reads.
Never expanduser("~/x/y") for a path you will compare | It leaves the slashes alone and produces a mixed-separator path on Windows.
Redirect HOME and USERPROFILE | Python reads the first on POSIX and the second on Windows.
A test that duplicates what it checks can be green about a broken product | The contrast suite was, for weeks. Read the source; do not copy it.
A skip is not a statement about behaviour | If a platform genuinely differs, assert the difference.
Code that has never run does not work | A sealed port, sealed vents, a stuck setup screen, a dead retry and a WiFi build that would not link all reached the tree looking correct.
Try a different cable first | Most "the board is gone" reports were one charge-only cable.

## 22Open threads

Item | State
Notarisation | Pipeline written and exercised on every CI run in its credential-free mode. Needs an Apple Developer membership and six repository secrets. No code changes required. Deferred on cost.
Fleet gate | Fails on a reproducible ~14.4 s delay before the daemon's first traffic, against a 4 s budget. The OTA feed has been ruled out at 0.9 s; the lead points at the service-and-lock handover. Releases currently run with the gate overridden.
WiFi OTA | Parked. The image does not link — 18,020 bytes over dram1_0_seg. Two candidate knobs were verified applied and neither moved it. Needs memory-layout work.
False "service not running" | Cosmetic but fires on every macOS self-update. The confirmation check gives up during the gap between the code-signing kill and launchd's restart.
Ring asymmetry | 35 px above, 45 below, after the face cue was redrawn smaller. Under what anyone notices; the test bounds it rather than the dials being moved.

Overwatch 2.1.0 · document generated 28 September 2026 · github.com/SleepyUnicon/Overwatch

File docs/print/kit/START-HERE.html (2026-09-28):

# Overwatch @VERSION@ — build sheet

One unit, start to finish. Work through the three numbered folders in order; that is the whole procedure.

Folder | What happens there
1-print-the-case | Two printed parts. Pick one of the two designs.
2-flash-the-board | One command. Puts the software on the board.
3-hand-it-over | What your friend runs on their own computer.
Overwatch-Manual.pdf | Everything else. Not needed to build a unit.

The one mistake worth avoiding

Flash the .bin in 2-flash-the-board. Do not download overwatch-fw.bin from the releases page and flash that.

They look interchangeable. The file here holds the bootloader and the program. The one on the releases page is the program alone — meant for a board that already works, updating itself. Flash the wrong one and the board stays dark with no error, looking exactly like a bad solder joint.

## 1Print the case

Two parts, no screws, no supports in the orientation given. Choose by shape — WHICH-DESIGN.txt in that folder has the same summary:

Design | Shape | Print it
upright-frame | A picture frame, screen vertical. 46.2 mm front to back assembled. | bezel face down tray open side up
wedge | Slanted screen on a flat base. The newer design — everything enters from underneath, so there is no seam anywhere you look at it. | shell on its back base flat

notes.md in each folder carries the exact dimensions, the tolerances, and the OpenSCAD line to regenerate the STLs if you change anything.

## 2Flash the board

If you are using a separate ESP32 and panel rather than an all-in-one CYD, wire it first — wiring-discrete-esp32-only.md. On a CYD there is nothing to wire.

SDO / MISO stays disconnected

It would land on GPIO 12, which the ESP32 reads at power-on to choose its flash voltage. A wire there stops the board booting at all — and it is the last thing you would suspect, because the module's silkscreen invites you to fit it.

Plug the board in over USB, then, from inside that folder:

overwatch flash --image overwatch-@VERSION@.bin

It finds the board, stops the daemon so the serial port is free, writes the image and verifies what it wrote. A minute or two, and the screen stays dark the whole time — that is normal. Do not unplug it.

The board reboots by itself and should light up. If it stays dark, esptool has already verified the firmware, so the flash is not the problem — check the wiring and the panel.

Only for a unit that should boot to the Codex mark instead of the Overwatch one:

overwatch provision --edition codex

## 3Hand it over

Everything from here happens on your friend's computer. They need Claude Code 2.1.100 or newer. One line in a terminal — the four platforms are in install-commands.txt, and INSTALL-CARD.pdf is the page to hand over with the unit.

curl -fsSL https://github.com/SleepyUnicon/Overwatch/releases/latest/download/overwatch-macos-arm64.tar.gz | tar xz && ./overwatch/overwatch

Tell them to paste the command, not click a download link

macOS quarantines browser downloads and refuses to run them — "cannot be opened because the developer cannot be verified". curl sets no such flag. This is the single most likely thing to go wrong at handover.

Then they plug the board in. It finds itself, the setup screen steps aside as soon as the software says hello, and the board keeps itself updated from then on. No account, no WiFi, no cloud.

## 4Check it before it leaves

overwatch status

Bridge      running (launchd, pid N)
App         @VERSION@
Board       /dev/cu.usbserial-XXXX -- id XXXXXXXX, firmware @VERSION@
Claude Code 2.1.238

App and Board must show the same version. They ship from one tag, so a mismatch means one half is stale.

## 5Keeping their unit stable while yours is not

Boards check /releases/latest/, and GitHub's "latest" deliberately skips pre-releases. So you can experiment freely on your own unit:

You want | Command
Everyone gets it | bash tools/release.sh
Only your test bed | OVERWATCH_PRERELEASE=1 bash tools/release.sh then put it on your own board by cable: python3 tools/package_firmware.py && overwatch flash
Promote one later | gh release edit vX.Y.Z --prerelease=false

Nothing reaches a friend's board until you cut a normal release.

Overwatch @VERSION@ · kit image sha256 @SHA256@

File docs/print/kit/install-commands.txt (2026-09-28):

WHAT YOUR FRIEND RUNS
=====================

On THEIR computer, in a terminal. One line. Pick their platform.

They need Claude Code 2.1.100 or newer - older versions do not put the
usage figures where Overwatch can read them.

macOS, Apple Silicon (M1 and later)
-----------------------------------
curl -fsSL https://github.com/SleepyUnicon/Overwatch/releases/latest/download/overwatch-macos-arm64.tar.gz | tar xz && ./overwatch/overwatch

macOS, Intel
------------
curl -fsSL https://github.com/SleepyUnicon/Overwatch/releases/latest/download/overwatch-macos-x86_64.tar.gz | tar xz && ./overwatch/overwatch

Linux
-----
curl -fsSL https://github.com/SleepyUnicon/Overwatch/releases/latest/download/overwatch-linux-x86_64.tar.gz | tar xz && ./overwatch/overwatch

Windows, in PowerShell
----------------------
curl.exe -fsSL -o overwatch.zip https://github.com/SleepyUnicon/Overwatch/releases/latest/download/overwatch-windows-x86_64.zip && tar -xf overwatch.zip && .\overwatch\overwatch.exe

Or just send them here, and the page offers the right one:

    sleepyunicon.github.io/Overwatch

*** TELL THEM TO PASTE THE COMMAND, NOT TO CLICK A DOWNLOAD LINK. ***

macOS marks anything downloaded by a browser as quarantined, and refuses
to run it: "cannot be opened because the developer cannot be verified".
curl does not set that flag, so the command above just works. This is the
single most likely thing to go wrong when you hand a unit over.

THEN
----

They plug the board in. It finds itself. The setup screen on the panel
steps aside as soon as the software says hello, and the board keeps
itself updated from then on.

Nothing else to configure. No account, no WiFi, no cloud.

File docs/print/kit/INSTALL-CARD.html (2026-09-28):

OVERWATCH

Setting it up — about two minutes

This little screen shows how much of your Claude Code and Codex usage you have left, as two dials, always in view. It plugs into your computer over USB. There is no account to make, no WiFi to set up, and nothing running in the cloud.

## 1Open a terminal and paste one line

Pick the line for your computer. It downloads the program and sets everything up — you can delete the folder it leaves behind afterwards.

#### macOS — Apple Silicon (M1 and later)

curl -fsSL https://github.com/SleepyUnicon/Overwatch/releases/latest/download/overwatch-macos-arm64.tar.gz | tar xz && ./overwatch/overwatch

#### macOS — Intel

curl -fsSL https://github.com/SleepyUnicon/Overwatch/releases/latest/download/overwatch-macos-x86_64.tar.gz | tar xz && ./overwatch/overwatch

#### Linux

curl -fsSL https://github.com/SleepyUnicon/Overwatch/releases/latest/download/overwatch-linux-x86_64.tar.gz | tar xz && ./overwatch/overwatch

#### Windows — PowerShell

curl.exe -fsSL -o overwatch.zip https://github.com/SleepyUnicon/Overwatch/releases/latest/download/overwatch-windows-x86_64.zip && tar -xf overwatch.zip && .\overwatch\overwatch.exe

Not sure which? Open sleepyunicon.github.io/Overwatch and the page offers the right one.

Paste the command — do not click a download link

macOS marks anything downloaded by a browser as untrusted and refuses to run it: "cannot be opened because the developer cannot be verified". The command above does not trip that. If you have already hit it, delete what you downloaded and use the command instead.

## 2Plug the screen in

Over USB, to the same computer. It finds itself — there is nothing to choose. The setup screen on the panel steps aside within a few seconds, and the dials come up.

## 3Open Claude Code once

The numbers come from Claude Code's own status line, so nothing appears until it has drawn one. Open it, run anything, and the dials fill in.

You need Claude Code 2.1.100 or newer. Older versions do not publish the usage figures at all.

## Using it

Swipe left or right | music, dials, app launcher
Tap the gear | settings — light or dark theme
Tap the little face | it has moods
Leave it alone | the face takes over the screen

## If something looks wrong

Panel says "Link the PC daemon" | run overwatch status in a terminal
Dials are empty | open Claude Code once
Nothing happens when plugged in | try a different USB cable. Many are charge-only.

It updates itself from then on — both halves — and asks before it does. To remove it completely, overwatch uninstall puts everything back.

Overwatch @VERSION@ · open source, free, noncommercial · github.com/SleepyUnicon/Overwatch

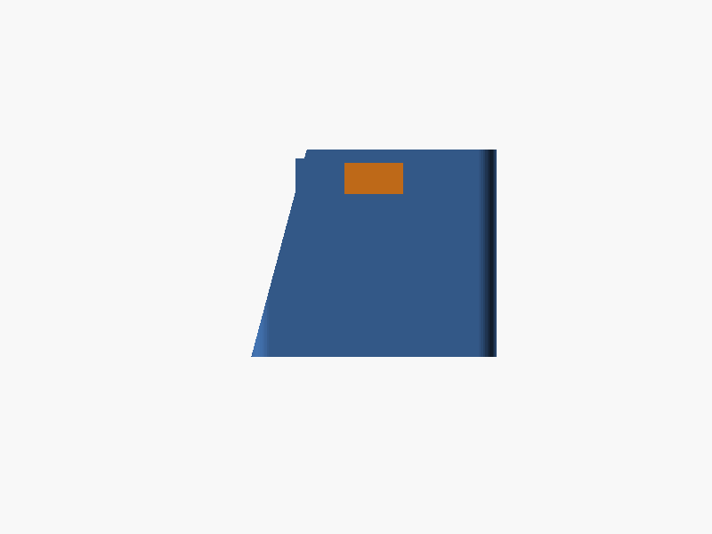
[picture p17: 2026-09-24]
case/5_assembled_side.png

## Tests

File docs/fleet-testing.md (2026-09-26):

# Fleet testing

CI proves the pieces. It cannot prove the product, because no runner has a
board on a USB cable, an account signed in, or a login service that has been
running since somebody's last reboot. This suite does: it drives the **real
daemon** against a **real board** on three desks -- a Mac, an Ubuntu machine
and a Windows 10 machine -- and `tools/release.sh` refuses to build a release
until it has.

One run stops the installed service on three machines and takes their boards
for the best part of ten minutes. That is the cost, and it buys the only
evidence anyone has that a tag runs on hardware.

## The one command

```bash
python3 tools/fleet/run.py
```

Needs Python 3.11 or newer (it reads the inventory with `tomllib`), and can be
started from anywhere -- it resolves this checkout from its own path.

For each desk it takes a snapshot of **HEAD** (`git archive` piped into `tar -x`
over ssh), deletes the previous `result.json` on the far side in the same
command that unpacks the snapshot, runs `python -m tests.fleet.agent` there,
and copies the result back. The three desks run at the same time -- one board
each, no shared state. The verdicts are printed as a table and written to
`.fleet/last_run.json`, which is the file the release gate reads.

HEAD, not the working tree. Uncommitted edits are not on the desks and are not
what was proved, so commit first.

### What happens on one desk, in order

1. **The install and update scenarios**, if bundles were named. Neither goes
   near the serial port, so they run before anything is taken away from
   anybody, and a desk with its board unplugged still answers for them.
2. **The installed service is stopped.** Only one process can hold a serial
   port. Nothing is installed, moved or deleted -- a plist, a unit file and a
   Scheduled Task are all left exactly as they were found.
3. **A preflight pass**: a daemon with no scenario, up to three attempts of 15
   seconds, waiting for one message the board sends of its own accord.
   `launchctl bootout` returns before the port is actually free, so the first
   refusal is not taken as an answer. This pass also warms the run's release
   manifest cache, which is why the firmware Install prompt (below) appears at
   most once.
4. **The scenarios**, in name order: `overage`, `sleep_wake`, `stale_age`,
   `usage_climb`.
5. **The real-account pass**, unless `--no-real-account` was given.
6. **The service is started again**, from a `finally`, on every path including
   the ones that raise.

### How long it takes

The four scenarios are about four minutes of wall clock, of which `sleep_wake`
is roughly half: it contains a deliberate 45-second silence, because that is
the only thing that makes this board sleep. With the preflight and the
real-account pass a desk is busy for five to eight minutes, and the desks run
in parallel, so that is roughly the length of the whole run. Bundles add a few
minutes more per desk -- unpacking 50 MB and an installer that self-tests the
copy it made.

The orchestrator allows two hours per desk (`--timeout`) before it gives up on
one. That is generous on purpose, and it is also arithmetic rather than a round
number: the customer-path scenarios run first and allow seven minutes per
program call, so the whole of that phase has to fit inside the desk's budget
with the four board scenarios still to come. A per-desk timeout is reported as
a failed release, and slow is not broken.

### Seeing the commands without running anything

```bash
python3 tools/fleet/run.py --dry-run
```

```
galit-win10 (windows, galit@lenovo-r90r7u44.lan):
  push: ['ssh', '-o', 'BatchMode=yes', '-o', 'ConnectTimeout=20', 'galit@lenovo-r90r7u44.lan', 'mkdir "%USERPROFILE%\\overwatch-fleet" 2>nul & del /q "%USERPROFILE%\\overwatch-fleet\\result.json" 2>nul & tar -x -f - -C "%USERPROFILE%\\overwatch-fleet"']
  run : ['ssh', '-o', 'BatchMode=yes', '-o', 'ConnectTimeout=20', 'galit@lenovo-r90r7u44.lan', 'cd /d "%USERPROFILE%\\overwatch-fleet" && python -m tests.fleet.agent --board codex --out result.json --real-account']
  pull: ['scp', '-o', 'BatchMode=yes', '-o', 'ConnectTimeout=20', 'galit@lenovo-r90r7u44.lan:overwatch-fleet/result.json', '<temporary file>']
...
Nothing was run and no desk was contacted.
```

It contacts nothing and, alone among the run modes, leaves
`.fleet/last_run.json` alone -- every other run deletes it before it starts, so
that a run which dies halfway leaves no file rather than last week's green one.
The Windows line is the reason this flag exists: it is built for a shell that
cannot be tested anywhere but on that desk.

### Narrowing a run

| Flag | Means |
|---|---|
| `--only local-mac,kfir-ubuntu` | These desks, by their inventory names |
| `--scenarios overage,stale_age` | These scenario names, on every desk |
| `--state .fleet/scratch.json` | Write the verdict somewhere else |
| `--no-real-account` | Skip the pass against each desk's own account |
| `--timeout 3600` | Seconds to allow one desk |

Both narrowing flags are recorded in the result, and **the release gate refuses
a run that used either** -- see [The release gate](#the-release-gate). Use
`--state` whenever you narrow, so an experiment does not delete the verdict
from the full run you meant to release on.

Exit status is 0 when the fleet passed, 1 when it did not, and 2 for an
inventory that will not load or an `--only` naming a desk that does not exist.

### Where the evidence lands

Only `result.json` comes home. Everything else stays on the desk that produced
it, under the workdir named in the inventory:

```
~/overwatch-fleet/result.json                      # the verdict, copied back
~/overwatch-fleet/fleet-work/overage/tap.jsonl     # every message on the wire
~/overwatch-fleet/fleet-work/overage/tap.jsonl.log # the daemon's own output
~/overwatch-fleet/fleet-work/preflight/            # the settle attempts
```

When a desk goes red and its sentence is not enough, those two files beside
each other are the whole story: what crossed the wire, and what the daemon
thought it was doing at the time.

**Everything under `fleet-work/` is from the run you are looking at.** The
workdir survives between runs, but each pass empties its own directory before
its daemon starts -- transcript, daemon log and all -- so what is on the disk
is what this run's daemon wrote and nothing else. The verdict is a count over
those records, and a transcript that accumulated across runs would let a desk
whose board was unplugged pass on last week's evidence: a daemon that writes
nothing at all is exactly what an unplugged board, a held port and a wedged
daemon all look like from here. Copy a transcript elsewhere if you want to
keep it; the next run will not.

The one thing that spans two daemons is `sleep_wake`, which is one directory
and one transcript for both of its passes -- the wake has to be readable in
the same file as the frames either side of it.

## The inventory

`tools/fleet/fleet.toml` is one `[hosts.<name>]` table per desk, and **one
entry per machine**: two entries sharing an `ssh` line, or two with none
(which both mean this machine), are refused, because the desks run in
parallel and two agents on one machine would stop and start the same login
service, unpack into the same workdir and compete for the one serial port --
with the loser's failures reading as a dead board. Every field is
required, and a malformed inventory is refused before anything is touched --
the alternative is stopping two desks' services, discovering the third has no
`python` line, and leaving somebody's board dark over a typo.

| Field | Means |
|---|---|
| `ssh` | The ssh destination. **Empty means this machine**, which is then run locally with no ssh at all. |
| `os` | `darwin`, `linux` or `windows`. Windows means the remote shell is `cmd.exe`, which changes how every command line is built. |
| `board` | `claude` or `codex` -- which edition of the board is on that desk. |
| `python` | An interpreter on that machine **that has pyserial**. |
| `workdir` | Where the snapshot is unpacked and the agent runs. Created if absent; it survives between runs, though the transcripts under it do not -- see [Where the evidence lands](#where-the-evidence-lands). |
| `has_claude_desktop` | Recorded in that desk's result for the reader. The orchestrator does not act on it. |

There is deliberately **no port** in this file. The daemon finds the board by
USB vendor and product ID (CH340, `0x1A86:0x7523`), which is how it picks COM15
out of the Windows desk's twelve mostly-Bluetooth COM ports. A port written
down here would work until somebody moved the cable to the next socket, and
would then fail as a dead board. `run.py` has no `--port` flag for the same
reason.

`python` is named per desk rather than assumed, because the agent spawns the
daemon and the daemon imports `serial` at module scope: on the Mac only
`.venv-test` has pyserial, and a system Python would fail as a board fault.
Checking it is a one-liner per desk and is worth doing before blaming the
hardware:

```bash
/usr/bin/python3 -c "import serial; print(serial.__version__)"
```

A relative `python` path on the **local** desk is resolved against this
checkout, not the workdir -- the fleet venv lives in the source tree and is
gitignored, so it is not inside the snapshot that gets pushed.

### Moving a board between desks

Edit `board =` on both desks. Nothing else: no port, no serial number, no
per-desk scenario.

The `board` values carry a `# VERIFY before the run` comment because they are
the one thing in the file the suite cannot check for itself. A `codex` value
makes the agent replay the same timeline attributed to Codex, in a copy of the
scenario file; the board applies whatever frame it is given and prints its
`[usage] session ...` line either way. So a stale `board` value does not go
red -- it quietly proves the wrong page. That is a job for the person at the
desk, which is also why the panels are worth watching while a run goes by.

## Scenarios

A scenario is a JSON file in `tests/fleet/scenarios/`. Its file stem is its
name everywhere: in `--scenarios`, in the result table, and in the problem
sentences. `OVERWATCH_SCENARIO` replaces the daemon's entire provider set with the
one that replays the file, so a real Claude install on the desk cannot merge
its own readings into the timeline and change what the assertion means.

Here is `stale_age.json`, with its `note` shortened:

```json
{
  "name": "stale_age",
  "note": "Percentages hold constant across all three steps -- the subject is age, not movement. AGE_CAPTION_MIN_S is 600s (firmware/src/usage_view.c), so the two aged steps sit well past it (30 min, 4 hours). This path has shipped twice and never been confirmed on real hardware; it matters more than the other three files.",
  "steps": [
    {"at": 0,  "provider": "claude", "session_pct": 55.0, "weekly_pct": 30.0, "state": "running", "age_s": 0,     "stale": false},
    {"at": 6,  "provider": "claude", "session_pct": 55.0, "weekly_pct": 30.0, "state": "running", "age_s": 1800,  "stale": true},
    {"at": 12, "provider": "claude", "session_pct": 55.0, "weekly_pct": 30.0, "state": "running", "age_s": 14400, "stale": true}
  ],
  "duration_s": 20,
  "expect": {"min_tx": 3, "min_board_usage": 3, "min_stale_lines": 2, "min_sleep_wakes": 0}
}
```

| Key | Means |
|---|---|
| `name`, `note` | For the reader. `note` is where the reason this file exists goes. |
| `steps[].at` | Seconds since the provider was constructed. A step fires **once**, when elapsed time reaches it: a step is an event, not a level. One step per poll, oldest first -- a poll becomes a single usage message however many steps have come due, so the replay delays a late timeline rather than collapsing it. |
| `steps[].age_s` | How old the reading claims to be (`observed_at = now - age_s`), so a step can be four hours old the instant it fires. Defaults to 0. |
| Other `steps[]` fields | A usage frame as plain JSON -- `provider`, `session_pct`, `weekly_pct`, `state`, `stale`. A field name that does not exist on the frame drops that step, with a line on stderr, rather than taking the daemon down on three machines. |
| `duration_s` | How long the daemon runs. The agent adds its own grace on top for the last frame to be polled, sent and applied. |
| `host_silence_s` | Seconds with the **daemon stopped** in the middle. Only a scenario that has this sleeps. |
| `wake_duration_s` | How long the second daemon runs, after the silence. |

### The expect block

All four keys are required and none of them defaults. A key that fell back to
zero when it was missing would delete its own assertion -- a `stale_age`-shaped
run with no STALE lines in it once passed while `min_stale_lines` was merely
absent. A scenario that means to assert nothing on a dimension writes an
explicit `0`, where a reader can see the decision -- except for `min_tx` and
`min_board_usage`, which must be at least 1: a block asking for zero frames
sent and zero applied would be satisfied by a board that never woke up, and is
refused as a scenario that asserts nothing.

- **`min_tx`** -- usage frames that actually went out. Counted as `tx` records
  whose message type is `usage` **and** which the daemon reported writing. The
  `time` message every poll also sends does not count, and neither does a frame
  the daemon refused: `send()` drops a line over the board's 512-byte limit, and
  a loaded two-provider frame already measures 484, so a refused frame is a live
  failure mode. It never reached the board, and counting it would credit the
  board for work it was never given.
- **`min_board_usage`** -- `[usage] session ` lines the **board** printed on its
  own console. There is no ack in the protocol: the board's entire host-bound
  vocabulary is `hello`, `ping`, `pref`, `ota_query` and `ota_flash`, and none
  of it is sent per frame. The firmware prints that line once per applied frame,
  unconditionally, and it is the only end-to-end evidence there is.
- **`min_stale_lines`** -- how many of those applied lines carried `STALE`.
- **`min_sleep_wakes`** -- how many times `[sleep] host back; opening eyes` was
  followed, later in the transcript, by an applied frame. Both halves are
  required because both halves are the feature: a board that wakes and shows
  nothing has failed exactly as badly as one that never wakes.

Sleep is a daemon-**lifecycle** event, not a data event. The firmware stamps
its last-host time on any host protocol line and the daemon answers every
ten-second ping with a pong, so no poll interval leaves the board 30 seconds
silent while a daemon is alive. Quiet data is not a quiet host. That is why
`sleep_wake` is run in two passes with the daemon killed in between, and why
its `min_tx` is twice its step count: the second daemon replays the timeline
from its own start.

### Adding one

1. Write the file, named after what it proves -- but not `home`, `preflight`,
   `real_account`, `fresh_install` or `update_path`, which are directories the
   run makes for itself and are refused as scenario file names. The **file
   name** is what the scenario's working directory is called, and that
   directory is emptied before the pass starts; the `name` inside the JSON is
   what the run calls the scenario in its sentences. Keep the two the same --
   a test pins it for the shipped files.
2. Keep steps **at least 4 seconds apart**, which is longer than a fleet run's
   3-second poll. The provider hands the daemon **one step per poll**, so
   steps closer together than a poll cycle still all reach the board but
   later than the file says, and `duration_s` stops describing what actually
   happens. A daemon kept waiting for a busy port starts its timeline early
   for the same reason; the agent reports a run whose first traffic came more
   than 4 seconds late as *inconclusive* rather than failed, and that
   tolerance is what the spacing has to survive.
3. Set `duration_s` past the last `at`. The daemon polls every 3 seconds during
   a fleet run (the shipped interval is 60, at which a thirty-second scenario
   would produce one frame and never reach the sequence under test).
4. Write all four `expect` keys, counting `min_tx` yourself -- and doubling it
   if the scenario has a `host_silence_s`.
5. Try it on one desk before it goes to three:

```bash
python3 tools/fleet/run.py --only local-mac --scenarios my_scenario \
    --state .fleet/scratch.json
```

A name that matches no file is refused rather than skipped, on both sides: a
typo in `--scenarios` would otherwise produce a green result that proves less
than the operator believes it does.

## The real-account pass

Every scenario replays an invented timeline. That proves the wire and the
firmware and says nothing at all about whether a desk can read the tools
installed on it. So one pass per desk runs with **no scenario and the
operator's real home directory** -- the only time in the run that the daemon
sees the real account.

**Each machine has to be signed in** to whatever it is supposed to be reading:
Claude Code, Codex CLI, and Claude Desktop on the desk whose inventory entry
says `has_claude_desktop = true`. A desk that is signed out fails this pass and
only this pass, which is exactly the signal wanted -- the other four scenarios
would sail past it.

It asserts three things:

1. Within 120 seconds, a usage frame carrying a real `session_pct` or
   `weekly_pct` left the host.
2. At least one frame sent and at least one `[usage] session ` line back from
   the board.
3. Afterwards -- not alongside, so it is not competing for the serial port --
   `overwatch status --wire` prints one line that parses as a JSON object. That is
   the command a support conversation starts with, and on the Windows desk its
   message carries a path through a non-ASCII profile name, which is the
   decode error that once left a whole machine with no figure on its board.

It does not assert any particular number. The percentages come from a live
account, so no count of stale lines and no sleep window can be asked of it
either.

## The install and update pass

Two more scenarios run when bundles are named, and neither touches the board.
They prove the part of the product a customer meets before the panel ever
lights up, and the part no amount of running from a source checkout exercises.

- **`fresh_install`** -- unpack the release archive with the machine's own tar
  or unzip, check the unpacked program reports the expected version, run
  `overwatch install` into a sandbox home, and check the copy it left at
  `~/.overwatch/bin` runs and reports the same version. The third question is the
  reason the scenario exists: an installer that prints its way to a cheerful
  ending while leaving a program that will not start is not hypothetical here.
- **`update_path`** -- install the **previous** release, then have the
  **installed** copy run `overwatch update` against a local feed, and check the
  installed program afterwards reports the candidate version. Running the
  update from the installed copy is the whole point: `update.apply` renames the
  directory the running executable is inside of, and run from an unpacked
  bundle that rename is of a directory nothing is running from -- which cannot
  fail the way Windows fails.

Both run in a sandbox with `HOME` **and** `USERPROFILE` redirected, with every
inherited `OVERWATCH_*` variable swept out of the environment, and with
`OVERWATCH_SKIP_SERVICE` set in the child so that nothing registers a login agent
on somebody's desk.

### Where the bundles come from

**A fabricated manifest cannot drive the update.** `fetch_signed_manifest`
verifies the manifest's signature against the public key compiled into the
shipped binaries (`pc/update.py:196-198`) and returns `None` when it does not
verify. Handed a hand-written `manifest.json`, `overwatch update` therefore prints
"Could not read the release feed, or it is not properly signed. Nothing was
changed." and exits 1 -- which the scenario reports as it stands, so a red run
says what was wrong with the feed rather than leaving somebody to guess. The
feed has to come from a genuinely signed release.

`tools/release.sh` produces one without publishing anything:

```bash
OVERWATCH_RELEASE_DRAFT=1 tools/release.sh
```

That builds and signs everything, attaches it to a **draft** release, and
stops. Then, on each desk, fetch that platform's files into the workdir:

```bash
cd ~/overwatch-fleet
gh release download v1.2.6 --repo KfirLevy258/Blink -D feed \
    -p manifest.json -p manifest.json.sig -p overwatch-macos-arm64.tar.gz
gh release download v1.2.5 --repo KfirLevy258/Blink -D bundles/previous \
    -p overwatch-macos-arm64.tar.gz
```

The feed directory has to hold all three of `manifest.json`,
`manifest.json.sig` and this platform's archive; the agent checks that before
it runs anything, because the far more common mistake is a directory with the
archive but no `.sig`, where `overwatch update` quietly refuses the feed and the
run reads as a broken update path.

### Running them

| Flag | Means |
|---|---|
| `--bundle` | The candidate release's archive for that desk's platform. |
| `--prev-bundle` | The release before it. Refused if it already reports the expected version, because `overwatch update` answers "Already up to date." with exit 0 and the scenario would pass without updating anything. |
| `--ota-dir` | The feed directory. Required with `--prev-bundle`. |
| `--expect-version` | The version both scenarios must end at. Required with either bundle flag -- the version is the entire claim. |

These three paths are forwarded **verbatim and interpreted on the target
desk**, and release archives are per-platform: `overwatch-macos-arm64.tar.gz`,
`overwatch-linux-x86_64.tar.gz`, `overwatch-windows-x86_64.zip`. One `--bundle` string
therefore cannot name the right file on all three machines. A *directory* name
can be shared (relative paths resolve against each desk's workdir, so
`--ota-dir feed` works everywhere), but an archive name cannot, so the
customer-path scenarios are run one desk at a time:

```bash
python3 tools/fleet/run.py --only galit-win10 --state .fleet/galit-bundles.json \
    --bundle bundles/candidate/overwatch-windows-x86_64.zip \
    --prev-bundle bundles/previous/overwatch-windows-x86_64.zip \
    --ota-dir feed --expect-version 1.2.6
```

Two consequences worth being plain about. A `--only` run is refused by the
release gate, so these runs prove the customer path but do not license a
release by themselves -- read their table and keep them. And `--state` is not
optional decoration: without it this run would delete the full fleet run's
verdict on its way past. Do the per-desk bundle runs first, or write them
somewhere else, and finish with the full run the gate will read.

## The release gate

Before it builds anything, `tools/release.sh` runs:

```bash
python3 -m pc.fleet_gate .fleet/last_run.json "$(git rev-parse HEAD)" \
    tools/fleet/fleet.toml
```

You can run exactly that by hand from the checkout root. It exits 0 and prints
one line when the commit may be released, or exits 1 with the reason on stderr;
with no arguments it prints its usage and exits 2.

It insists on all six of:

1. The run's own verdict is `ok: true`, with no top-level problems.
2. It names **this** commit. The desks proved code, and a run for another
   commit proved other code.
3. It finished within the last **twelve hours**. Long enough to prove a commit
   in the morning and release it after lunch; short enough that a run from
   before yesterday's rebase cannot vouch for today's desks, which drift on
   their own -- an unplugged board, a Windows update, a daemon left stopped.
4. It was not narrowed with `--only`.
5. It was not narrowed with `--scenarios`.
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

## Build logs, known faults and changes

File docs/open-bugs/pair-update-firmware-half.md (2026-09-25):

# A pair update that installed its app half and dropped the firmware half

**Status:** the fault is fixed and verified on hardware. What TRIPPED it on the
customer's machine is still unknown -- see "Still open" at the bottom.

Reported 2026-09-10 by a fleet tester upgrading **1.2.5 -> 1.3.2**.

## What the customer saw

The board sat on **1/2** and never moved. That is not a progress bar: it is the
tethered connecting screen's stage counter (`usage_view.c:2700`, printing
`stage + 1`), and its two stages are

    usb_boot_steps[] = { "Link the PC daemon", "Fetch first usage" }

so 1/2 is stage 0, and stage 0 only advances when `proto_host_seen()` is true.
It means "no daemon has spoken to me", not "the update is halfway".

`overwatch status` on that machine showed the shape of it exactly:

    App         1.3.2
    Board       ... firmware 1.2.5

The app half of the pair update landed and the firmware half did not. It came
back only after a hand-run `overwatch install`, which is the only command that both
rewrites the shims and re-registers the service (`cli.py:1933` is the sole
caller of `install_hooks.install`, and `cmd_install` ends with
`_install_service()`); the update path does neither.

## What the log showed, and where it stopped

    [bridge] <- {'t': 'ota_flash', 'v': 2}
    [bridge] ota: updating this app to 1.3.2 first
    [update] updated to 1.3.2
    [update] restarting into the new version      <- last line in the file

Nine earlier daemon restarts in that same file all kept logging to it. The one
after the self-update wrote nothing, and 1.3.2 had no log rotation to explain
it (`pc/logbook.py` postdates that release). Unexplained, and still is.

## Ruled out, so nobody re-derives them

- **Plist path drift.** No: `swap_in()` rotates `<bin>` -> `<bin>.old` in
  place; the target path never moves.
- **KeepAlive not firing on a clean exit.** No: `cli.py:513` is
  `<key>KeepAlive</key><true/>`, unconditional, so `os._exit(0)` is restarted.
- **The bin rotation carrying the shim away.** No: the shims live at
  `~/.overwatch/overwatch-hook.sh`, outside `bin/`.
- **A new daemon choking on old-format state slots.** No: the shim gained
  `pid` and a project name between those releases, but `_slot_pid()` uses
  `.get("pid")` with a type check, so absent fields degrade.
- **Version skew in the breadcrumb.** No: both releases use
  `os.path.join(overwatch_home, "pending_fw.json")`, 1.2.5 really does write it
  (`bridge.py`, `_on_ota_flash`), and 1.3.2's `_resume_pending()` is
  byte-identical to the current one -- `git diff v1.3.2 -- pc/bridge.py` is
  empty.

## The fault that was fixed

`_resume_pending()` spent the consent with `take()` BEFORE attempting anything,
then returned on any failure. The resume re-runs the ordinary query first, and
that query can fail for reasons that have nothing to do with the image -- a
feed that did not answer, a signature that did not verify -- at the one moment
in an update where a network is likeliest to be unsettled: seconds after the
daemon replaced itself.

The result was the customer's exact end state. The approval was gone, the board
was told `ota_none` (which `proto.c:632` maps to `OTA_UI_UP_TO_DATE` -- false,
and silent), and nothing on the panel said an update had been agreed to and
dropped.

It compounds. `upd_prompt_done` latches when the offer is shown, and until
2026-09-11 the only thing that lifted it was the board WITHDRAWING an open
prompt. A tap closes the prompt, so a tap that led nowhere left the latch set
for the rest of the boot: no second offer, no error, nothing.

Both halves are now fixed:

- `PendingFirmware` separates `read()` from `clear()` and counts attempts
  (`RESUME_TRIES = 3`). A resume that could not START keeps the consent and
  retries on the next connect; one that reaches the flash spends it first, so
  a failing write still cannot retry forever. On the last try it clears and
  sends `ota_error`, which `proto.c:635` turns into `OTA_UI_FAILED` -- a
  reason on the panel instead of silence.
- The prompt gate moved to `firmware/src/upd_prompt.h` as a pure function, so
  the FAILED-with-no-box-open case that a tap creates is covered by
  `tests/upd_prompt/host_test.c` rather than by a finger.

## How it was verified

Rebuilt on the bench: a real 1.2.5 daemon installed under a sandbox `HOME`
(safe because `self_bin = installed_bin()`, so the whole self-update happens
inside that directory), a signed local feed, and a launchd-equivalent
supervisor. The transient was induced by hiding `manifest.json` the instant the
tap landed.

    [bridge] <- {'t': 'ota_flash', 'v': 2}                          the tap
    [bridge] ota: updating this app to 1.3.3 first
    [update] restarting into the new version
    [bridge] ota: no manifest yet; 1.3.3 stays approved (attempt 1 of 3)
    [bridge] ota: resuming the approved install of 1.3.3
    [bridge] ota: flashed 1.3.3
    [ota] update landed: wanted 1.3.3, running 1.3.3 (from 1.3.2)   the BOARD

The breadcrumb the 1.2.5 daemon left, unedited, was `{"version": "1.3.3"}` --
no counter, which is why `read()` treats a missing one as zero rather than as
grounds to discard consent.

Two false starts worth keeping, because both cost an hour:

- The first rig published firmware 1.3.3 against daemon 1.3.2. `bridge.py:336`
  correctly refuses to offer firmware an app cannot drive, so the resume bailed
  for a reason no real release can produce. One release number, both halves.
- The second hid `manifest.json.sig`, which does nothing: the firmware path
  reads the UNSIGNED manifest on purpose, since MCUboot refuses an unsigned
  image whatever a manifest claims. Hide `manifest.json` itself.

## Still open

**What tripped it on the customer's machine.** The fix makes the symptom
unreachable and any similar failure visible and retryable, but the trigger is
not identified. Two things from that machine would settle it:

- `ls -la ~/.overwatch/` -- whether `pending_fw.json` is still there. Present means
  the resume never ran; absent means it ran and failed after spending consent.
- The `bridge.log` generation holding the lines AFTER
  `restarting into the new version`.

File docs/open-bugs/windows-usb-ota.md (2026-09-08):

# OPEN: a USB firmware update that never reaches the ROM loader

One customer on Windows, app 1.3.2, board on 1.2.5. They tap Install and it
fails, every time:

```
[bridge] ota: closing port to flash 1.3.2
[bridge] ota: FAILED: Could not check the chip; not flashing
```

Unresolved as of 2026-09-08. This file records what has been measured, so the
next person does not re-derive it.

## It is not the eFuse probe

That sentence comes from `flash_encrypted_chip()` returning None, which is why
this looked like a probe bug for a day. It is not one. `write_flash` goes
through the same `esptool` `connect()`, so removing, retrying or skipping the
probe only moves the failure one line down with different wording. The probe
is simply the first thing in the update that needs the ROM download loader.

## What the customer's log proves

- **The port opened.** From the log's own epoch anchors: `ota_flash` arrives,
  `flash_image` sleeps its deliberate 4 s and closes the port, and the
  reconnect's `time` message lands 28 s later. Minus the 1.5 s reconnect probe
  (`PROBE_S`), the eFuse probe ran for about **26 s** -- esptool's seven
  connect attempts spent in full.
- **The reset line works.** After each failure the board sends
  `{"t":"hello",...,"reset":"0x8"}` and replays the logo. `0x8` is Zephyr's
  `RESET_POR`, which `hwinfo_esp32.c` maps from `ESP_RST_POWERON` -- what
  pulling EN low produces. A firmware `sys_reboot()` would report `0x2`, and
  every deliberate reboot in `main.c` calls `ui_boot_mark_intentional_reboot()`
  first, which would have skipped the splash. It did not.

So DTR/RTS reach the board and reset it, and the chip comes back up running
the **application** instead of the ROM download loader.

## Why that is possible at all

This board's auto-reset circuit is cross-coupled (see the comment in
`claude_usage_bridge.py`, "A PLAIN open"): EN is low only while RTS is
asserted **and** DTR is not; IO0 is low only while DTR is asserted **and** RTS
is not. The two can never be low at the same time. Entering download mode
means crossing from (DTR=0,RTS=1) to (DTR=1,RTS=0), and both intermediate
states -- (1,1) and (0,0) -- release EN with IO0 still high.

esptool's `ClassicReset` sets the lines one at a time:

```python
_setDTR(True)    # releases EN here, IO0 still high
_setRTS(False)   # IO0 low -- one USB control transfer later
```

It works only because EN's RC rise gives the chip a few milliseconds before it
samples the strapping pins. `UnixTightReset` has no such race: it sets both
lines in a single `TIOCMSET` ioctl. And `_construct_reset_strategy_sequence`
in `esptool/loader.py` tries the atomic one **first on macOS and Linux, and
never on Windows** -- Windows only ever gets `ClassicReset`.

## What has been measured, and passes

Run 2026-09-08 on a Windows desk (installed frozen binary, its own board) and
on a Mac with the sequential sequence forced via `ESPTOOL_CFGFILE`:

| case | result |
|---|---|
| Mac, `ClassicReset` forced | 3/3 pass, ~1 s |
| Windows, cold probe | 3/3 pass, ~1 s |
| Windows, faithful handover (open port, `ota_begin`, sleep 4, close, probe on the next line) | **13/13 pass, ~1 s, first attempt** |
| Windows, port deliberately held | **0.2 s**, `PermissionError(13, 'Access is denied.')` |

Two conclusions follow, and both are measurements rather than inferences:

- **Port contention is not the cause.** A held port fails in 0.2 s with an
  explicit message; the customer burns 26 s.
- **The handover is not the trigger.** Reproduced faithfully thirteen times,
  passing on the first connect attempt every time.

The gap is not a timing margin. One second against a full seven-attempt
exhaustion is qualitative; a slightly slower machine does not do that.

## What is left

DTR and RTS are generated by the CH340 **on the board** -- USB carries
neither -- so a bad cable cannot affect the reset circuit, only data. The
customer's log proves RTS works. That isolates the fault to the **DTR -> IO0
path**: either their CH340 driver does not drive DTR the way a working one
does, or that half of the circuit is broken on their unit.

Their board has entered the ROM loader before: `docs/plans/STATE.md` records it
burned from a Mac on 2026-09-04, twice, including after a full `erase_flash`.
`tools/burn.sh` refuses fused chips, so it is not encrypted either.

**What would close it:** the probe's own error text from that machine. "Wrong
boot mode detected" confirms the chip resets and boots the app. "No serial
data received" means this whole chain is wrong. As of the commit that adds it,
the daemon logs that line instead of discarding it.

Failing that, holding the board's BOOT button while the update starts pulls
IO0 low mechanically -- both the test and, if the theory holds, the workaround.

## If it turns out to be general

The robust fix needs firmware: the ESP32 has a `FORCE_DOWNLOAD_BOOT` bit in
`RTC_CNTL_OPTION1_REG`. Setting it and rebooting lands the chip in the ROM
loader with no DTR/RTS involved, after which esptool runs `--before no_reset`.
That removes the race on every platform -- but it cannot rescue a unit already
stuck on firmware that does not have it, which is exactly this customer's
situation. A BOOT-button fallback in the app is what reaches those.

No custom reset sequence helps: both intermediate states release EN with IO0
high, and `CustomReset`'s atomic `U` command is Unix-only.

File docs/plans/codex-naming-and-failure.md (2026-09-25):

# Codex Naming and Failure Implementation Plan

> **For agentic workers:** REQUIRED SUB-SKILL: Use superpowers:subagent-driven-development (recommended) or superpowers:executing-plans to implement this plan task-by-task. Steps use checkbox (`- [ ]`) syntax for tracking.

**Goal:** Give a Codex session the two things a Claude session already has on the panel — a project name under the status line, and a red `failed` state when a turn dies — using only the rollout files Codex already writes.

**Architecture:** `pc/providers/codex_cli.py` reads the last 256 KB of each recent rollout. The project name is on line 1 of the file and the biggest rollout on this machine is 51 MB, so the name gets its own small read of the *front* of the file, cached per path because `session_meta` is written once and never rewritten. Failure comes from the same tail the state machine already scans: a `task_complete` that carries an `error` object is a turn that died, and `UsageLimitExceeded` is inside it. Before either can reach the board, `protocol.encode` is fixed to stop escaping non-ASCII — a real filesystem path can be non-ASCII, and today the firmware would draw the escape sequence.

**Tech Stack:** Python 3.10+, pytest, POSIX sh (the contract script). No new dependencies.

**Spec:** `/private/tmp/claude-502/-Users-KfirLevy-Projects-LiveClaudeUi/aeb3001d-3255-41ed-b053-ecf8e0cdec4c/scratchpad/codex-research.md` — the research that establishes what the rollout file can and cannot answer. Sections Q1 (naming) and Q3 (failure) are what this plan implements. Q2 (`waiting`) is explicitly out of scope and belongs to the Codex-hooks plan that follows this one.

## Global Constraints

- **No wire change.** No new message type, no new field on `usage`, no new value in `base.VALID_STATES`. The `usage` message measures **511** of `protocol.MAX_LINE_BYTES = 512` fully loaded, and `firmware/src/proto.c` drops an over-long line **whole** — a silent panel freeze. That 511 was re-measured in Task 0 through `test_the_widest_line_the_daemon_can_build_still_fits`, the only measurement that counts because it is the one built through `frame_to_usage`; the 506 this plan was written against predates the widest case that guard now covers, so the real headroom is **one byte**, not six. The `session` message is the one that carries the label, and it measures **66 bytes** fully loaded (`{"t":"session","v":2,"n":9999,"label":"<24 bytes>"}` + newline), so there is room there and nowhere else.
- **`protocol.SESSION_LABEL_MAX_BYTES = 24`**, truncated on a UTF-8 boundary by `protocol.session()`. That truncation is already correct and already tested (`tests/pc/test_protocol.py::test_session_label_survives_multibyte_truncation`). Do not re-implement it in the provider.
- **`turn_aborted` stays `idle`.** All four `TurnAbortReason` values (`interrupted`, `replaced`, `review_ended`, `budget_limited`) are things the person did. The owner has frozen this mapping; do not touch it.
- **`codex exec` batch runs count as sessions and get named.** No originator filter. Decided by the owner.
- **Python 3.10+**, matching the existing style in `pc/providers/`.
- **Comments explain WHY, in prose, at the density of the surrounding file.** `codex_cli.py` and `claude_state.py` both carry long explanatory blocks above the constants they justify. Match that; a bare constant with no reason is a review failure here.
- **Parsers must not raise.** `base.ProviderParser`: "A provider whose source has changed shape upstream is expected to return None and let the bus fall back to another source." Every new code path degrades to "no name" or "idle", never to an exception.
- **`pytest tests -q` passes at every commit.** Baseline is **593** with `ecdsa` installed; **561** with `--ignore=tests/pc/test_update.py` if it is not. (Both measured in Task 0 on 2026-09-04; the 515/483 this plan was written against are from before the liveness and pid work landed on this branch, which is why Task 0 re-measures rather than trusting a written-down number.) Establish your own baseline in Task 0 and hold it plus the tests you add.
- **`sh tests/ci/check_codex_contract.sh` passes** at every commit from Task 8 onward. It needs network (it fetches from `raw.githubusercontent.com`) or `CODEX_SRC_DIR`.

## File Structure

| File | Responsibility | Change |
|---|---|---|
| `pc/protocol.py` | the wire encoder and every message shape | `encode()` stops escaping non-ASCII |
| `pc/providers/codex_cli.py` | the Codex rollout reader | head-read, name sanitising, per-path name cache, `label` on the state frame, `failed` from `task_complete.error` |
| `pc/ingest.py` | the bus; picks the label for the wire | **no change** — `_pair_from` already implements the precedence rule; Task 7 only pins it |
| `pc/normalizer.py` | field-by-field merge | **no change** — `label=state_src.label` already carries it |
| `firmware/` | the panel | **no change** — `fmt_hint()` already transliterates raw UTF-8 through `fmt_ascii()`, pinned by `tests/fmt/host_test.c` ("caf\xc3\xa9" → "Working - caf?") |
| `tests/pc/test_protocol.py` | wire-shape tests | the non-ASCII encoding tests |
| `tests/pc/test_codex_cli.py` | the reader's tests | head-read, naming, caching, failure |
| `tests/pc/test_ingest.py` | the bus's tests | the two-providers-both-named precedence tests |
| `tests/ci/check_codex_contract.sh` | watches upstream's field names | the new fields this reader now depends on |

Tasks are strictly ordered. Task 1 must land before Task 5, because Task 5 is what first lets a non-ASCII string reach the label on a real desk.

---

## The three judgement calls, and why

**1. The head-read is cached, per path, pruned to the current file set on every poll.**
Not for CPU: the daemon polls roughly once a minute (`pc/bridge.py:81`, "the first usage message waits for the 60 s poll") and six 19 KB `json.loads` calls per minute is under a millisecond. It is cached because the value is *immutable by construction* — `session_meta` is line 1 of an append-only file whose name carries a UUID, so a path is never reused and the answer for a path never changes — and because the **size** of that line belongs to Codex, not to us: `session_meta` embeds `base_instructions`, and the four real rollouts on this machine have first lines of **18–19 KB**, not the "few KB" a line of JSON sounds like. Re-deriving a fixed value from a blob upstream is free to grow is waste that grows with it. Pruning to `recent_rollouts()` bounds the dict at `RECENT_FILES` = 6 entries, so the cache cannot outlive the files it describes.

**2. Claude versus Codex: there is no precedence, and that is the rule.**
`pc/ingest._pair_from` already resolves this and resolves it correctly, so this plan changes no code for it and adds tests instead. The rule: the label survives only when exactly one frame is in the state the panel is actually showing (`worst_of(primary, secondary)`) *and* the summed count for that state is 1. Two named sessions in the same state produce no name and the count carries the meaning. Picking a winner — "Claude first", or "the fresher frame" — would put one project's name over a line that is equally true of another project, which is a wrong sentence rather than a vague one. That is the same refusal `claude_state.poll` already applies within one provider; Codex getting a name simply makes the cross-provider case reachable for the first time, which is why it needs a test and not a policy.

**3. `UsageLimitExceeded` gets no distinct treatment. Every turn-failing error is `failed`.**
Three reasons. (a) There is nowhere to put it: `base.VALID_STATES` is fixed and adding a state is a wire change the Global Constraints forbid. (b) The panel already says it, from the other half of the same file: `usage_view.c:2277` draws "Session used up" off the *percentage* dial, and the `rate_limits` that fills that dial is read by this same provider from this same rollout. A rate-limited Codex turn shows a full ring and "Session failed" together; the two lines already say what happened. (c) Branching panel copy on `codex_error_info` string values that have **never been observed in a real file** is exactly the confident-wrongness this codebase refuses elsewhere. What the reader *does* mirror is upstream's own `CodexErrorInfo::affects_turn_status` predicate, which is a two-name exclusion, not an enumeration of the failures — see Task 6.

---

### Task 0: Establish the baseline

**Files:** none — this task writes nothing.

**Interfaces:**
- Produces: the number every later task's "Expected: PASS" is measured against.

- [ ] **Step 1: Run the suite and record the count**

Run: `pytest tests -q`

If it stops with `ModuleNotFoundError: No module named 'ecdsa'`, either `pip install ecdsa` or run `pytest tests -q --ignore=tests/pc/test_update.py` and use that number instead. Expected: `593 passed` (or `561 passed` with `test_update.py` ignored). Write the number down; every later task adds to it and none subtracts.

- [ ] **Step 2: Run the contract script**

Run: `sh tests/ci/check_codex_contract.sh`
Expected: `PASS [codex contract at main]`. If it fails here, before any change, stop and report — Task 8 extends this script and cannot be judged against a red baseline.

---

### Task 1: The wire stops escaping non-ASCII

**Files:**
- Modify: `pc/protocol.py:39-41` (`encode`)
- Test: `tests/pc/test_protocol.py`

**Interfaces:**
- Consumes: nothing.
- Produces: `protocol.encode(msg) -> bytes` — unchanged signature, changed bytes. Task 5 depends on this being done first.

**Why this is in this plan at all.** `encode` calls `json.dumps` with `ensure_ascii` at its default, so `"café-project"` goes on the wire as `caf\u00e9-project`. `firmware/src/msg_parse.c:47 msg_get_str()` copies the bytes between two quotes and does **no unescaping at all**, so the panel draws the literal characters `\u00e9`. Measured on this branch:

```
protocol.encode(protocol.session("café-project-name-abcdef", 9999))
b'{"t":"session","v":2,"n":9999,"label":"caf\\u00e9-project-name-abcde"}\n'
```

— 70 bytes for a label that is 24 bytes of UTF-8, and `char lbl[28]` in `proto.c:632` then truncates the escape sequence too.

The alternative was to refuse non-ASCII at the Codex boundary and leave the bug. That is rejected: the firmware **already** ships a UTF-8 decoder for exactly this (`fmt_ascii` in `firmware/src/fmt.c:90`, with `tests/fmt/host_test.c` pinning `"caf\xc3\xa9"` → `"Working - caf?"`), and the daemon's escaping is the only reason it is unreachable. Refusing at the boundary would leave a one-line live defect armed for the next source that carries a non-ASCII string. Fixing it here is also strictly safe on the byte budget: UTF-8 is never longer than `\uXXXX`, so every line this change touches gets **shorter or stays the same** and no message can newly breach `MAX_LINE_BYTES`.

- [ ] **Step 1: Write the failing test**

Add to `tests/pc/test_protocol.py`, inside the same `unittest.TestCase` class that holds `test_session_caps_the_label` (search for that method and put these beside it):

```python
    def test_encode_puts_utf8_on_the_wire_not_escapes(self):
        """The firmware does no unescaping, so an escape is drawn literally.

        msg_parse.c copies the bytes between two quotes and hands them to
        fmt_ascii(), which decodes UTF-8 and transliterates what it cannot
        draw. json.dumps' default ensure_ascii=True defeated that entirely:
        "café" arrived as the six characters \\u00e9 and the panel drew them.
        """
        raw = protocol.encode(protocol.session("café", 1))
        self.assertIn("café".encode("utf-8"), raw)
        self.assertNotIn(b"\\u00e9", raw)

    def test_encode_of_non_ascii_is_never_longer_than_the_escaped_form(self):
        """The byte budget can only improve. proto.c drops an over-long line
        whole, so a change to the encoder has to be shown not to lengthen
        anything before it can be believed."""
        import json as _json
        msg = protocol.session("café-project-name-abcdef", 9999)
        escaped = (_json.dumps(msg, separators=(",", ":"),
                               ensure_ascii=True) + "\n").encode("utf-8")
        self.assertLessEqual(len(protocol.encode(msg)), len(escaped))
        self.assertLessEqual(len(protocol.encode(msg)),
                             protocol.MAX_LINE_BYTES)

    def test_a_non_ascii_label_still_fits_the_line_limit(self):
        """The worst case for the label field: 24 bytes of four-byte
        codepoints, which ensure_ascii would have turned into 12 escapes."""
        msg = protocol.session("𝔅" * 12, 9999)
        raw, reason = protocol.encode_checked(msg)
        self.assertIsNone(reason)
        self.assertLessEqual(len(raw), protocol.MAX_LINE_BYTES)
```

- [ ] **Step 2: Run the tests to verify they fail**

Run: `pytest tests/pc/test_protocol.py -q -k "utf8_on_the_wire or never_longer or non_ascii_label"`
Expected: `test_encode_puts_utf8_on_the_wire_not_escapes` FAILS on the `assertIn` (the raw UTF-8 bytes are not in the line). The other two pass already — they are the guards that the fix does not cost anything, and a guard that passes before and after is doing its job.

- [ ] **Step 3: Write the implementation**

Replace `pc/protocol.py:39-41` with:

```python
def encode(msg: dict) -> bytes:
    """Serialize a message dict to a single NDJSON line (bytes).

    ensure_ascii=False, and that is a firmware decision rather than a taste
    one. json.dumps escapes non-ASCII by default, msg_parse.c copies the
    bytes between two quotes and unescapes nothing, and fmt.c then draws
    whatever it was given -- so a project called "café" reached the panel as
    the literal characters \\u00e9 and was drawn that way. The firmware has
    had a UTF-8 decoder for this since fmt_ascii() was written
    (tests/fmt/host_test.c pins "caf\\xc3\\xa9" -> "caf?"); the escaping here
    was the only thing keeping it out of reach.

    It cannot cost line budget either, which matters because proto.c drops an
    over-long line whole: a UTF-8 sequence is at most four bytes and the
    escape it replaces is at least six, so every line this touches gets
    shorter or stays the same.
    """
    return (json.dumps(msg, separators=(",", ":"),
                       ensure_ascii=False) + "\n").encode("utf-8")
```

- [ ] **Step 4: Run the tests to verify they pass**

Run: `pytest tests/pc/test_protocol.py -q`
Expected: PASS, no failures.

- [ ] **Step 5: Run the whole suite**

Run: `pytest tests -q`
Expected: baseline + 3 passed.

- [ ] **Step 6: Commit**

```bash
git add pc/protocol.py tests/pc/test_protocol.py
git commit -m "fix: a non-ASCII project name reached the panel as its own escape sequence"
```

---

### Task 2: Read the first line of a rollout

**Files:**
- Modify: `pc/providers/codex_cli.py` (add after `_tail_lines`, around line 132)
- Test: `tests/pc/test_codex_cli.py`

**Interfaces:**
- Consumes: nothing.
- Produces: `codex_cli.HEAD_BYTES` (int) and `codex_cli._head_line(path: str) -> str` — Task 4 calls it.

- [ ] **Step 1: Write the failing test**

Add to `tests/pc/test_codex_cli.py`, after `test_only_the_tail_of_a_huge_file_is_read` (search for that name):

```python
# --- the head of the file: where the project name lives ----------------------

def test_the_first_line_is_read_whatever_follows_it(tmp_path):
    """The name is on line 1 and the tail read cannot reach it: the biggest
    rollout on the machine this was written against is 51 MB. So the head
    gets its own read, and it must not care how much comes after."""
    path = str(tmp_path / "rollout-a.jsonl")
    with open(path, "w", encoding="utf-8") as f:
        f.write('{"type":"session_meta","payload":{"cwd":"/a/b"}}\n')
        f.write("x" * (codex_cli.HEAD_BYTES * 3) + "\n")
    assert codex_cli._head_line(path) == \
        '{"type":"session_meta","payload":{"cwd":"/a/b"}}'

def test_a_first_line_longer_than_the_head_bound_is_refused_not_halved(tmp_path):
    """A JSON object cut in half parses as nothing anyway, and returning the
    fragment would only move the failure into json.loads. The cost of a first
    line that does not fit is the name, not the read."""
    path = str(tmp_path / "rollout-b.jsonl")
    with open(path, "w", encoding="utf-8") as f:
        f.write('{"type":"session_meta","payload":{"pad":"'
                + "p" * (codex_cli.HEAD_BYTES + 10) + '"}}\n')
    assert codex_cli._head_line(path) == ""

def test_the_head_bound_clears_a_real_session_meta_line():
    """18-19 KB is what the four real rollouts on this machine measure, and
    that length is upstream's to change -- base_instructions is embedded in
    the record. The bound has to have room over the observation, not equal
    it."""
    assert codex_cli.HEAD_BYTES >= 4 * 19 * 1024

def test_a_missing_file_is_silence_not_an_error(tmp_path):
    assert codex_cli._head_line(str(tmp_path / "nope.jsonl")) == ""

def test_a_file_with_no_newline_at_all_is_refused(tmp_path):
    """A rollout being written right now can have a partial first line. It
    is not a name yet, and it will be on the next poll."""
    path = str(tmp_path / "rollout-c.jsonl")
    with open(path, "w", encoding="utf-8") as f:
        f.write('{"type":"session_meta","payload":{"cwd":"/a')
    assert codex_cli._head_line(path) == ""
```

- [ ] **Step 2: Run the tests to verify they fail**

Run: `pytest tests/pc/test_codex_cli.py -q -k "first_line or head_bound or no_newline or missing_file"`
Expected: FAIL with `AttributeError: module 'pc.providers.codex_cli' has no attribute 'HEAD_BYTES'`.

- [ ] **Step 3: Write the implementation**

In `pc/providers/codex_cli.py`, insert immediately after `_tail_lines` (which ends at line 131 with `return text.splitlines()`):

```python
# The other end of the same file. `session_meta` -- the record that carries
# the project's cwd, and so the only name a Codex session can ever have -- is
# line 1, and the tail read above will never see it: the biggest rollout on
# the machine this was written against is 51 MB, so TAIL_BYTES would have to
# grow to the size of the file to reach the front of it. The name therefore
# gets its own small read, of the head, and the two never meet.
#
# 64 KB rather than the "a few KB" a line of JSON sounds like. `session_meta`
# embeds `base_instructions`, and the four real rollouts here have first
# lines of 18-19 KB. That number is Codex's to change, so the bound is
# deliberately several times the observation -- and a first line that still
# does not fit costs the name, not the read.
HEAD_BYTES = 64 * 1024

def _head_line(path: str) -> str:
    """The first COMPLETE line of a file, or "".

    Complete is the whole point. A line with no newline inside HEAD_BYTES is
    refused rather than returned in part: a JSON object cut in half decodes
    as nothing, and handing the fragment back would only move the failure
    into json.loads. A rollout being written at this instant is the ordinary
    case for that, and it will have its newline by the next poll.
    """
    try:
        with open(path, "rb") as f:
            blob = f.read(HEAD_BYTES)
    except OSError:
        return ""
    nl = blob.find(b"\n")
    if nl < 0:
        return ""
    return blob[:nl].decode("utf-8", "replace")
```

- [ ] **Step 4: Run the tests to verify they pass**

Run: `pytest tests/pc/test_codex_cli.py -q`
Expected: PASS, no failures.

- [ ] **Step 5: Commit**

```bash
git add pc/providers/codex_cli.py tests/pc/test_codex_cli.py
git commit -m "feat: read the head of a rollout, where the session's cwd is"
```

---

### Task 3: A cwd becomes a project name, or nothing

**Files:**
- Modify: `pc/providers/codex_cli.py` (add after `_head_line`)
- Test: `tests/pc/test_codex_cli.py`

**Interfaces:**
- Consumes: nothing from earlier tasks (these two functions are pure).
- Produces:
  - `codex_cli.session_meta_cwd(head_line: str) -> str | None`
  - `codex_cli._project_name(cwd) -> str`

  Task 4 composes them as `_project_name(session_meta_cwd(_head_line(path)))`.

- [ ] **Step 1: Write the failing test**

Add to `tests/pc/test_codex_cli.py`, after the head-read tests from Task 2:

```python
def test_the_cwd_comes_out_of_a_session_meta_line():
    line = json.dumps({"type": "session_meta", "timestamp": "2026-08-27",
                       "payload": {"cwd": "/Users/K/Projects/LiveClaudeUi",
                                   "originator": "codex-tui"}})
    assert codex_cli.session_meta_cwd(line) == "/Users/K/Projects/LiveClaudeUi"

def test_a_line_that_is_not_session_meta_yields_no_cwd():
    """None rather than "" so the caller can tell a head it could not read
    from a directory it read and then refused."""
    assert codex_cli.session_meta_cwd(
        json.dumps({"type": "event_msg", "payload": {"cwd": "/a/b"}})) is None
    assert codex_cli.session_meta_cwd("") is None
    assert codex_cli.session_meta_cwd("session_meta but not json") is None
    assert codex_cli.session_meta_cwd(json.dumps(["session_meta"])) is None
    assert codex_cli.session_meta_cwd(
        json.dumps({"type": "session_meta", "payload": "session_meta"})) is None
    assert codex_cli.session_meta_cwd(
        json.dumps({"type": "session_meta", "payload": {}})) is None
    assert codex_cli.session_meta_cwd(
        json.dumps({"type": "session_meta", "payload": {"cwd": 7}})) is None

def test_the_name_is_the_last_path_component():
    assert codex_cli._project_name("/Users/K/Projects/LiveClaudeUi") == \
        "LiveClaudeUi"
    assert codex_cli._project_name("/private/tmp") == "tmp"

def test_a_trailing_separator_is_not_a_component():
    assert codex_cli._project_name("/Users/K/Overwatch/") == "Overwatch"
    assert codex_cli._project_name("/Users/K/Overwatch///") == "Overwatch"

def test_a_windows_path_splits_on_the_windows_separator():
    """Both separators, not os.sep: a home directory can be synced between
    machines, and Codex on Windows writes C:\\Users\\...."""
    assert codex_cli._project_name("C:\\Users\\Kfir\\Projects\\Overwatch") == "Overwatch"
    assert codex_cli._project_name("C:\\Users\\Kfir\\Projects\\Overwatch\\") == "Overwatch"

def test_a_directory_entry_is_not_a_name():
    for cwd in ("/", "", ".", "..", "/a/b/.", "/a/b/.."):
        assert codex_cli._project_name(cwd) == "", cwd

def test_a_control_character_never_reaches_the_wire():
    """This string is JSON-encoded into a line the firmware scans for quotes.
    A newline in a directory name is legal on every platform this runs on."""
    assert codex_cli._project_name("/a/b/pro\nject") == "project"
    assert codex_cli._project_name("/a/b/pro\x7fject") == "project"
    assert codex_cli._project_name("/a/b/\n\n") == ""

def test_a_name_with_no_drawable_ascii_is_refused():
    """firmware/src/fmt.c draws a label through fmt_ascii(), which replaces
    every codepoint it has no ASCII spelling for with "?" -- pinned by
    tests/fmt/host_test.c. A wholly non-Latin name therefore arrives as a row
    of question marks, which is worse than the count the panel falls back to.
    A name with a Latin stem keeps it and loses the rest.
    """
    assert codex_cli._project_name("/Users/K/פרויקט") == ""
    assert codex_cli._project_name("/Users/K/项目") == ""
    assert codex_cli._project_name("/Users/K/café") == "café"
    assert codex_cli._project_name("/Users/K/proj-项目") == "proj-项目"

def test_a_name_with_spaces_is_kept():
    """Unlike the Claude hook shim, which is one sed and refuses them. There
    is no filename being built here and no shell quoting to get wrong, so the
    reason that rule exists there does not exist here."""
    assert codex_cli._project_name("/Users/K/My Project") == "My Project"

def test_a_cwd_that_is_not_a_string_is_refused_not_raised():
    for cwd in (None, 7, [], {}, True):
        assert codex_cli._project_name(cwd) == ""

def test_the_name_is_not_capped_here():
    """protocol.session is the one place that knows the byte bound and the
    one place that truncates on a UTF-8 boundary. A second cap here would be
    a second thing to keep in step with the firmware."""
    long = "n" * 200
    assert codex_cli._project_name("/a/" + long) == long
```

- [ ] **Step 2: Run the tests to verify they fail**

Run: `pytest tests/pc/test_codex_cli.py -q -k "cwd or project_name or last_path or trailing_separator or windows_path or directory_entry or control_character or drawable_ascii or with_spaces or capped_here"`
Expected: FAIL with `AttributeError: module 'pc.providers.codex_cli' has no attribute 'session_meta_cwd'`.

- [ ] **Step 3: Write the implementation**

In `pc/providers/codex_cli.py`, insert immediately after `_head_line`:

```python
def session_meta_cwd(head_line: str):
    """The `cwd` out of a rollout's first line, or None.

    None rather than "": the caller has two different failures to tell apart
    -- a head it could not read, and a directory it read and then refused --
    and only one of them is worth ever looking at again.
    """
    if "session_meta" not in head_line:
        return None         # cheap reject before parsing 19 KB of JSON
    try:
        line = json.loads(head_line)
    except ValueError:
        return None
    if not isinstance(line, dict) or line.get("type") != "session_meta":
        return None
    payload = line.get("payload")
    if not isinstance(payload, dict):
        return None
    cwd = payload.get("cwd")
    return cwd if isinstance(cwd, str) else None

# Both, not os.sep. This file may be read on one platform and written on
# another -- a synced home directory is ordinary -- and Codex on Windows
# writes C:\Users\....
_NAME_SEPARATORS = "/\\"

def _project_name(cwd) -> str:
    """The project name a Codex `cwd` implies, or "".

    The last path component, with three refusals. The first two are the ones
    the Claude hook shim already applies to its own cwd: `.` and `..` are
    directory entries rather than names, and control characters are stripped
    because this string is JSON-encoded into a line the firmware scans for
    quotes.

    The third is about the panel rather than about safety, and it is the one
    the shim has no need of. firmware/src/fmt.c draws a label through
    fmt_ascii(), which replaces every codepoint it has no ASCII spelling for
    with "?" -- tests/fmt/host_test.c pins "caf\xc3\xa9" arriving as "caf?".
    A wholly non-Latin name therefore reaches the desk as a row of question
    marks, which says less than the count the panel falls back to when there
    is no name at all. So a name has to carry at least one ASCII letter or
    digit to be worth sending: "café" keeps its name and loses one letter,
    "פרויקט" is refused and the count speaks instead.

    Not capped here. protocol.session is the one place that knows the byte
    bound and the one place that truncates on a UTF-8 boundary; a second cap
    would be a second thing to keep in step with the firmware.
    """
    if not isinstance(cwd, str):
        return ""
    name = cwd
    while name and name[-1] in _NAME_SEPARATORS:
        name = name[:-1]
    for sep in _NAME_SEPARATORS:
        name = name.rsplit(sep, 1)[-1]
    name = "".join(c for c in name if c >= " " and c != "\x7f")
    if name in ("", ".", ".."):
        return ""
    if not any(("a" <= c <= "z") or ("A" <= c <= "Z") or ("0" <= c <= "9")
               for c in name):
        return ""
    return name
```

- [ ] **Step 4: Run the tests to verify they pass**

Run: `pytest tests/pc/test_codex_cli.py -q`
Expected: PASS, no failures.

- [ ] **Step 5: Commit**

```bash
git add pc/providers/codex_cli.py tests/pc/test_codex_cli.py
git commit -m "feat: turn a Codex cwd into a name the panel can draw"
```

---

### Task 4: The name is read once per file

**Files:**
- Modify: `pc/providers/codex_cli.py` (`CodexCliProvider.__init__` at line 304, plus a new method)
- Test: `tests/pc/test_codex_cli.py`

**Interfaces:**
- Consumes: `_head_line` (Task 2), `session_meta_cwd` and `_project_name` (Task 3).
- Produces: `CodexCliProvider._name_for(path: str) -> str` and `CodexCliProvider._prune_names(known)` — Task 5 calls both.

- [ ] **Step 1: Write the failing test**

Add to `tests/pc/test_codex_cli.py`, after the naming tests from Task 3:

```python
def test_the_name_is_read_once_per_file(tmp_path):
    """`session_meta` is line 1 of an append-only file whose name carries a
    UUID: the path is never reused and the answer never changes. Re-deriving
    it from 19 KB of embedded system prompt on every tick is waste that grows
    with whatever upstream puts in that record next."""
    root = str(tmp_path / "sessions")
    path = write_rollout(root, lines=[meta_line("/Users/K/Overwatch"),
                                      token_count_line(rate_limits())])
    p = codex_cli.CodexCliProvider(root=root)
    reads = []
    real = codex_cli._head_line
    codex_cli._head_line = lambda q: (reads.append(q), real(q))[1]
    try:
        assert p._name_for(path) == "Overwatch"
        assert p._name_for(path) == "Overwatch"
        assert p._name_for(path) == "Overwatch"
    finally:
        codex_cli._head_line = real
    assert reads == [path], reads

def test_a_file_with_no_usable_name_is_not_re_read_either(tmp_path):
    """The negative answer is as fixed as the positive one, and a rollout
    with no session_meta is the common case for a file being written right
    now -- exactly the file this would otherwise re-read every minute."""
    root = str(tmp_path / "sessions")
    path = write_rollout(root, lines=[token_count_line(rate_limits())])
    p = codex_cli.CodexCliProvider(root=root)
    reads = []
    real = codex_cli._head_line
    codex_cli._head_line = lambda q: (reads.append(q), real(q))[1]
    try:
        assert p._name_for(path) == ""
        assert p._name_for(path) == ""
    finally:
        codex_cli._head_line = real
    assert reads == [path], reads

def test_names_are_pruned_to_the_files_still_being_read(tmp_path):
    """Bounded by RECENT_FILES rather than by how long the daemon has been
    up. A path that has fallen out of the recent set will never be read
    again, so holding its name is holding a string for nothing."""
    p = codex_cli.CodexCliProvider(root=str(tmp_path))
    p._names = {"/a": "A", "/b": "B", "/c": "C"}
    p._prune_names({"/b", "/c", "/d"})
    assert p._names == {"/b": "B", "/c": "C"}

def test_two_providers_do_not_share_a_name_cache(tmp_path):
    """A mutable default on __init__ would make the cache class-wide, which
    is a bug that only shows up on a desk running two of these."""
    a = codex_cli.CodexCliProvider(root=str(tmp_path))
    b = codex_cli.CodexCliProvider(root=str(tmp_path))
    a._names["/a"] = "A"
    assert b._names == {}
```

Add this helper beside `token_count_line` near the top of the file (after `write_rollout`):

```python
def meta_line(cwd, originator="codex-tui"):
    """Line 1 of a real rollout: the record that carries the project's cwd.

    The padding is not decoration. A real session_meta embeds
    base_instructions and measures 18-19 KB, and a fixture of 80 bytes would
    let a head bound far too small to work on a desk pass every test here.
    """
    return json.dumps({
        "timestamp": "2026-08-27T03:00:00.000Z",
        "type": "session_meta",
        "payload": {"cwd": cwd, "originator": originator,
                    "cli_version": "0.150.0",
                    "base_instructions": "i" * 18_000},
    })
```

- [ ] **Step 2: Run the tests to verify they fail**

Run: `pytest tests/pc/test_codex_cli.py -q -k "once_per_file or not_re_read or pruned or share_a_name_cache"`
Expected: FAIL with `AttributeError: 'CodexCliProvider' object has no attribute '_name_for'`.

- [ ] **Step 3: Write the implementation**

Replace `CodexCliProvider.__init__` (currently `pc/providers/codex_cli.py:304-305`) and add `_name_for`/`_prune_names` after `root()`:

```python
    def __init__(self, root=None):
        self._root = root
        # path -> project name, for the one record in a rollout that cannot
        # change. `session_meta` is line 1 of an append-only file whose name
        # carries a UUID, so a path is never reused and the answer for a path
        # is fixed for the life of the file.
        #
        # The saving is not CPU. The daemon polls about once a minute and
        # 19 KB of json.loads is under a millisecond. It is that the SIZE of
        # that line belongs to Codex: base_instructions is embedded in it,
        # and re-deriving an immutable value from a blob upstream is free to
        # grow is waste that grows with it. Pruned to the current file set on
        # every poll, so this is bounded by RECENT_FILES rather than by how
        # long the daemon has been up.
        self._names = {}
```

```python
    def _name_for(self, path):
        """The project name for one rollout, read once per file.

        The negative answer is cached too, and deliberately: a rollout with
        no readable session_meta yet is a file being written at this instant,
        which is precisely the file that would otherwise be re-read on every
        poll for as long as it stayed in the recent set.
        """
        if path not in self._names:
            self._names[path] = _project_name(
                session_meta_cwd(_head_line(path)))
        return self._names[path]

    def _prune_names(self, known):
        """Forget every cached name whose file is no longer being read."""
        self._names = {p: n for p, n in self._names.items() if p in known}
```

- [ ] **Step 4: Run the tests to verify they pass**

Run: `pytest tests/pc/test_codex_cli.py -q`
Expected: PASS, no failures.

- [ ] **Step 5: Commit**

```bash
git add pc/providers/codex_cli.py tests/pc/test_codex_cli.py
git commit -m "feat: cache a rollout's project name, which cannot change"
```

---

### Task 5: The state frame carries the name

**Files:**
- Modify: `pc/providers/codex_cli.py` (`CodexCliProvider.poll`, lines 335-379)
- Test: `tests/pc/test_codex_cli.py`

**Interfaces:**
- Consumes: `_name_for` and `_prune_names` (Task 4); `base.NormalizedUsageFrame.label` (`pc/providers/base.py:135`).
- Produces: a `label` on the `STATE_SRC_ID` frame. `pc/normalizer.merge` already carries it (`normalizer.py:192`) and `pc/ingest._pair_from` already consumes it; neither changes.

- [ ] **Step 1: Write the failing test**

Add to `tests/pc/test_codex_cli.py`, after `test_no_state_frame_when_no_rollout_has_a_turn`:

```python
# --- naming the session, when there is exactly one to name -------------------

def _state_frame(root, now=NOW):
    frames = codex_cli.CodexCliProvider(root=root).poll(now)
    held = [f for f in frames if f.src == codex_cli.STATE_SRC_ID]
    return held[0] if held else None

def test_the_one_session_in_the_winning_state_is_named(tmp_path):
    root = str(tmp_path / "sessions")
    write_rollout(root, name="rollout-a.jsonl",
                  lines=[meta_line("/Users/K/Projects/LiveClaudeUi"),
                         token_count_line(rate_limits()),
                         turn_line("task_complete", _stamp(NOW - 5))])
    st = _state_frame(root)
    assert (st.state, st.label) == ("idle", "LiveClaudeUi")

def test_two_sessions_in_the_winning_state_are_not_named(tmp_path):
    """The rule claude_state.poll applies, applied here for the same reason:
    a name picked from two says something true about one and implies it about
    the other. The count is what is true of both."""
    root = str(tmp_path / "sessions")
    write_rollout(root, name="rollout-a.jsonl",
                  lines=[meta_line("/Users/K/Overwatch"),
                         token_count_line(rate_limits()),
                         turn_line("task_complete", _stamp(NOW - 5))])
    write_rollout(root, name="rollout-b.jsonl",
                  lines=[meta_line("/Users/K/Other"),
                         turn_line("task_complete", _stamp(NOW - 9))])
    st = _state_frame(root)
    assert (st.state, st.n_idle, st.label) == ("idle", 2, "")

def test_a_session_in_a_lesser_state_does_not_lend_its_name(tmp_path):
    """Two sessions, two states. The frame's `state` is the worse of them, so
    only the session actually holding that state may be named -- the other's
    name under the other's status would be a wrong sentence."""
    root = str(tmp_path / "sessions")
    write_rollout(root, name="rollout-a.jsonl",
                  lines=[meta_line("/Users/K/Finished"),
                         token_count_line(rate_limits()),
                         turn_line("task_complete", _stamp(NOW - 5))])
    write_rollout(root, name="rollout-b.jsonl",
                  lines=[meta_line("/Users/K/Working"),
                         turn_line("task_started", _stamp(NOW - 9))])
    st = _state_frame(root)
    assert (st.state, st.label) == ("idle", "Finished")

def test_an_unnamed_session_leaves_a_named_one_alone(tmp_path):
    """A rollout whose session_meta could not be read is still a session and
    still votes on the state -- it just has nothing to add to the name. Two
    holders of the state is still two, named or not."""
    root = str(tmp_path / "sessions")
    write_rollout(root, name="rollout-a.jsonl",
                  lines=[meta_line("/Users/K/Overwatch"),
                         token_count_line(rate_limits()),
                         turn_line("task_complete", _stamp(NOW - 5))])
    write_rollout(root, name="rollout-b.jsonl",
                  lines=[turn_line("task_complete", _stamp(NOW - 9))])
    st = _state_frame(root)
    assert (st.state, st.n_idle, st.label) == ("idle", 2, "")

def test_a_rollout_with_no_turn_yet_lends_no_name(tmp_path):
    """It makes no claim on the state, so it must make none on the name --
    otherwise an opened-and-untyped-into terminal would rename the panel."""
    root = str(tmp_path / "sessions")
    write_rollout(root, name="rollout-a.jsonl",
                  lines=[meta_line("/Users/K/Overwatch"),
                         token_count_line(rate_limits()),
                         turn_line("task_started", _stamp(NOW - 5))])
    write_rollout(root, name="rollout-b.jsonl",
                  lines=[meta_line("/Users/K/JustOpened")])
    st = _state_frame(root)
    assert (st.state, st.n_run, st.label) == ("running", 1, "Overwatch")

def test_a_poll_prunes_the_names_of_files_it_no_longer_reads(tmp_path):
    root = str(tmp_path / "sessions")
    write_rollout(root, name="rollout-a.jsonl",
                  lines=[meta_line("/Users/K/Overwatch"),
                         token_count_line(rate_limits()),
                         turn_line("task_started", _stamp(NOW - 5))])
    p = codex_cli.CodexCliProvider(root=root)
    p._names["/gone/rollout-z.jsonl"] = "Ghost"
    p.poll(NOW)
    assert "/gone/rollout-z.jsonl" not in p._names
    assert list(p._names.values()) == ["Overwatch"]
```

- [ ] **Step 2: Run the tests to verify they fail**

Run: `pytest tests/pc/test_codex_cli.py -q -k "winning_state or lesser_state or unnamed_session or no_turn_yet_lends or prunes_the_names"`
Expected: FAIL — `assert ('idle', '') == ('idle', 'LiveClaudeUi')`; the frame has no label.

- [ ] **Step 3: Write the implementation**

Replace the body of `CodexCliProvider.poll` (`pc/providers/codex_cli.py:335-379`) with:

```python
    def poll(self, now_epoch):
        """The freshest reading Codex has written, as a one-frame list.

        One frame, not one per rollout file: the two percentages are
        account-wide, so several open terminals all describe the same pair of
        windows and handing the normalizer six copies of it would only make
        the freshest one win a contest it has already won here.
        """
        best = None
        counts = {}
        names = {}
        paths = recent_rollouts(self._root)
        self._prune_names(set(paths))
        for path in paths:
            try:
                mtime = os.path.getmtime(path)
            except OSError:
                continue
            lines = _tail_lines(path)
            # Every rollout is one session, so every one of them votes on
            # the execution state -- unlike the percentages, which are one
            # account-wide pair however many terminals are open.
            state = parse_rollout_state(lines, now_epoch)
            if state != base.STATE_UNKNOWN:
                counts[state] = counts.get(state, 0) + 1
                # A name is only collected from a session that made a claim.
                # A terminal opened and not typed into has a cwd and no turn,
                # and letting it lend its name would rename the panel after
                # the session that is actually doing something.
                name = self._name_for(path)
                if name:
                    names.setdefault(state, []).append(name)
            limits, observed_at = parse_rollout_tail(lines, mtime)
            if limits is None:
                continue
            frame = self.parse_cli_event(limits, now_epoch, observed_at)
            if frame is None:
                continue
            if best is None or frame.observed_at > best.observed_at:
                best = frame
        frames = [best] if best is not None else []
        if counts:
            # A separate frame with no percentages, exactly as Claude's state
            # provider does it: it can never win a recency contest for
            # numbers, and the normalizer merges its state field by field.
            state = base.worst_of(counts)
            held = names.get(state, [])
            frames.append(base.NormalizedUsageFrame(
                provider=PROVIDER_ID,
                src=STATE_SRC_ID,
                observed_at=now_epoch,
                state=state,
                # Named only when exactly ONE session holds the state the
                # frame is reporting, which is the rule claude_state.poll
                # applies and for the same reason: a count says something
                # true about all of them, and a name picked from three says
                # something true about one and implies it about the rest.
                label=(held[0] if counts.get(state, 0) == 1 and len(held) == 1
                       else ""),
                n_run=counts.get(base.STATE_RUNNING, 0),
                n_idle=counts.get(base.STATE_IDLE, 0),
                n_stuck=counts.get(base.STATE_STUCK, 0),
            ))
        return frames
```

- [ ] **Step 4: Run the tests to verify they pass**

Run: `pytest tests/pc/test_codex_cli.py -q`
Expected: PASS, no failures.

- [ ] **Step 5: Run the whole suite**

Run: `pytest tests -q`
Expected: baseline + 3 (Task 1) + 5 (Task 2) + 11 (Task 3) + 4 (Task 4) + 6 (Task 5) passed.

- [ ] **Step 6: Commit**

```bash
git add pc/providers/codex_cli.py tests/pc/test_codex_cli.py
git commit -m "feat: name the Codex session on the panel, when there is one to name"
```

---

### Task 6: A turn that died is `failed`, not `idle`

**Files:**
- Modify: `pc/providers/codex_cli.py` (the `_TURN_EVENTS` block at 258-266, `parse_rollout_state` at 269-300, and `n_stuck` in `poll`)
- Test: `tests/pc/test_codex_cli.py`

**Interfaces:**
- Consumes: `base.STATE_FAILED` (`pc/providers/base.py:37`), which `base.SEVERITY` already ranks above every other state. Nothing downstream needs teaching: `firmware/src/usage_state.c:22` already maps the wire string `"failed"` to `USAGE_ACTIVITY_FAILED`, which `usage_view.c:2214` draws as "Session failed". This is why `failed` costs no wire change — Claude has been sending it since `StopFailure` existed.
- Produces: `codex_cli._is_turn_failure(error) -> bool` and `codex_cli._NOT_A_TURN_FAILURE` — nothing later consumes them; Task 8 pins the upstream arm they mirror.

**What is being read.** `TurnCompleteEvent.error: Option<ErrorEvent>` — upstream's own comment is "Terminal error details when the turn completed unsuccessfully" — with `#[serde(skip_serializing_if = "Option::is_none")]`, so a successful turn has no `error` key at all. `ErrorEvent` serialises as `{"message": ..., "codex_error_info": ...}`; `codex_error_info` is a `CodexErrorInfo` whose unit variants (`usage_limit_exceeded`, `unauthorized`, …) serialise as bare snake_case strings and whose struct variants (`http_connection_failed`, `active_turn_not_steerable`) serialise as a single-key object. **Never observed in a real file** — every rollout on this machine is a success — so this branch is pinned to the upstream schema and to `check_codex_contract.sh`, and is written to degrade toward `idle` on any shape it does not recognise.

- [ ] **Step 1: Write the failing test**

Add to `tests/pc/test_codex_cli.py`, after the naming tests from Task 5:

```python
# --- a turn that died -------------------------------------------------------

def failed_line(stamp, info="usage_limit_exceeded", message="You have hit"):
    """A `task_complete` that carries an error, shaped as upstream writes it.

    ErrorEvent is {message, codex_error_info}; codex_error_info is a
    CodexErrorInfo, whose unit variants are bare snake_case strings.
    """
    error = {"message": message}
    if info is not None:
        error["codex_error_info"] = info
    return json.dumps({"timestamp": stamp, "type": "event_msg",
                       "payload": {"type": "task_complete",
                                   "turn_id": "t1", "error": error}})

def test_a_turn_that_died_on_a_usage_limit_is_failed():
    """The single case this product exists to warn about."""
    assert codex_cli.parse_rollout_state(
        [failed_line(_stamp(NOW - 5))], NOW) == base.STATE_FAILED

def test_every_terminal_error_is_failed_not_just_the_limit_one():
    """No branch on which error. There is nowhere on the wire to put the
    distinction -- base.VALID_STATES is fixed -- and the panel already draws
    "Session used up" off the percentage dial this same file feeds."""
    for info in ("context_window_exceeded", "unauthorized",
                 "internal_server_error", "sandbox_error", "other"):
        assert codex_cli.parse_rollout_state(
            [failed_line(_stamp(NOW - 5), info=info)], NOW) \
            == base.STATE_FAILED, info

def test_a_struct_shaped_error_is_failed():
    """CodexErrorInfo::HttpConnectionFailed carries a field, so it
    serialises as a single-key object rather than a bare string."""
    assert codex_cli.parse_rollout_state(
        [failed_line(_stamp(NOW - 5),
                     info={"http_connection_failed": {"http_status_code": 503}})],
        NOW) == base.STATE_FAILED

def test_an_error_upstream_does_not_call_a_turn_failure_is_still_idle():
    """CodexErrorInfo::affects_turn_status returns false for exactly two
    variants, both of them failures of a client operation rather than of the
    turn. Painting the panel red for a failed thread rollback would cry wolf
    with the one colour that must not."""
    assert codex_cli.parse_rollout_state(
        [failed_line(_stamp(NOW - 5), info="thread_rollback_failed")],
        NOW) == base.STATE_IDLE
    assert codex_cli.parse_rollout_state(
        [failed_line(_stamp(NOW - 5),
                     info={"active_turn_not_steerable": {"turn_kind": "review"}})],
        NOW) == base.STATE_IDLE

def test_an_error_with_no_info_is_failed():
    """ErrorEvent::affects_turn_status is is_none_or(...) -- upstream's own
    answer for a missing CodexErrorInfo is that the turn failed. An error
    object with nothing legible in it is still an error object."""
    assert codex_cli.parse_rollout_state(
        [failed_line(_stamp(NOW - 5), info=None)], NOW) == base.STATE_FAILED
    for info in (None, 7, [], ["thread_rollback_failed"],
                 {"a": 1, "b": 2}, {}):
        line = json.dumps({"timestamp": _stamp(NOW - 5), "type": "event_msg",
                           "payload": {"type": "task_complete",
                                       "error": {"message": "boom",
                                                 "codex_error_info": info}}})
        assert codex_cli.parse_rollout_state([line], NOW) \
            == base.STATE_FAILED, info

def test_an_error_of_an_unexpected_shape_degrades_to_idle_not_to_red():
    """Never observed in a real file, so the shape is upstream's to change.
    Red is the loudest thing this panel does and must not be reachable by a
    field that merely stopped being an object."""
    for bad in ("boom", 7, [], None, True):
        line = json.dumps({"timestamp": _stamp(NOW - 5), "type": "event_msg",
                           "payload": {"type": "task_complete", "error": bad}})
        assert codex_cli.parse_rollout_state([line], NOW) == base.STATE_IDLE, bad

def test_a_task_complete_without_an_error_is_still_idle():
    """The ordinary case, and every rollout ever captured on this machine."""
    assert codex_cli.parse_rollout_state(
        [turn_line("task_complete", _stamp(NOW - 5))], NOW) == base.STATE_IDLE

def test_an_aborted_turn_is_still_idle_whatever_its_reason():
    """All four TurnAbortReason values are things the person did: Esc, a new
    message typed over the turn, a review closing, a budget stopping it.
    Idle is the right colour for all four, and this mapping is frozen."""
    for reason in ("interrupted", "replaced", "review_ended", "budget_limited"):
        line = json.dumps({"timestamp": _stamp(NOW - 5), "type": "event_msg",
                           "payload": {"type": "turn_aborted",
                                       "reason": reason}})
        assert codex_cli.parse_rollout_state([line], NOW) == base.STATE_IDLE, \
            reason

def test_an_abandoned_failed_turn_claims_nothing():
    """A failure an hour ago is a session that is gone, not a red light that
    stays on until the daemon restarts."""
    gone = codex_cli.ABANDONED_AFTER_S + 1
    assert codex_cli.parse_rollout_state(
        [failed_line(_stamp(NOW - gone))], NOW) == base.STATE_UNKNOWN

def test_a_failed_session_is_the_worst_state_and_counted_with_the_stuck(tmp_path):
    """The wire has one count for "not working and not finished", and
    claude_state.poll folds failed into it for the same reason: `state`
    already carries which of the two it is."""
    root = str(tmp_path / "sessions")
    write_rollout(root, name="rollout-a.jsonl",
                  lines=[meta_line("/Users/K/Overwatch"),
                         token_count_line(rate_limits()),
                         failed_line(_stamp(NOW - 5))])
    write_rollout(root, name="rollout-b.jsonl",
                  lines=[meta_line("/Users/K/Other"),
                         turn_line("task_started", _stamp(NOW - 9))])
    st = _state_frame(root)
    assert (st.state, st.n_stuck, st.n_run, st.n_idle) == ("failed", 1, 1, 0)
    assert st.n_sessions() == 2
    assert st.label == "Overwatch"      # the only session holding the state
```

- [ ] **Step 2: Run the tests to verify they fail**

Run: `pytest tests/pc/test_codex_cli.py -q -k "died_on_a_usage or terminal_error or struct_shaped or not_call_a_turn_failure or no_info_is_failed or unexpected_shape or counted_with_the_stuck"`
Expected: FAIL — `assert 'idle' == 'failed'`.

- [ ] **Step 3: Write the implementation**

Replace the `_TURN_EVENTS` block (`pc/providers/codex_cli.py:261-266`) with:

```python
STATE_SRC_ID = "cli-state"
_TURN_EVENTS = {
    "task_started": base.STATE_RUNNING,
    "task_complete": base.STATE_IDLE,
    "turn_aborted": base.STATE_IDLE,
}

# `turn_aborted` is NOT a failure, and the temptation to make it one is why
# this paragraph exists. Its `reason` is one of `interrupted`, `replaced`,
# `review_ended` or `budget_limited` (protocol.rs TurnAbortReason): Esc, a
# new message typed over the running turn, a review closing, a budget
# stopping it. Every one of those is something the PERSON did, and idle --
# "finished, your turn" -- is the right colour for all four. Red is reserved
# for what the model or the API did.
#
# That is `task_complete` carrying an `error`. TurnCompleteEvent.error is
# documented upstream as "Terminal error details when the turn completed
# unsuccessfully", is skipped entirely on success, and its CodexErrorInfo
# includes UsageLimitExceeded -- which is the single event this product
# exists to warn about, and the mirror of Claude's StopFailure error:
# "rate_limit".
#
# NEVER OBSERVED. Every rollout captured on the machine this was written
# against is a success, so this branch is pinned to the upstream schema and
# to tests/ci/check_codex_contract.sh rather than to a real file. It is
# therefore written to degrade toward idle: an `error` that is not an object
# leaves the mapping above exactly as it was.

# The two errors upstream itself says do not fail a turn
# (CodexErrorInfo::affects_turn_status). Both are failures of a client
# OPERATION rather than of the turn, and painting the panel red because a
# thread rollback failed would cry wolf with the one colour that must not.
#
# A deny-list rather than an allow-list, and that direction is deliberate: a
# variant added upstream tomorrow lands on the failing side, which is where
# `Other` already is. A unit variant serialises as a bare snake_case string
# and a struct variant as a single-key object, so both shapes are checked.
_NOT_A_TURN_FAILURE = ("thread_rollback_failed", "active_turn_not_steerable")

def _is_turn_failure(error) -> bool:
    """Does this `task_complete` error mean the turn itself failed?"""
    if not isinstance(error, dict):
        return False
    info = error.get("codex_error_info")
    if isinstance(info, str):
        return info not in _NOT_A_TURN_FAILURE
    if isinstance(info, dict) and len(info) == 1:
        return next(iter(info)) not in _NOT_A_TURN_FAILURE
    # Absent, null, or a shape this version has never seen. Upstream's rule
    # for a missing CodexErrorInfo is that the turn failed
    # (ErrorEvent::affects_turn_status is is_none_or), and so is this: an
    # error object with nothing legible in it is still an error object.
    return True
```

Then, inside `parse_rollout_state`, replace:

```python
        state = _TURN_EVENTS.get(payload.get("type"))
        if state is None:
            continue
```

with:

```python
        kind = payload.get("type")
        state = _TURN_EVENTS.get(kind)
        if state is None:
            continue
        if kind == "task_complete" and _is_turn_failure(payload.get("error")):
            state = base.STATE_FAILED
```

Finally, in `CodexCliProvider.poll`, replace the `n_stuck` line:

```python
                n_stuck=counts.get(base.STATE_STUCK, 0),
```

with:

```python
                # Folded together, exactly as claude_state.poll folds them:
                # the wire has one count for "not working and not finished",
                # and `state` above already says which of the two it is.
                # Mapping failed to nothing would leave a failed session
                # reporting zero -- "Session failed" where the panel should
                # say "Session failed - 2 sessions".
                n_stuck=(counts.get(base.STATE_STUCK, 0)
                         + counts.get(base.STATE_FAILED, 0)),
```

Also update the module's execution-state docstring paragraph at lines 246-257 — the sentence "`task_complete` when the answer is in" is now only half true. Replace that paragraph's second sentence with:

```python
# Codex has no hook interface, but its rollout log is a journal of the same
# transitions: `task_started` when a turn begins, `task_complete` when the
# answer is in -- or, when that record carries an `error`, when the turn died
# instead -- and `turn_aborted` when the person stopped it. The newest of
# these in a file is that session's state, aged by its own timestamp, with
```

- [ ] **Step 4: Run the tests to verify they pass**

Run: `pytest tests/pc/test_codex_cli.py -q`
Expected: PASS, no failures.

- [ ] **Step 5: Run the whole suite**

Run: `pytest tests -q`
Expected: previous total + 10 passed.

- [ ] **Step 6: Commit**

```bash
git add pc/providers/codex_cli.py tests/pc/test_codex_cli.py
git commit -m "feat: a Codex turn that died on an error is failed, not finished"
```

---

### Task 7: Two named providers, one line

**Files:**
- Test only: `tests/pc/test_ingest.py`
- Modify: nothing. `pc/ingest._pair_from` (line 179) already implements the rule; this task proves it holds now that Codex can also carry a name.

**Interfaces:**
- Consumes: the `named()` helper at `tests/pc/test_ingest.py:117` and `Fixed` at line 22.
- Produces: nothing.

**The rule, stated.** The label survives only when exactly one frame is in the state the panel is actually showing — `worst_of(primary, secondary)`, because `protocol.frame_to_usage` sends one light for the whole desk — *and* the summed count for that state is 1. There is no Claude-over-Codex precedence and there must not be: choosing between two projects that are equally true of one line puts a wrong sentence on the panel, and a line nobody can trust is worse than no line. Until this plan, only Claude could set `label`, so the both-named case was unreachable and untested.

- [ ] **Step 1: Write the failing test**

Add to `tests/pc/test_ingest.py`, immediately after `test_a_second_provider_in_a_worse_state_takes_the_name_away`:

```python
def test_two_named_sessions_in_the_same_state_leave_the_board_unnamed():
    """Codex can name a session now, so both providers can arrive holding a
    name for the same state. There is one line and no honest rule for
    choosing between two projects that are equally true of it, so neither is
    shown -- the same refusal each provider already applies within itself,
    applied once more across them. The count carries the meaning.
    """
    bus = ingest.IngestionBus(
        providers=[Fixed(named(provider="claude", state=base.STATE_WAITING,
                               label="LiveClaudeUi", n_wait=1)),
                   Fixed(named(provider="codex", at=NOW - 30,
                               state=base.STATE_WAITING,
                               label="Overwatch", n_wait=1))],
        now=lambda: NOW)
    msg = bus.poll()
    assert msg["state"] == "waiting"
    assert msg["n_wait"] == 2
    assert bus.session_pair() == ("", 2)

def test_a_codex_name_shows_when_it_is_the_only_holder_of_the_state():
    """The other half of the same rule, and the one that would be lost by a
    lazy "Claude wins" precedence: a Claude session merely working beside a
    waiting Codex session leaves exactly one holder of the state the panel is
    showing, and that one is named whichever provider it came from.
    """
    bus = ingest.IngestionBus(
        providers=[Fixed(named(provider="claude", state=base.STATE_RUNNING,
                               label="LiveClaudeUi", n_run=1)),
                   Fixed(named(provider="codex", at=NOW - 30,
                               state=base.STATE_WAITING,
                               label="Overwatch", n_wait=1))],
        now=lambda: NOW)
    msg = bus.poll()
    assert msg["state"] == "waiting"
    assert bus.session_pair() == ("Overwatch", 1)

def test_a_failed_codex_session_outranks_a_waiting_claude_one():
    """base.SEVERITY puts failed first, and protocol.frame_to_usage sends
    worst_of(primary, secondary). A Codex turn that died on a usage limit is
    the loudest thing on the desk and takes the line, name and all.
    """
    bus = ingest.IngestionBus(
        providers=[Fixed(named(provider="claude", state=base.STATE_WAITING,
                               label="LiveClaudeUi", n_wait=1)),
                   Fixed(named(provider="codex", at=NOW - 30,
                               state=base.STATE_FAILED,
                               label="Overwatch", n_stuck=1))],
        now=lambda: NOW)
    msg = bus.poll()
    assert msg["state"] == "failed"
    assert bus.session_pair() == ("Overwatch", 1)
```

- [ ] **Step 2: Run the tests to verify they fail**

Run: `pytest tests/pc/test_ingest.py -q -k "two_named_sessions or only_holder or outranks_a_waiting"`
Expected: **PASS**, all three. This is the one place in the plan where the test is expected to pass on first run, and that is the finding: `_pair_from` already generalises correctly and Task 5 needed no change in `pc/ingest.py`. If any of the three FAILS, stop — `_pair_from` does not generalise, and Task 5 shipped a label the bus mishandles. Report the failure rather than editing `ingest.py` to suit the test.

- [ ] **Step 3: There is no implementation step**

Nothing to write. Confirm by inspection that `pc/ingest.py` and `pc/normalizer.py` are unmodified:

Run: `git diff --stat pc/ingest.py pc/normalizer.py`
Expected: no output.

- [ ] **Step 4: Run the whole suite**

Run: `pytest tests -q`
Expected: previous total + 3 passed.

- [ ] **Step 5: Commit**

```bash
git add tests/pc/test_ingest.py
git commit -m "test: pin what happens when both providers name a session"
```

---

### Task 8: The contract script watches the new fields

**Files:**
- Modify: `tests/ci/check_codex_contract.sh` (append before the final `printf 'PASS ...'`)
- Test: the script is the test.

**Interfaces:**
- Consumes: `fetch()`, `ok()` and `fail()` from the script and `tests/ci/lib.sh`.
- Produces: nothing consumed elsewhere.

**Why this task is not optional.** The reader now depends on five upstream names it did not depend on before, and two of them carry a live rename warning: `#[serde(rename = "task_started", alias = "turn_started")]` and the same for `task_complete`. The day the alias becomes the primary name, the state machine goes silent and every test on `tests/pc/test_codex_cli.py` stays green, because they all feed the reader strings this repo wrote. Every pattern below was verified against `openai/codex@main` on 2026-09-03.

- [ ] **Step 1: Write the failing check**

Append to `tests/ci/check_codex_contract.sh`, immediately before the final `printf 'PASS [codex contract at %s]\n' "$REF"` line:

```sh
# 7. The turn events pc/providers/codex_cli.parse_rollout_state keys on.
#    The aliases are upstream telling us a rename is coming: the v2 wire
#    spells these turn_started/turn_complete. The day the alias becomes the
#    primary name the state machine goes silent and every Python test stays
#    green, because they all feed the reader strings this repo wrote.
grep -q '#\[serde(rename = "task_started", alias = "turn_started")\]' "$FILE" ||
	fail "task_started is no longer the serialised name -- see the turn_started alias"
grep -q '#\[serde(rename = "task_complete", alias = "turn_complete")\]' "$FILE" ||
	fail "task_complete is no longer the serialised name -- see the turn_complete alias"
ok "task_started and task_complete are still the wire names"

# 8. Failure. The reader calls a turn failed when its task_complete carries
#    an `error` object, and UsageLimitExceeded is the case it exists for.
grep -q 'pub struct TurnCompleteEvent' "$FILE" || fail "TurnCompleteEvent is gone"
grep -q 'pub error: Option<ErrorEvent>' "$FILE" ||
	fail "TurnCompleteEvent no longer carries error: Option<ErrorEvent>"
grep -q 'pub codex_error_info: Option<CodexErrorInfo>' "$FILE" ||
	fail "ErrorEvent no longer carries codex_error_info"
grep -q 'UsageLimitExceeded,' "$FILE" ||
	fail "CodexErrorInfo lost UsageLimitExceeded -- the case this reader exists for"
ok "task_complete still reports failure through error/codex_error_info"

# 9. The two errors that do NOT fail a turn. codex_cli._NOT_A_TURN_FAILURE
#    mirrors this exact arm; a variant leaving it would have the panel go red
#    for something upstream does not call a failure, and a variant joining it
#    would have us keep painting red for something that stopped being one.
grep -A2 'pub fn affects_turn_status' "$FILE" |
	grep -q 'Self::ThreadRollbackFailed | Self::ActiveTurnNotSteerable { \.\. } => false,' ||
	fail "affects_turn_status' not-a-failure arm changed -- see codex_cli._NOT_A_TURN_FAILURE"
ok "thread_rollback_failed and active_turn_not_steerable are still not turn failures"

# 10. turn_aborted stays a user action. All four reasons are things the
#     person did, which is why the reader maps every one of them to idle
#     rather than to red.
grep -q 'pub enum TurnAbortReason' "$FILE" || fail "TurnAbortReason is gone"
for reason in Interrupted Replaced ReviewEnded BudgetLimited; do
	grep -A5 'pub enum TurnAbortReason' "$FILE" |
		grep -q "^[[:space:]]*$reason,$" ||
		fail "TurnAbortReason lost $reason -- re-read whether turn_aborted still means idle"
done
ok "turn_aborted still means the person stopped the turn"

# 11. The project name. Line 1 of a rollout is a session_meta record, and its
#     cwd is the only place a Codex session's name can come from -- the
#     filename carries a timestamp and a UUID and nothing else.
grep -q 'pub struct SessionMeta' "$FILE" || fail "SessionMeta is gone"
grep -A20 'pub struct SessionMeta' "$FILE" | grep -q 'pub cwd: PathBuf' ||
	fail "SessionMeta no longer carries cwd -- Codex sessions cannot be named"
ok "session_meta still carries cwd"

POLICY=$(fetch codex-rs/rollout/src/policy.rs)
grep -q 'RolloutItem::SessionMeta(_) => true' "$POLICY" ||
	fail "session_meta is no longer persisted unconditionally"
ok "session_meta is still written to every rollout"
```

- [ ] **Step 2: Run the script to verify the new checks execute**

Run: `sh tests/ci/check_codex_contract.sh`
Expected: `PASS [codex contract at main]`, with the six new `ok` lines visible above it. If it fails on the `fetch` of `codex-rs/rollout/src/policy.rs`, confirm the path — it returned HTTP 200 on 2026-09-03 and `fetch()` names the local copy `rollout-policy.rs`, which does not collide with `protocol.rs`.

- [ ] **Step 3: Prove a check can actually fail**

A contract check that cannot go red is decoration. Verify one:

```bash
mkdir -p /tmp/overwatch-codex-src
sh tests/ci/check_codex_contract.sh >/dev/null 2>&1   # populate the cache
cp "${TMPDIR:-/tmp}/overwatch-codex-contract/"* /tmp/overwatch-codex-src/
sed -i.bak 's/pub cwd: PathBuf/pub working_dir: PathBuf/' /tmp/overwatch-codex-src/protocol.rs
CODEX_SRC_DIR=/tmp/overwatch-codex-src sh tests/ci/check_codex_contract.sh
```

Expected: exits non-zero with `SessionMeta no longer carries cwd -- Codex sessions cannot be named`. Then `rm -rf /tmp/overwatch-codex-src`.

- [ ] **Step 4: Commit**

```bash
git add tests/ci/check_codex_contract.sh
git commit -m "test: watch the rollout fields the name and the failure state now need"
```

---

### Task 9: Everything green together

**Files:** none — this task changes nothing. It is the gate.

**Interfaces:**
- Consumes: every task above.
- Produces: the evidence for the completion claim.

- [ ] **Step 1: Run the full Python suite**

Run: `pytest tests -q`
Expected: `<baseline + 42> passed`, no failures, no errors. (3 + 5 + 11 + 4 + 6 + 10 + 3 = 42 new tests. With the 593 baseline that is 635; with the 561 baseline, 603.)

- [ ] **Step 2: Run the contract script**

Run: `sh tests/ci/check_codex_contract.sh`
Expected: `PASS [codex contract at main]`.

- [ ] **Step 3: Run the firmware host tests**

Run: `sh tests/ci/check_host_tests.sh`
Expected: `PASS [host tests]`. No firmware source changed in this plan; this confirms that. In particular `fmt` must still report its `"Working - caf?"` check, which is what Task 1's argument rests on.

- [ ] **Step 4: Run the hook shim contract**

Run: `sh tests/ci/check_hook_shim.sh sh`
Expected: pass. No shim changed here either — the Claude shim's `_projname` rule (`[0-9A-Za-z][0-9A-Za-z._-]{0,23}`, so no spaces and no non-ASCII) is a **separate open owner decision** and this plan deliberately does not touch it. What this plan does change is the argument: with `encode` no longer escaping, the wire and the firmware can both carry a non-ASCII name, so the shim's refusal is now the only thing stopping a Claude project called `café` from being named. Report that; do not act on it.

- [ ] **Step 5: Confirm the blast radius**

Run: `git diff --stat main...HEAD`
Expected: exactly six files — `pc/protocol.py`, `pc/providers/codex_cli.py`, `tests/pc/test_protocol.py`, `tests/pc/test_codex_cli.py`, `tests/pc/test_ingest.py`, `tests/ci/check_codex_contract.sh`. Anything else means a task went outside its scope.

- [ ] **Step 6: Commit nothing**

There is nothing to commit. If `git status` is not clean, a previous task left work uncommitted — find it and fold it into the commit it belongs to.

---

## Deliberately not done

Named here so a reviewer can see they were considered rather than missed.

- **`waiting` for Codex.** Approval requests are in upstream's never-persisted arm of `should_persist_event_msg`, and no approval event appears in any real rollout. It needs the new Codex hooks system and its own plan. A permission prompt shows as `running` until it is answered — honest, if less useful.
- **`budget_limited` as a failure.** The research called it "arguably failed". It is unobserved, the other three `TurnAbortReason` values are unambiguously user actions, and the owner froze the `turn_aborted` mapping. Splitting one unobserved value out of a frozen mapping is scope creep.
- **The Claude hook shim's name rules.** See Task 9 Step 4.
- **A Codex name in `overwatch status`.** `pc/cli.py:1357-1367` prints only the reading's age. Adding a name there is cosmetic and belongs with the `overwatch status` Board line already queued for v1.2.3.
- **A Codex label with no rate-limit reading.** `normalizer.merge` returns `None` for a provider carrying no percentage, so a Codex state frame — and now its label — only reaches the board when some rollout also has a `token_count` line. That is pre-existing behaviour of the state frame, not something this plan introduces, and changing it would mean changing when a provider is allowed to speak at all.

---

## Self-review

**1. Spec coverage.** Research Q1 (naming) → Tasks 2, 3, 4, 5. Q3 (failure) → Task 6, with the `turn_aborted`-stays-idle correction pinned by a test in Task 6 Step 1 and by the contract check in Task 8. Q3's note that the contract script has gaps around `task_started`/`task_complete`/`TurnAbortReason`/`TurnComplete.error` → Task 8. The 51 MB-file warning → Task 2's separate head read and Task 4's cache. The "label policy should mirror claude_state.py" note → Task 5's one-holder rule and Task 7's cross-provider tests. Q2 is out of scope by instruction and is listed under "Deliberately not done". No gaps.

**2. Placeholder scan.** Every code step carries the code. Every test step carries the test body. No "similar to Task N", no "add error handling", no TBD. Task 7 has no implementation step and says so explicitly with a reason and a verification command, rather than leaving a blank. Task 9 has no code by design and says what it is instead.

**3. Type consistency.** Checked across tasks: `HEAD_BYTES` (Task 2) is used by name in Task 2's tests and by `_head_line` only. `_head_line(path) -> str` (Task 2) is consumed by `_name_for` (Task 4) and monkeypatched by name in Task 4's tests — the module-level lookup in `_name_for` is what makes that patch work, so `_name_for` must call `_head_line(path)` and not hold a reference. `session_meta_cwd(head_line) -> str | None` and `_project_name(cwd) -> str` (Task 3) compose in that order in Task 4; `_project_name` accepts `None` because `session_meta_cwd` can return it, and Task 3's `test_a_cwd_that_is_not_a_string_is_refused_not_raised` pins that. `_prune_names(known)` takes a set; Task 5 passes `set(paths)` and Task 4's test passes a set literal. `_is_turn_failure(error) -> bool` and `_NOT_A_TURN_FAILURE` (Task 6) are used only inside `parse_rollout_state`. `STATE_SRC_ID` is referenced by Task 5's `_state_frame` helper, which Task 6's last test also uses — so Task 6 depends on Task 5 having landed, which the strict ordering guarantees. `meta_line()` is defined in Task 4 and used in Tasks 5 and 6; `failed_line()` is defined in Task 6 and used only there; `turn_line()` and `_stamp()` already exist at `tests/pc/test_codex_cli.py:379` and `:384`.

**Fixed inline during review:** Task 4's test originally patched `codex_cli._head_line` without restoring it, which would have leaked into every later test in the file — wrapped in `try/finally`. Task 6's `_state_frame` was originally re-defined in Task 6, shadowing Task 5's; it now reuses Task 5's. Task 5's `poll` rewrite originally left `base.worst_of(counts)` inline in the constructor, which made the label's `counts.get(state, 0)` unable to see the winning state; it is hoisted to a local first. Task 2's head-bound test originally asserted `HEAD_BYTES > 19 * 1024`, which a 20 KB bound would pass while failing on the first rollout with a longer `base_instructions`; it now demands several times the observation, matching the constant's own comment.

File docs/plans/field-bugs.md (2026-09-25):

# Three field bugs — implementation plan

> **For agentic workers:** REQUIRED SUB-SKILL: Use superpowers:subagent-driven-development (recommended) or superpowers:executing-plans to implement this plan task-by-task. Steps use checkbox (`- [ ]`) syntax for tracking.

**Goal:** Make the panel answer "when did I last use Claude Code", let it doze when the reading has stopped moving, and stop it cold-rebooting when no daemon ever appears.

**Architecture:** Three faults, three layers. **Bug B** is daemon-only: `ClaudeCliProvider` gains one piece of memory — the last statusline payload whose five-hour window was readable — and re-maps it through the existing `statusline_source` code when the live payload has no session percentage. Nothing in the merge rule changes; the remembered reading competes by recency like every other frame and therefore wins only when it is the freshest session reading anybody has. **Bug A** is firmware: a new host-testable module remembers the age and activity the daemon last reported, `sleep_gate` gains a second rule keyed on that age, and `ui_sleep_run` gains a caller-supplied wake predicate so a board can doze through a chatty daemon. **Bug C** is firmware: the `sys_reboot` on "no daemon in 60 s" becomes the same sleep, reusing the predicate machinery Bug A introduces.

**Tech Stack:** Python 3.10+ (`pc/`, pytest), C99 Zephyr firmware (`firmware/src/`, plain-`cc` host tests under `tests/`), LVGL for the panel.

**Spec:** `/private/tmp/claude-502/-Users-KfirLevy-Projects-LiveClaudeUi/aeb3001d-3255-41ed-b053-ecf8e0cdec4c/scratchpad/field-bugs.md` (root-cause investigation, with the log evidence and the option analysis; the decisions taken from it are restated below).

## Global Constraints

> **Renamed after execution — applies to every code block below.** What tasks 5
> to 8 call `SLEEP_STALE_AFTER_S` and `sleep_reading_is_old()` are now
> `SLEEP_ABSENT_AFTER_S` and `sleep_nobody_is_here()`. A later fix added a
> SECOND threshold, `SLEEP_READING_STALE_AFTER_S` (1800 s) with
> `sleep_reading_is_stale()`, and the two were one word apart — in a change
> whose entire subject is that "is anybody here" and "is this number old" are
> different questions. The four-hour one was renamed to say absence. Read the
> old names below as the new ones, and note that `grep SLEEP_STALE_AFTER_S`
> now substring-matches the 1800 s constant, so it is not a safe way to find
> the four-hour one.

- **No wire change without proving the budget.** The `usage` message measures ~510 of `protocol.MAX_LINE_BYTES = 512`, and `proto.c` drops an over-long line WHOLE — a silent panel freeze with no error. No task in this plan adds a wire field; if one is proposed, it must measure the worst case first.
- Firmware is C99, kernel style: tabs, `/* */` comments, braces on every `if` body. Every Y in `usage_layout.h` sits on a 4 px rhythm.
- **`usage_view.c` cannot be compiled on a laptop** (needs LVGL, no automated coverage). `tools/panel_render/render.sh` compiles it unchanged against real LVGL and writes a framebuffer; scenes live in `tools/panel_render/render_main.c`. Pure logic belongs in `fmt.c`, `usage_state.c`, `sleep_gate.c` or a new sibling — those are host-tested.
- **Firmware is not done until flashed and boot-verified.** The board is at `/dev/cu.usbserial-14240`; the port re-enumerates on reset. The production daemon holds it under launchd as `com.overwatch.bridge`. Freeing it: `launchctl bootout gui/502/com.overwatch.bridge`. Restoring it needs **both** `launchctl bootstrap` AND `launchctl kickstart` — bootstrap registers without starting.
- Python 3.10+, matching `pc/` style. `pytest tests -q` passes 530 today; `sh tests/ci/check_host_tests.sh` runs 14 suites. Both green at every commit.
- Comments explain WHY, in prose, at the density of the surrounding file.
- **A test that cannot fail is worse than no test.** This branch has found five. Every task below carries an explicit "prove it bites" step: build the broken variant, watch the test reject it, put the code back.
- UI copy is sentence case: every on-screen sentence starts with a capital letter.
- Do not touch anything under `~/.overwatch` except by the launchctl commands above. The daemon and board are live on this machine.

---

## The three decisions this plan implements

**Bug B — "I used Claude Code 6 hours ago but it says 56 hours."**
Decision: **remember the last CLI reading.** `pc/normalizer.py::merge` is strict field-by-field recency and desktop is not preferred; desktop won only because the CLI reading *ceased to exist* as a candidate (`session_pct == -1` once the five-hour window expired and Claude Code stopped rendering), leaving `age_s` describing the desktop sample. The daemon re-reads statelessly (`ClaudeCliProvider.poll`) and remembers nothing. Give it memory.

**Bug A — "the computer slept but OVERWATCH stayed awake all night showing 'Reading is old'."**
Decision: **firmware sleeps on a stale reading too.** `sleep_gate.c` requires `host_lost && had_usage && !ota_busy`, and `proto.c:262-265` clears `host_lost` on every protocol line, pings included. The daemon pinged all night. Extend the gate with an age-based rule; keep the daemon dumb so boards fix themselves against any daemon version.

**Bug C — "no daemon running: it sits on 1/2, then resets after a few minutes."**
Decision: **make never-connected match connected-then-gone.** `main.c:1498-1503` is a deliberate `sys_reboot(SYS_REBOOT_COLD)` into standalone. Replace it with sleep, preserving the `!proto_host_seen()` guard.

### Why the module docstring's "understating vs inventing" reasoning survives Bug B

`pc/normalizer.py`'s docstring rejects "prefer the HIGHER percentage" because across a window reset that rule invents usage that has already been forgiven. The fix here does not touch preference at all. The remembered frame carries its original `observed_at` (the payload's mtime) and enters `_pick` as an ordinary candidate, so it wins the session dial **only when it is the freshest session reading in the set**. Concretely: it beat a 57-hour desktop sample in the field because it was 51 hours fresher, and it will lose to a five-minute-old desktop sample tomorrow. We never show an older number than the code shows today.

The residual invention risk — a remembered 27% outliving its own five-hour window — is already handled twice by code we deliberately re-enter rather than duplicate:

1. Inside `STALE_AFTER_S` (1800 s) of the mtime, `statusline_source._rolled_over` turns a window whose `resets_at` has passed into a hard `0.0` and records `session_rolled_at`, which then evicts any *other* source's pre-reset reading through `_survives_rollover`.
2. Past 1800 s, `map_statusline_frame` sets `stale=True` and deliberately skips `_rolled_over` ("on an old one the same reasoning inverts... 0% would be the lie"). The percentage travels with `stale=True`, `secs_until` refuses the past reset time so no countdown is drawn, and the panel says `"Reading is old - showing last known"`.

That is why the fix caches the **raw payload and its mtime** rather than the mapped frame: re-mapping at the current `now` runs all of that reasoning at the right time, for free. Caching a `NormalizedUsageFrame` instead would freeze `stale=False` at capture and put a green dot over a six-hour-old number — the exact confident-wrong-number failure the docstring exists to prevent.

### Sequencing: how A and C relate

They **share one task** (Task 6, the `ui_sleep_run` signature) and are otherwise independent. Both need a board to doze while something is still notionally present, and today `ui_sleep_run` hard-codes its wake condition as `proto_host_seen()` — which is permanently true in Bug A's scenario (the daemon never stopped pinging), so a stale-sleep built on today's function would close and open its eyes in a loop. Task 6 makes the wake condition a parameter; A passes an age-based predicate, C passes the host-based one that is today's default. A is done first because it defines the predicate vocabulary C then reuses in its simplest form. C also *depends on* a fix that falls out of Task 6: `ui_sleep_run` currently ends with an unconditional `usage_view_set_status(USAGE_STATUS_STALE)`, which would stamp "reading is old" over a board that has no reading at all (C) or over the fresh frame that just woke it (A).

---

## File Structure

| File | Status | Responsibility |
|---|---|---|
| `pc/providers/claude_cli.py` | Modify | Gains one field: the last payload whose five-hour window was readable, re-mapped when the live payload has none. |
| `tests/pc/test_claude_cli.py` | Create | The provider's memory: what is remembered, when it is emitted, when it is replaced, that its age grows. |
| `tests/pc/test_normalizer.py` | Modify | Pins the merge invariant the fix leans on: a stale CLI frame with a known percentage beats an older desktop frame. |
| `tests/pc/test_ingest.py` | Modify | End-to-end at the seam: bus + real `ClaudeCliProvider` + a desktop frame produces `src: "cli"` with a growing `age_s`. |
| `firmware/src/usage_freshness.h/.c` | Create | Remembers the age and activity of the last `usage` message and grows the age with uptime. Pure C, no Zephyr, host-testable. |
| `tests/usage_freshness/host_test.c` | Create | Host test for the above. |
| `firmware/src/sleep_gate.h/.c` | Modify | Gains the stale-reading rule and its exact complement, the wake rule. Still pure. |
| `tests/sleep_gate/host_test.c` | Modify | Grid test that start and wake are complements, and that the threshold is where it says it is. |
| `firmware/src/ui_sleep.h/.c` | Modify | Wake condition and peek note become parameters; the wake-time STALE stamp becomes conditional. |
| `firmware/src/proto.c` | Modify | Two lines: hand the parsed `age_s` and activity to `usage_freshness`. |
| `firmware/src/main.c` | Modify | `run_usb` gains the stale-sleep branch (A) and trades its `sys_reboot` for a sleep (C). |
| `firmware/CMakeLists.txt` | Modify | Adds `src/usage_freshness.c`. |
| `tests/ci/check_host_tests.sh` | Modify | Adds the `usage_freshness` row; `sleep_gate` gains a source. |
| `docs/sleep-mode-design.md` | Modify | Documents the second way to enter sleep and the threshold. |

No task adds a field to the `usage` wire message. `age_s` and `state` are already sent and already parsed by `proto.c` (lines 336-341 and 418-422); the firmware simply stops throwing them away.

---

### Task 1: Pin the merge invariant the Bug B fix leans on

The fix works by handing the merge a CLI frame that is stale but carries a percentage, and trusting recency to prefer it over an older desktop frame. That behaviour is real today (the investigation's CASE1) but nothing pins it, so a future tidy-up of `_pick` could silently restore the bug. This is a characterization test written before the code that depends on it.

**Files:**
- Modify: `tests/pc/test_normalizer.py` (append; helpers `cli()` and `desktop()` already exist at the top of the file)

**Interfaces:**
- Consumes: `normalizer.merge(frames)`, `tests/pc/test_normalizer.py::cli`, `::desktop` (already defined there).
- Produces: nothing other tasks import. It guards `merge`'s recency rule for Tasks 2 and 3.

- [ ] **Step 1: Write the test**

Append to `tests/pc/test_normalizer.py`:

```python
def test_a_stale_reading_that_has_a_number_beats_a_fresher_one_that_does_not():
    """The invariant pc/providers/claude_cli's memory is built on.

    A CLI reading six hours old still carries a five-hour percentage; a
    desktop sample two days older carries one too. Staleness does not remove
    a frame from the contest -- recency ranks it -- so the CLI figure wins
    and `src` follows it. If this ever inverts, the panel goes back to
    reporting the age of a desktop sample nobody asked about (field report,
    2026-09-02).
    """
    m = normalizer.merge([
        cli(NOW - 6 * 3600, session=27.0, stale=True),
        desktop(NOW - 57 * 3600, session=0.0, stale=True),
    ])
    assert m.session_pct == 27.0
    assert m.src == "cli"
    assert m.observed_at == NOW - 6 * 3600
    assert m.stale is True
```

- [ ] **Step 2: Run it**

Run: `pytest tests/pc/test_normalizer.py::test_a_stale_reading_that_has_a_number_beats_a_fresher_one_that_does_not -v`
Expected: PASS. This one characterizes existing behaviour, so passing on the first run is correct — Step 3 is what proves it is not vacuous.

- [ ] **Step 3: Prove the test bites**

Temporarily add `and not f.stale` to the `has` lambda for `session_pct` in `pc/normalizer.py::merge`:

```python
    session_pct, session_src = _pick(
        frames,
        lambda f: (_known_pct(f.session_pct) and not f.stale
                   and _survives_rollover(f, s_rolled, "session_rolled_at")),
        lambda f: f.session_pct)
```

Run the same command. Expected: FAIL — `m.src == "desktop"`, which is exactly the field bug. Revert the edit with `git checkout -- pc/normalizer.py` and re-run to confirm PASS.

- [ ] **Step 4: Commit**

```bash
git add tests/pc/test_normalizer.py
git commit -m "test: pin that a stale reading with a number beats a fresher blank one"
```

---

### Task 2: The CLI provider remembers its last usable reading

**Files:**
- Modify: `pc/providers/claude_cli.py`
- Create: `tests/pc/test_claude_cli.py`

**Interfaces:**
- Consumes: `pc.statusline_source.read_payload(path) -> (payload|None, mtime|None)`, `pc.statusline_source.map_statusline_frame(payload, now_epoch, mtime_epoch) -> NormalizedUsageFrame`, `pc.statusline_source.STALE_AFTER_S = 1800`, `pc.providers.base.UNKNOWN = -1.0`.
- Produces: `ClaudeCliProvider.poll(now_epoch) -> list[NormalizedUsageFrame]`, unchanged signature, now returning **up to two** frames — the live reading (when the file parses) and, when the live reading has no five-hour percentage, the remembered one. Both carry `src == "cli"`; they differ in `observed_at`. Task 3 consumes this.

- [ ] **Step 1: Write the failing tests**

Create `tests/pc/test_claude_cli.py`:

```python
"""The one thing this provider remembers, and why it may.

The status line is rewritten only when Claude Code renders. When the
five-hour window expires and nobody is rendering, the payload stops carrying
a percentage, the frame stops being a candidate for the session dial, and the
panel falls to whatever else is on the bus -- in the field, a Claude Desktop
sample 57 hours old, whose age was then drawn as "56h ago" over a machine
that had used Claude Code six hours earlier.
"""
import json

from pc import statusline_source as ss
from pc.providers.claude_cli import ClaudeCliProvider

NOW = 1_787_700_000.0

def write(path, payload, mtime):
    path.write_text(json.dumps(payload), encoding="utf-8")
    import os
    os.utime(path, (mtime, mtime))
    return path

def payload(five_hour=27.0, resets_at=None, seven_day=12.0):
    limits = {"seven_day": {"used_percentage": seven_day}}
    if five_hour is not None:
        limits["five_hour"] = {"used_percentage": five_hour,
                               "resets_at": resets_at}
    return {"rate_limits": limits}

def test_a_live_reading_is_returned_alone(tmp_path):
    p = write(tmp_path / "statusline.json",
              payload(five_hour=27.0, resets_at=NOW + 900), NOW - 60)
    prov = ClaudeCliProvider(path=str(p))

    frames = prov.poll(NOW)

    assert len(frames) == 1
    assert frames[0].session_pct == 27.0

def test_the_last_reading_with_a_percentage_is_offered_when_the_file_loses_one(tmp_path):
    """The field case: the window expired and the file was rewritten without
    it, so the only session figure left in the world is the one we read an
    hour ago."""
    p = tmp_path / "statusline.json"
    prov = ClaudeCliProvider(path=str(p))

    write(p, payload(five_hour=27.0, resets_at=NOW - 7200), NOW - 6 * 3600)
    prov.poll(NOW - 6 * 3600 + 1)

    write(p, {"rate_limits": {"seven_day": {"used_percentage": 12.0}}}, NOW - 60)
    frames = prov.poll(NOW)

    remembered = [f for f in frames if f.session_pct >= 0]
    assert len(remembered) == 1
    assert remembered[0].session_pct == 27.0
    assert remembered[0].observed_at == NOW - 6 * 3600
    assert remembered[0].src == "cli"

def test_the_remembered_reading_is_marked_stale_by_its_own_age(tmp_path):
    """Not frozen at the staleness it had when captured. A six-hour-old
    number under a green dot is the confident-wrong-number failure
    pc/normalizer's docstring exists to prevent."""
    p = tmp_path / "statusline.json"
    prov = ClaudeCliProvider(path=str(p))

    write(p, payload(five_hour=27.0, resets_at=NOW - 7200), NOW - 6 * 3600)
    prov.poll(NOW - 6 * 3600 + 1)
    assert prov.poll(NOW - 6 * 3600 + 1)[0].stale is False

    write(p, {"rate_limits": {}}, NOW - 60)
    remembered = [f for f in prov.poll(NOW) if f.session_pct >= 0][0]
    assert remembered.stale is True

def test_the_remembered_reading_ages(tmp_path):
    """The whole point: the age must answer "when did you last use Claude
    Code", so it grows with the wall clock instead of resetting each poll."""
    p = tmp_path / "statusline.json"
    prov = ClaudeCliProvider(path=str(p))

    write(p, payload(five_hour=27.0, resets_at=NOW - 7200), NOW - 3600)
    prov.poll(NOW - 3600 + 1)
    write(p, {"rate_limits": {}}, NOW - 60)

    a = [f for f in prov.poll(NOW) if f.session_pct >= 0][0]
    b = [f for f in prov.poll(NOW + 60) if f.session_pct >= 0][0]
    assert a.observed_at == b.observed_at == NOW - 3600

def test_a_newer_reading_with_a_percentage_replaces_the_remembered_one(tmp_path):
    p = tmp_path / "statusline.json"
    prov = ClaudeCliProvider(path=str(p))

    write(p, payload(five_hour=27.0, resets_at=NOW + 900), NOW - 3600)
    prov.poll(NOW - 3599)
    write(p, payload(five_hour=61.0, resets_at=NOW + 900), NOW - 60)
    prov.poll(NOW)

    write(p, {"rate_limits": {}}, NOW - 30)
    remembered = [f for f in prov.poll(NOW) if f.session_pct >= 0][0]
    assert remembered.session_pct == 61.0

def test_a_vanished_file_still_leaves_the_memory(tmp_path):
    """read_payload returns nothing for an absent or malformed file, and that
    is not evidence the last reading never happened."""
    p = tmp_path / "statusline.json"
    prov = ClaudeCliProvider(path=str(p))

    write(p, payload(five_hour=27.0, resets_at=NOW + 900), NOW - 3600)
    prov.poll(NOW - 3599)
    p.unlink()

    frames = prov.poll(NOW)
    assert len(frames) == 1
    assert frames[0].session_pct == 27.0

def test_nothing_is_invented_before_the_first_good_reading(tmp_path):
    p = write(tmp_path / "statusline.json", {"rate_limits": {}}, NOW - 60)
    prov = ClaudeCliProvider(path=str(p))

    frames = prov.poll(NOW)
    assert all(f.session_pct < 0 for f in frames)

def test_the_memory_does_not_survive_a_new_daemon(tmp_path):
    """Deliberately in-memory: a fresh process starts with no history. Pinned
    so the decision is visible rather than accidental."""
    p = tmp_path / "statusline.json"
    write(p, payload(five_hour=27.0, resets_at=NOW + 900), NOW - 3600)
    ClaudeCliProvider(path=str(p)).poll(NOW - 3599)

    write(p, {"rate_limits": {}}, NOW - 60)
    frames = ClaudeCliProvider(path=str(p)).poll(NOW)
    assert all(f.session_pct < 0 for f in frames)
```

- [ ] **Step 2: Run them to verify they fail**

Run: `pytest tests/pc/test_claude_cli.py -v`
Expected: `test_a_live_reading_is_returned_alone`, `test_nothing_is_invented_before_the_first_good_reading` and `test_the_memory_does_not_survive_a_new_daemon` PASS (they describe today's stateless behaviour). The other five FAIL with `IndexError: list index out of range` or `assert 0 == 1` — there is no memory yet.

- [ ] **Step 3: Implement the memory**

In `pc/providers/claude_cli.py`, extend the module docstring, `__init__` and `poll`:

Append to the module docstring, after the existing final paragraph:

```
One thing IS remembered, and only one: the last payload whose five-hour
window we could actually read. The file is rewritten when Claude Code
renders, and when the window expires with nobody rendering, the rewrite
drops the percentage -- so the reading does not lose a comparison, it stops
existing, and the panel falls to whatever else is on the bus. In the field
that was a Claude Desktop sample 57 hours old, whose age was drawn over a
machine that had used Claude Code six hours earlier.

The RAW payload is kept, not the frame it maps to, and it is re-mapped at
the current clock every time it is offered. That is the whole reason this is
five lines instead of a policy: staleness, a window carried across its own
reset, and the refusal to zero an old one all live in map_statusline_frame
and all depend on `now`. A cached frame would freeze `stale=False` at
capture and put a green dot over an hours-old number, which is precisely
what pc/normalizer's docstring exists to prevent.

The memory dies with the process, deliberately. It answers "since this
daemon started, when did you last use Claude Code", and a daemon restart is
almost always an app update or a login -- after which the desktop cache is
as good an answer as we have. Persisting it would put a second copy of a
file that already exists on disk into ~/.overwatch, with its own invalidation
and corruption paths, for a case the field report does not contain.
```

Replace `__init__` and `poll`:

```python
    def __init__(self, path=None):
        self._path = path if path is not None else ss.PAYLOAD_PATH
        # (payload, mtime) for the last reading that had a five-hour
        # percentage, or None before the first one. See the module docstring.
        self._remembered = None

    def poll(self, now_epoch):
        payload, mtime = ss.read_payload(self._path)
        frames = []
        if payload is not None:
            live = self.parse_cli_event(payload, now_epoch, mtime)
            if live is not None:
                frames.append(live)
                # base.UNKNOWN is -1.0; anything >= 0 is a real percentage,
                # including the hard 0.0 map_statusline_frame computes for a
                # window it watched roll over.
                if live.session_pct >= 0:
                    self._remembered = (payload, mtime)
                    return frames

        # The live reading has no session figure, so offer the last one that
        # did -- ALONGSIDE the live frame rather than instead of it. They are
        # merged field by field, so the live payload keeps whatever it still
        # has (a seven-day percentage outlives the five-hour window every
        # time) and the remembered one is a candidate for the session dial
        # only. The normalizer then ranks it by recency like anything else,
        # so it wins the dial only when it is genuinely the freshest session
        # reading in the set.
        if self._remembered is not None:
            payload, mtime = self._remembered
            remembered = self.parse_cli_event(payload, now_epoch, mtime)
            if remembered is not None:
                frames.append(remembered)
        return frames
```

- [ ] **Step 4: Run the tests to verify they pass**

Run: `pytest tests/pc/test_claude_cli.py -v`
Expected: all eight PASS.

- [ ] **Step 5: Prove the tests bite**

Change `if live.session_pct >= 0:` to `if live.session_pct > 0:` and run again. Expected: FAIL — a remembered `0.0` from a rolled-over window is no longer captured (this is the boundary `base.UNKNOWN = -1.0` sits just below, and getting it wrong loses the one reading that *is* certain). Restore it.

Then replace the re-mapping with a cached frame — `self._remembered = live` in the capture branch and `frames.append(self._remembered)` below — and run again. Expected: `test_the_remembered_reading_is_marked_stale_by_its_own_age` FAILs with `assert False is True`, which is the green-dot-over-an-old-number regression. Restore.

- [ ] **Step 6: Run the whole Python suite**

Run: `pytest tests -q`
Expected: 530 passed + the 8 new = 538 passed, 0 failed.

- [ ] **Step 7: Commit**

```bash
git add pc/providers/claude_cli.py tests/pc/test_claude_cli.py
git commit -m "fix: the panel forgot the last Claude Code reading the moment its window expired"
```

---

### Task 3: Prove it at the seam — bus in, message out

Task 2 tests the provider in isolation. The bug was reported as a number on a panel, and the path from provider to that number runs through `IngestionBus.poll` → `normalizer.select_pair` → `protocol.frame_to_usage`, where `age_s` is finally computed. This task pins the whole path.

**Files:**
- Modify: `tests/pc/test_ingest.py` (append; `Fixed`, `frame()` and `NOW` already exist at the top)

**Interfaces:**
- Consumes: `ClaudeCliProvider.poll` from Task 2, `ingest.IngestionBus(providers=..., now=...)`, `ingest.IngestionBus.poll() -> dict`, the message keys `src`, `session_pct`, `age_s`.
- Produces: nothing other tasks import.

- [ ] **Step 1: Write the failing test**

Append to `tests/pc/test_ingest.py`:

```python
def test_the_panel_reports_the_age_of_the_last_claude_code_reading(tmp_path):
    """The field bug, end to end (2026-09-02).

    Claude Code was used six hours ago and its five-hour window has since
    expired, so the status line no longer carries a percentage. Claude
    Desktop was last open 57 hours ago. The message must carry the CLI
    reading and ITS age -- the desktop sample's 57 hours is an honest answer
    to a question nobody asked.
    """
    import json
    import os

    from pc.providers.claude_cli import ClaudeCliProvider

    p = tmp_path / "statusline.json"

    def write(doc, mtime):
        p.write_text(json.dumps(doc), encoding="utf-8")
        os.utime(p, (mtime, mtime))

    cli = ClaudeCliProvider(path=str(p))
    desktop = Fixed(frame(src="desktop", at=NOW - 57 * 3600, session=0.0,
                          weekly=0.0))

    write({"rate_limits": {"five_hour": {"used_percentage": 27.0,
                                         "resets_at": NOW - 7200}}},
          NOW - 6 * 3600)
    now = [NOW - 6 * 3600 + 1]
    bus = ingest.IngestionBus(providers=[cli, desktop],
                              now=lambda: now[0])
    bus.poll()

    write({"rate_limits": {}}, NOW - 60)
    now[0] = NOW
    msg = bus.poll()

    assert msg["src"] == "cli"
    assert msg["session_pct"] == 27.0
    assert msg["age_s"] == 6 * 3600
    assert msg["stale"] is True

    now[0] = NOW + 60
    assert bus.poll()["age_s"] == 6 * 3600 + 60
```

- [ ] **Step 2: Run it**

Run: `pytest tests/pc/test_ingest.py::test_the_panel_reports_the_age_of_the_last_claude_code_reading -v`
Expected: PASS, on the strength of Task 2. If Task 2 is not yet applied it fails with `assert 'desktop' == 'cli'`.

- [ ] **Step 3: Prove the test bites**

`git stash` the `pc/providers/claude_cli.py` change from Task 2 (`git stash push pc/providers/claude_cli.py`), re-run. Expected: FAIL with `assert 'desktop' == 'cli'` and `age_s == 205200` — the field bug reproduced through the real seam. `git stash pop` and re-run to confirm PASS.

- [ ] **Step 4: Commit**

```bash
git add tests/pc/test_ingest.py
git commit -m "test: pin the reported age against the last Claude Code reading, end to end"
```

---

### Task 4: `usage_freshness` — the board remembers how old its reading is

`proto.c` already parses `age_s` and computes the activity enum; both are handed to `usage_view` and then unreachable from `main.c`, where the sleep decision is made. This module keeps them somewhere a laptop can test.

**Files:**
- Create: `firmware/src/usage_freshness.h`
- Create: `firmware/src/usage_freshness.c`
- Create: `tests/usage_freshness/host_test.c`
- Modify: `firmware/src/proto.c` (after line 422, `usage_view_set_ages(...)`)
- Modify: `firmware/CMakeLists.txt` (after `src/usage_state.c`, line 32)
- Modify: `tests/ci/check_host_tests.sh` (the `run_one` table)

**Interfaces:**
- Consumes: `enum usage_activity` from `usage_view.h`.
- Produces:
  - `void usage_freshness_note(int32_t age_s, enum usage_activity act, int64_t now_ms);`
  - `int32_t usage_freshness_age_s(int64_t now_ms);` — the noted age plus elapsed uptime, or `-1` before the first note or when the daemon sent no age.
  - `enum usage_activity usage_freshness_activity(void);` — `USAGE_ACTIVITY_NONE` before the first note.
  Tasks 5 and 7 consume all three.

- [ ] **Step 1: Write the failing host test**

Create `tests/usage_freshness/host_test.c`:

```c
/* What the board knows about the age of the figures on its own screen.
 *
 *   cc -Wall -Werror -I firmware/src tests/usage_freshness/host_test.c \
 *      firmware/src/usage_freshness.c -o /tmp/usage_freshness
 */
#include <stdio.h>
#include "usage_freshness.h"

static int fails;
#define CHECK(c) do { if (!(c)) { fails++; printf("FAIL %s:%d %s\n", __FILE__, __LINE__, #c); } } while (0)

int main(void)
{
	/* Nothing has arrived yet: not "brand new", unknown. */
	CHECK(usage_freshness_age_s(1000) == -1);
	CHECK(usage_freshness_activity() == USAGE_ACTIVITY_NONE);

	/* A daemon older than this firmware sends no age at all. That must
	 * stay unknown rather than becoming a very fresh zero, which would
	 * hold the panel awake forever against every such daemon. */
	usage_freshness_note(-1, USAGE_ACTIVITY_NONE, 10000);
	CHECK(usage_freshness_age_s(70000) == -1);

	/* The ordinary case, and the one the sleep gate reads: the daemon
	 * says the reading is an hour old, and a minute later it is an hour
	 * and a minute old even though nothing new arrived. */
	usage_freshness_note(3600, USAGE_ACTIVITY_IDLE, 100000);
	CHECK(usage_freshness_age_s(100000) == 3600);
	CHECK(usage_freshness_age_s(160000) == 3660);
	CHECK(usage_freshness_activity() == USAGE_ACTIVITY_IDLE);

	/* A fresh reading resets the clock it grows from. */
	usage_freshness_note(1, USAGE_ACTIVITY_RUNNING, 200000);
	CHECK(usage_freshness_age_s(260000) == 61);
	CHECK(usage_freshness_activity() == USAGE_ACTIVITY_RUNNING);

	/* k_uptime_get is monotonic, but a caller that passes a stale
	 * timestamp must not produce an age that runs backwards past the
	 * figure the daemon actually gave us. */
	CHECK(usage_freshness_age_s(199000) == 1);

	printf("%s\n", fails ? "FAIL" : "ok   usage_freshness");
	return fails ? 1 : 0;
}
```

- [ ] **Step 2: Run it to verify it fails**

Run: `cc -Wall -Werror -I firmware/src tests/usage_freshness/host_test.c firmware/src/usage_freshness.c -o /tmp/uf`
Expected: BUILD FAILS — `fatal error: 'usage_freshness.h' file not found`.

- [ ] **Step 3: Write the module**

Create `firmware/src/usage_freshness.h`:

```c
#ifndef USAGE_FRESHNESS_H
#define USAGE_FRESHNESS_H

#include <stdint.h>

#include "usage_view.h"

/*
 * How old the figures on the screen are, and what the tool feeding them was
 * doing -- the two facts the sleep gate needs and the only two the board
 * used to throw away.
 *
 * proto.c parses both out of every `usage` message (`age_s`, `state`) and
 * hands them to usage_view, which draws them and keeps them behind LVGL
 * where main.c cannot ask and no laptop can test. This holds the same two
 * values in a translation unit with no Zephyr and no LVGL in it, for the
 * same reason usage_state.c exists.
 *
 * The age GROWS between messages. The daemon recomputes it every 60 s, so
 * this mostly agrees with what is drawn -- but a board dozing on a stale
 * reading is deciding whether to keep dozing in the gaps, and an age frozen
 * at whatever last arrived would answer that question with the wrong number
 * for up to a minute at a time.
 */
void usage_freshness_note(int32_t age_s, enum usage_activity act,
			  int64_t now_ms);

/* Seconds since the shown reading was taken, or -1 when we cannot say --
 * before the first message, or from a daemon too old to send an age. Unknown
 * is not zero: a caller that treats it as a fresh reading holds the panel
 * awake against every such daemon. */
int32_t usage_freshness_age_s(int64_t now_ms);

/* What the last message said the tool was doing. USAGE_ACTIVITY_NONE before
 * any message, which is the same "said nothing" the enum already means. */
enum usage_activity usage_freshness_activity(void);

#endif /* USAGE_FRESHNESS_H */
```

Create `firmware/src/usage_freshness.c`:

```c
#include "usage_freshness.h"

static int32_t noted_age_s = -1;
static int64_t noted_at_ms;
static enum usage_activity noted_act = USAGE_ACTIVITY_NONE;

void usage_freshness_note(int32_t age_s, enum usage_activity act,
			  int64_t now_ms)
{
	noted_age_s = age_s;
	noted_at_ms = now_ms;
	noted_act = act;
}

int32_t usage_freshness_age_s(int64_t now_ms)
{
	int64_t grown;

	if (noted_age_s < 0) {
		return -1;
	}
	if (now_ms < noted_at_ms) {
		/* Cannot happen with k_uptime_get, which is monotonic. If it
		 * ever does, the daemon's own figure is still true of the
		 * moment it arrived, and an age that ran backwards would read
		 * as a reading getting fresher on its own. */
		return noted_age_s;
	}
	grown = (int64_t)noted_age_s + (now_ms - noted_at_ms) / 1000;
	if (grown > INT32_MAX) {
		grown = INT32_MAX;
	}
	return (int32_t)grown;
}

enum usage_activity usage_freshness_activity(void)
{
	return noted_act;
}
```

- [ ] **Step 4: Run the host test to verify it passes**

Run: `cc -Wall -Werror -I firmware/src tests/usage_freshness/host_test.c firmware/src/usage_freshness.c -o /tmp/uf && /tmp/uf`
Expected: `ok   usage_freshness`, no FAIL lines.

- [ ] **Step 5: Prove the test bites**

Change `if (noted_age_s < 0) { return -1; }` to `if (noted_age_s < 0) { return 0; }` and re-run. Expected: `FAIL ... usage_freshness_age_s(1000) == -1`. Restore.

Then delete `noted_at_ms = now_ms;` from `usage_freshness_note` and re-run. Expected: `FAIL ... usage_freshness_age_s(260000) == 61`. Restore.

- [ ] **Step 6: Wire it into `proto.c`**

In `firmware/src/proto.c`, add to the include block near line 15:

```c
#include "usage_freshness.h"
```

and immediately after `usage_view_set_ages((int32_t)age, (int32_t)p2age);` (line 422):

```c
		/* The same two facts, kept where main.c can ask and a laptop
		 * can test the reasoning about them. See usage_freshness.h. */
		usage_freshness_note((int32_t)age, act, k_uptime_get());
```

`act` is the `enum usage_activity` declared earlier in this same `usage` branch (line 336) and is still in scope.

- [ ] **Step 7: Register the new source and the new host test**

In `firmware/CMakeLists.txt`, after `src/usage_state.c`:

```
	src/usage_freshness.c
```

In `tests/ci/check_host_tests.sh`, after the `usage_state` row:

```sh
run_one usage_freshness "usage_freshness.c" ""
```

- [ ] **Step 8: Run the host suite**

Run: `sh tests/ci/check_host_tests.sh`
Expected: `PASS [host tests]` with 15 rows, `usage_freshness ok (9 checks)` among them.

- [ ] **Step 9: Commit**

```bash
git add firmware/src/usage_freshness.h firmware/src/usage_freshness.c \
        firmware/src/proto.c firmware/CMakeLists.txt \
        tests/usage_freshness/host_test.c tests/ci/check_host_tests.sh
git commit -m "feat: the board can now say how old the figures on its screen are"
```

---
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

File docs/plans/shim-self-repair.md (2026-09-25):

# Shim Self-Repair Implementation Plan

> **For agentic workers:** REQUIRED SUB-SKILL: Use superpowers:subagent-driven-development (recommended) or superpowers:executing-plans to implement this plan task-by-task. Steps use checkbox (`- [ ]`) syntax for tracking.

**Goal:** Make `~/.overwatch/overwatch-hook.sh` repair itself when it is older than the daemon that reads it, so the session-name feature stops being a silent no-op on every install that arrives by `overwatch update`.
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

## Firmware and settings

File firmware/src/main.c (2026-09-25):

#include <zephyr/kernel.h>
#include <zephyr/device.h>
#include <zephyr/drivers/display.h>
#include <zephyr/drivers/mipi_dbi.h>
#include <zephyr/drivers/watchdog.h>
#include <zephyr/dfu/mcuboot.h>
#include <zephyr/random/random.h>
#include <zephyr/sys/reboot.h>
#include <lvgl.h>
#include <mbedtls/platform.h>
#include <string.h>
#include <errno.h>

#include "proto.h"
#include "usage_view.h"
#include "ui_pages.h"
#include "ui_music.h"
#include "cfg_store.h"
#include "ui_theme.h"
#include "backlight.h"
#include "net_wifi.h"
#include "net_time.h"
#include "portal.h"
#include "ui_setup.h"
#include "dns_hijack.h"
#include "oauth.h"
#include "usage_client.h"
#include "ui_boot.h"
#include "ui_sleep.h"
#include "sleep_gate.h"
#include "usage_freshness.h"
#include "ui_settings.h"
#include "ui_anim.h"
#include "tz_fetch.h"
#include "ota.h"
#include "upd_tap.h"
#include "whatsnew.h"
#include "ui_touchfx.h"
#include "version.h"

static const struct device *const display_dev = DEVICE_DT_GET(DT_CHOSEN(zephyr_display));

/*
 * MADCTL correction for the production batch.
 *
 * These panels differ from the pilot units in two independent ways, and both
 * land in MADCTL (36h), so one write fixes both. Pilot boards must build with
 * CONFIG_OVERWATCH_PANEL_PILOT, which compiles this away entirely.
 *
 * The pilot units and the production panels are driven with byte-identical
 * registers, yet production renders mirrored -- so the difference is in the
 * module, not in anything we send. The usual cure for that, the SS bit in
 * DISCTRL (B6h), was tried on hardware 2026-08-21: the built devicetree
 * carried it (disctrl = [0a a2 27 04]) and the image did not budge, which
 * rules the B6h route out on this controller. MADCTL is honoured, so the
 * compensation lives there instead.
 *
 * It cannot be a devicetree `rotation`. The ili9xxx driver's CMD_SET_1 table
 * reaches only MV (90 deg) and MV|MX|MY (270 deg) in landscape, and those two
 * differ by a pure 180 deg turn -- neither un-mirrors. What this panel needs is
 * MV|MY, which no rotation value can produce. So we re-issue MADCTL ourselves
 * once, straight onto the DBI bus, after the driver has finished its init.
 *
 * Second, the colour order. The driver hardcodes the BGR bit for every
 * orientation, but these panels are wired RGB, so red and blue arrived
 * swapped. Measured 2026-08-21 with a six-bar test pattern of known values:
 * the RED bar read blue and the BLUE bar read red, while GREEN stayed green
 * and white/black were exact -- a clean channel exchange, with no inversion
 * or gamma error. Clearing bit 3 restores it. (Green surviving a red/blue
 * swap untouched is why eyeballing a green UI element misdiagnosed this.)
 *
 * Safe to overwrite: the driver writes MADCTL only from set_orientation(),
 * which runs during init and is never called again (nothing in the LVGL glue
 * touches orientation), so this value is the one that sticks. Partial updates
 * stay correct because MY flips the row-address mapping wholesale -- LVGL's
 * window coordinates and its pixels mirror together, and the panel's own
 * reversed wiring cancels them back out.
 */
#ifdef CONFIG_OVERWATCH_PANEL_PILOT

/* Pilot panels need none of it: the stock rotation=90 MADCTL (BGR|MV) that the
 * driver writes is already correct for them, mirror and colour order alike. */
static void panel_fix_madctl(void)
{
}

#else

#define PANEL_MADCTL_MV   BIT(5)
#define PANEL_MADCTL_MY   BIT(7)

static const struct device *const panel_dbi =
	DEVICE_DT_GET(DT_PARENT(DT_NODELABEL(ili9341)));
static const struct mipi_dbi_config panel_dbi_cfg =
	MIPI_DBI_CONFIG_DT(DT_NODELABEL(ili9341),
			   SPI_OP_MODE_MASTER | SPI_WORD_SET(8), 0);

static void panel_fix_madctl(void)
{
	uint8_t madctl = PANEL_MADCTL_MV | PANEL_MADCTL_MY;	/* BGR bit clear = RGB */
	int r;

	if (!device_is_ready(panel_dbi)) {
		printk("[usage] panel: DBI bus not ready, MADCTL uncorrected\n");
		return;
	}

	r = mipi_dbi_command_write(panel_dbi, &panel_dbi_cfg, 0x36, &madctl, 1);
	if (r < 0) {
		printk("[usage] panel: MADCTL write failed (%d)\n", r);
	} else {
		printk("[usage] panel: MADCTL=0x%02x\n", madctl);
	}
}

#endif /* CONFIG_OVERWATCH_PANEL_PILOT */

/*
 * Rebuild the gauge screen because the theme changed.
 *
 * A switch is a rebuild rather than a restyle: LVGL keeps no back-reference
 * from a styled object to the value it was given, so repainting in place would
 * mean walking every object and knowing which role each colour played. Getting
 * one wrong leaves a single unreadable label that nobody finds until a
 * customer does. This path already exists for mode changes and is known to
 * work; the theme borrows it.
 *
 * Run from the mode loop, never from an LVGL event: it deletes the screen the
 * event is being dispatched on.
 */
static void theme_rebuild(void)
{
	if (!ui_theme_rebuild_pending()) {
		return;
	}
	ui_theme_rebuild_clear();
	usage_view_deinit();
	ui_pages_detach();
	usage_view_init();
	ui_pages_init(lv_scr_act());
	ui_settings_attach(lv_scr_act());
}

#if IS_ENABLED(CONFIG_OVERWATCH_WIFI_MODE)
/*
 * Everything from here to the matching #endif belongs to the standalone WiFi
 * flow -- provisioning, the setup AP, the sign-in exchange, the blind-radio
 * retry. Every use of it is already inside the gate further down; only these
 * declarations sat outside, which made a USB-only build emit six
 * "defined but not used" warnings and hid anything genuine among them.
 */
/* Provisioning session state (one PKCE verifier per setup attempt). */
static char verifier[OAUTH_VERIFIER_LEN];
static char authorize_url[OAUTH_URL_LEN];

/*
 * The setup AP's WPA2 password: random once, persisted, carried by the QR.
 * Random rather than MAC-derived on purpose -- the MAC's vendor bytes are
 * guessable and its tail is broadcast in the SSID, so a derived password
 * would protect nothing. Factory reset clears it; the next boot rolls a
 * fresh one here.
 */
static void ap_psk_setup(void)
{
	/* No 0/O/1/l/I look-alikes: the password is only ever read by a
	 * camera, but a human may need to type it once if the QR scan is
	 * refused. */
	static const char alphabet[] = "abcdefghjkmnpqrstuvwxyz23456789";
	char psk[CFG_AP_PSK_MAX];

	if (!cfg_get_ap_psk(psk, sizeof(psk))) {
		uint8_t rnd[10];

		sys_rand_get(rnd, sizeof(rnd));
		for (int i = 0; i < 10; i++) {
			psk[i] = alphabet[rnd[i] % (sizeof(alphabet) - 1)];
		}
		psk[10] = '\0';
		cfg_set_ap_psk(psk);
	}
	net_wifi_set_ap_psk(psk);
}

/*
 * The radio sometimes comes out of a reset blind: every scan returns nothing
 * and joins time out, for that entire boot; another reboot re-rolls it
 * (observed on this hardware 2026-07-13, roughly every other soft reset).
 * These counters live in .noinit RAM so they survive the reboot the retry
 * depends on; the magic guards against power-on garbage.
 */
static __noinit uint32_t blind_boots;
static __noinit uint32_t blind_magic;
#define BLIND_MAGIC 0xb11dbea7u
#define BLIND_MAX 4

/* The boot scan could not see the stored SSID. The join still runs -- scans
 * miss hidden SSIDs and barely-beaconing phone hotspots (an iPhone hotspot
 * with a fresh token got bounced to setup this way, 2026-07-15) -- this
 * flag only picks the honest reason to show on the setup form if that
 * join fails too. */
static bool scan_said_absent;
#endif /* CONFIG_OVERWATCH_WIFI_MODE */

/* ---- OTA boot-side: test-boot self-confirm, else MCUboot reverts ---- */

static bool ota_test_boot;
static bool ota_health;		/* mode proved WiFi + TLS + usage (or daemon) */
static int64_t ota_confirm_deadline;
static const struct device *wdt;
static int wdt_chan = -1;

static void ota_boot_begin(void)
{
	if (boot_is_img_confirmed()) {
		return;
	}
	ota_test_boot = true;
	ota_confirm_deadline = k_uptime_get() + 90 * 1000;
	printk("[ota] test boot of %s -- must confirm within 90 s\n",
	       OVERWATCH_FW_VERSION);

	/* Hardware watchdog for hard hangs: a wedged main loop stops feeding,
	 * the chip resets, and MCUboot reverts the unconfirmed image. */
	wdt = DEVICE_DT_GET_OR_NULL(DT_ALIAS(watchdog0));
	if (wdt && device_is_ready(wdt)) {
		struct wdt_timeout_cfg cfg = {
			.window.max = 30000,
			.flags = WDT_FLAG_RESET_SOC,
		};

		wdt_chan = wdt_install_timeout(wdt, &cfg);
		if (wdt_chan >= 0) {
			wdt_setup(wdt, 0);
		}
	}
}

static void ota_boot_pump(void)
{
	if (!ota_test_boot) {
		return;
	}
	if (wdt_chan >= 0) {
		wdt_feed(wdt, wdt_chan);	/* alive != healthy; deadline judges health */
	}
	if (ota_health) {
		boot_write_img_confirmed();
		ota_test_boot = false;
		if (wdt_chan >= 0) {
			wdt_disable(wdt);
			wdt_chan = -1;
		}
		printk("[ota] image confirmed\n");
		return;
	}
	if (k_uptime_get() > ota_confirm_deadline) {
		printk("[ota] not healthy within 90 s -- rebooting to revert\n");
		ui_boot_mark_intentional_reboot();
		sys_reboot(SYS_REBOOT_COLD);
	}
}

/*
 * "Do not close this board's eyes right now", in one place.
 *
 * There were two hand-written copies of this condition and they had already
 * drifted: the doze in run_usb() carried ota_test_boot, and
 * reading_moved_again() -- whose own comment calls it the mirror of that
 * doze -- did not. The drift is unreachable today, because ota_test_boot is
 * raised once in ota_boot_begin() before any mode loop exists and from then
 * on only ever falls. But it is exactly the term whose absence cost a board
 * on the bench (2026-09-03): dozing blocks the loop that feeds the 30 s
 * watchdog an unconfirmed image arms, the SoC resets, MCUboot re-runs the
 * same unconfirmed image, and it dozes again at 60 s -- forever. A condition
 * that has to be right in two files to keep a board out of a reset loop
 * should exist once.
 *
 * "An update is in flight" honestly covers "the new image has not proved
 * itself yet", which is why the test boot rides this term instead of
 * becoming a fourth condition at each call site; staying awake is also what
 * lets the deliberate revert at the 90 s deadline happen, logged, rather
 * than as a bare watchdog reset nobody can read afterwards.
 *
 * Read fresh on every call, never cached: an update that starts while the
 * board is already dozing has to put the progress screen back up.
 */
static bool ota_blocks_sleep(void)
{
	struct ota_ui snap;

	ota_ui_get(&snap);
	return snap.st == OTA_UI_DOWNLOADING || snap.st == OTA_UI_REBOOTING ||
	       ota_test_boot;
}

/* Did the previous boot's install land? Runs once the gauge screen exists so
 * the notice popup has somewhere to live. */
static void ota_report_outcome(void)
{
	char trail[CFG_OTA_VER_MAX];
	char from[CFG_OTA_VER_MAX], to[CFG_OTA_VER_MAX];
	char summary[WHATSNEW_SUMMARY_MAX];

	if (cfg_get_ota_state(trail, sizeof(trail)) != 1) {
		return;
	}
	cfg_set_ota_state(0, "");
	/* Through whatsnew_split, always: the breadcrumb may be a packed
	 * pair, and comparing "1.2.5>1.3.2" against OVERWATCH_FW_VERSION would
	 * announce a successful update as a failed one. */
	whatsnew_split(trail, from, sizeof(from), to, sizeof(to));
	/*
	 * The board's own verdict on the update, in the console log.
	 *
	 * It had none. The daemon logs that it flashed an image and the panel
	 * puts up a popup that is gone as soon as anyone taps OK, so the one
	 * question support actually asks after a failed update -- did the
	 * board come up on the version it was aiming at -- had no answer
	 * anywhere afterwards.
	 *
	 * It also makes this decision observable on a bench. That matters
	 * more than it looks: reading the breadcrumb wrongly reports a
	 * SUCCESSFUL update as a failure, silently, and the popup it puts up
	 * is the only other evidence.
	 */
	printk("[ota] update %s: wanted %s, running %s (from %s)\n",
	       strcmp(to, OVERWATCH_FW_VERSION) == 0 ? "landed" : "REVERTED",
	       to, OVERWATCH_FW_VERSION, from[0] ? from : "?");
	if (strcmp(to, OVERWATCH_FW_VERSION) == 0) {
		/*
		 * The notice says how much changed; the screen behind it says
		 * what. An empty summary means this release has no entry in
		 * the table, and then the notice shows the tick and the
		 * version alone rather than offering a screen with nothing
		 * on it.
		 */
		whatsnew_summary(from, OVERWATCH_FW_VERSION, summary,
				 sizeof(summary));
		ui_settings_notice_update(OVERWATCH_FW_VERSION, summary, from,
					  OVERWATCH_FW_VERSION);
	} else {
		ui_settings_notice("Update failed, previous version restored.");
	}
}

#if IS_ENABLED(CONFIG_OVERWATCH_WIFI_MODE)
/* Everything from here to usb_anim_pump() is the board's own network path:
 * the captive portal, the sign-in, the scan. Whole functions, so this is a
 * region rather than a sprinkle -- see firmware/Kconfig. */
static void pump_ui(void)
{
	ui_setup_service();
	ota_boot_pump();
	lv_timer_handler();
}

/* Called from portal_run's idle wait: keep the setup screen alive. */
void portal_idle_hook(void)
{
	pump_ui();
}

/* Same job during net_wifi's blocking waits (scan/join/DHCP/AP-up): keep
 * whatever screen is up animating. */
static void wifi_idle(void)
{
	/* Feed the boot watchdog here too. This hook is what net_wifi pumps
	 * through scan, association and DHCP -- up to ~66 s on a failed join,
	 * against a 30 s window -- and it fed nothing, so the watchdog reset a
	 * perfectly healthy board and MCUboot reverted a good image: the exact
	 * opposite of its job. Fed from the loops themselves rather than a
	 * k_timer on purpose: a timer would keep feeding from ISR context even
	 * with the main thread wedged, which is the hang this is here to catch.
	 */
	ota_boot_pump();
	lv_timer_handler();
}

/*
 * Radio settle before the first join of a boot. The pre-redesign flow never
 * joined before ~12 s of uptime (8 s sniff + selection screen) and connected
 * every time; the detection flow's ~3 s join failed with a mid-handshake
 * disconnect on every boot tried (2026-07-14). The driver evidently needs
 * runway after init. Keeps the UI pumping so the spinner stays alive.
 */
static void wifi_settle(void)
{
	for (int i = 0; i < 500; i++) {	/* 5 s */
		ota_boot_pump();	/* 5 s of the 30 s window; see wifi_idle */
		lv_timer_handler();
		k_sleep(K_MSEC(10));
	}
}

/*
 * The one background thread. Used serially, never concurrently: the sign-in
 * exchange during provisioning, or standalone mode's network loop -- a boot
 * does one or the other. Lower priority than main (higher number): 1-2 s of
 * ECDHE math must not starve the render loop on this single-core build.
 */
#define NET_WORKER_PRIO 5
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
int main(void)
{
	printk("[usage] firmware boot OK\n");

	/* Route mbedTLS at the kernel heap. prj.conf sets MBEDTLS_ENABLE_HEAP=n
	 * so no static _mbedtls_heap is reserved: TLS and WiFi now share
	 * HEAP_MEM_POOL_SIZE, which is sized for the larger of the two peaks
	 * instead of their sum (they never overlap -- the SoftAP is down
	 * whenever OTA runs, and TLS is idle during provisioning). That is what
	 * frees enough DRAM for the 16 KB inbound record buffer the release
	 * CDN's full-size records require.
	 *
	 * MUST happen before any TLS use: without it mbedTLS falls back to libc
	 * calloc, and picolibc's heap here is ~5 KB, so every handshake would
	 * fail. k_calloc/k_free match mbedTLS's expected signatures exactly. */
	if (mbedtls_platform_set_calloc_free(k_calloc, k_free) != 0) {
		printk("[usage] FATAL: mbedTLS allocator hookup failed\n");
		return -1;
	}

	if (!device_is_ready(display_dev)) {
		printk("[usage] display not ready\n");
		return -1;
	}
	panel_fix_madctl();
	display_blanking_off(display_dev);
	ui_touchfx_init();	/* light touch-echo feedback on every press */

	cfg_init();
	/* Straight after cfg_init, because it reads from it and because every
	 * screen built below asks ui_theme() for its colours. */
	ui_theme_init();
	ota_boot_begin();	/* unconfirmed image? start the confirm clock */
	/* ...and from here the boot screen's own wait loops feed it too; they
	 * block for seconds against a 30 s window. */
	ui_boot_set_pump(ota_boot_pump);
	backlight_init();	/* drive the PWM to the persisted level */
#if IS_ENABLED(CONFIG_OVERWATCH_WIFI_MODE)
	net_wifi_init();
	net_wifi_set_idle_hook(wifi_idle);
	ap_psk_setup();		/* before any QR or AP use */
#else
	/* Nothing in this build can use a refresh token -- the OAuth code is
	 * not compiled in. But a unit flashed with a WiFi build still has one
	 * in NVS, and unfused flash is readable over USB with esptool, so
	 * compiling the writer out does not make the customer's token go
	 * away. Erase it on the first boot that cannot use it. */
	{
		char tok[CFG_TOKEN_MAX];

		if (cfg_get_token(tok, sizeof(tok))) {
			cfg_clear_token();
			printk("[usage] cleared a stored refresh token: no WiFi in this build\n");
		}
	}
#endif

#ifdef TEST_SCREEN
	ui_setup_show();
	for (;;) {
		const struct { enum ui_setup_state s; const char *d; } seq[] = {
			{ UI_SETUP_WAIT, NULL }, { UI_SETUP_PHONE, NULL },
			{ UI_SETUP_WIFI_OK, NULL }, { UI_SETUP_SIGNIN, NULL },
			{ UI_SETUP_DONE, NULL },
		};
		for (int i = 0; i < 5; i++) {
			ui_setup_set_state(seq[i].s, seq[i].d);
			for (int t = 0; t < 250; t++) { pump_ui(); k_sleep(K_MSEC(10)); }
		}
	}
#endif

	/* proto first: its hello goes out now, so a daemon's reply is already
	 * in flight during the splash and the selection can short-circuit. */
	proto_init();

	/* A mid-provisioning reboot (WiFi stored, token not yet) has exactly
	 * one destination: the setup flow. Route it straight there -- even
	 * the brief splash-colored interstitial between setup screens read
	 * as dead time on hardware (user feedback 2026-07-16). A PC daemon
	 * never loses the board to this shortcut: the daemon opening the
	 * port is a hard reset, which clears the intentional mark. */
#if IS_ENABLED(CONFIG_OVERWATCH_WIFI_MODE)
	if (ui_boot_intentional_pending()) {
		char ssid[CFG_SSID_MAX], psk[CFG_PSK_MAX], tok[CFG_TOKEN_MAX];

		if (cfg_get_wifi(ssid, sizeof(ssid), psk, sizeof(psk)) &&
		    !cfg_get_token(tok, sizeof(tok))) {
			printk("[usage] mode: provisioning (resume, no splash)\n");
			run_provisioning(NULL);	/* reboots when done */
		}
	}
#endif

	ui_boot_splash();

	/* Detection, not a menu. First match wins: a talking daemon, then a
	 * reachable home network, then setup. Plugging into a PC later still
	 * works -- the daemon opening the port resets this board, so it always
	 * announces itself into a fresh splash. */
	if (proto_host_seen()) {
		printk("[usage] mode: USB bridge\n");
		usage_view_init();
		ui_pages_init(lv_scr_act());
		/* Same CONNECTING bar as standalone (user request
		 * 2026-07-16); the link step is already done -- the daemon
		 * spoke during the splash. */
		usage_view_boot_begin(usb_boot_steps, 2);
		usage_view_boot_stage(1);
		lv_timer_handler();
		ui_boot_teardown();	/* only after the new screen is loaded */
		ui_settings_attach(lv_scr_act());
		ota_report_outcome();
		usage_view_set_status(USAGE_STATUS_DISCONNECTED);
		proto_resync();		/* daemon re-pushes time+usage right away */
		run_usb();
	}

#if IS_ENABLED(CONFIG_OVERWATCH_WIFI_MODE)
	char tok[CFG_TOKEN_MAX], ssid[CFG_SSID_MAX], psk[CFG_PSK_MAX];
	bool have_wifi = cfg_get_wifi(ssid, sizeof(ssid), psk, sizeof(psk));
	bool have_tok = cfg_get_token(tok, sizeof(tok));

	if (have_wifi && have_tok) {
		/* Take over the screen BEFORE the scan: a setup-flow reboot
		 * should land on the progress UI immediately instead of
		 * holding the splash color for the scan's 1-2 s (user
		 * feedback 2026-07-16). The scan runs under the boot bar. */
		usage_view_init();
		ui_pages_init(lv_scr_act());
		/* Step list before the first frame: one rendered frame of a
		 * wrong takeover flashes visibly on this panel
		 * (user-reported 2026-07-15). */
		usage_view_boot_begin(wifi_boot_steps, 3);
		lv_timer_handler();
		ui_boot_teardown();
		ui_settings_attach(lv_scr_act());
		ota_report_outcome();

		switch (boot_ssid_scan(ssid)) {	/* may reboot (blind radio) */
		case SSID_VISIBLE:
			printk("[usage] mode: standalone WiFi\n");
			run_standalone();
			break;			/* unreachable */
		case SSID_ABSENT:
			/* Not in the scan -- but hidden SSIDs and phone
			 * hotspots rarely are. The join is the authority;
			 * the flag makes its failure decisive. */
			printk("[usage] mode: standalone WiFi (\"%s\" not in scan; probing)\n",
			       ssid);
			scan_said_absent = true;
			run_standalone();
			break;			/* unreachable */
		case SSID_RADIO_BLIND:
			printk("[usage] mode: provisioning (radio blind)\n");
			run_provisioning("no networks found; check antenna or power");
			break;			/* unreachable */
		}
	}

	printk("[usage] mode: provisioning\n");
	run_provisioning(NULL);	/* reboots when done */
#else
	/*
	 * No radio in this build, so there is nothing to fall through TO. The
	 * detection above had three destinations; this one has one, and
	 * run_usb() already owns the case it lands in: it shows the
	 * waiting-for-host step and times out on its own if no daemon ever
	 * speaks. Deliberately no proto_resync() here -- that exists to make a
	 * daemon that already said hello re-push, and by definition none has.
	 */
	printk("[usage] mode: USB bridge (no host yet)\n");
	usage_view_init();
	ui_pages_init(lv_scr_act());
	usage_view_boot_begin(usb_boot_steps, 2);
	lv_timer_handler();
	ui_boot_teardown();
	ui_settings_attach(lv_scr_act());
	ota_report_outcome();
	usage_view_set_status(USAGE_STATUS_DISCONNECTED);
	run_usb();
#endif
	return 0;
}

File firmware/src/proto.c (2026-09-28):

#include <zephyr/kernel.h>
#include <zephyr/device.h>
#include <zephyr/drivers/uart.h>
#include <zephyr/drivers/hwinfo.h>
#include <zephyr/sys/printk.h>
#include <zephyr/sys/ring_buffer.h>
#include <stdio.h>
#include <string.h>

#include "proto.h"
#include "msg_parse.h"
#include "ui_launcher.h"
#include "ui_panel.h"
#include "ui_music.h"
#include "ota.h"
#include "version.h"
#include "cfg_store.h"
#include "whatsnew.h"
#include "usage_view.h"
#include "usage_state.h"
#include "usage_freshness.h"
#include "net_time.h"
#include "version.h"
#include "cfg_store.h"

#define PROTO_VERSION OVERWATCH_PROTO_VERSION
#define PING_INTERVAL_MS 10000
/*
 * The daemon answers every ping with a pong, so silence means it is genuinely
 * gone -- not merely between its 60 s usage polls. Three missed pings (10 s
 * apart) is enough to be sure without being twitchy about one dropped line.
 */
/* Three missed pongs (the board pings every 10 s). Past this a host that
 * has not said goodbye is taken to be asleep -- see proto_host_lost(). */
#define HOST_TIMEOUT_MS 30000
#define LINE_MAX 512
#define RX_RING_SIZE 1024

static const struct device *const console_dev =
	DEVICE_DT_GET(DT_CHOSEN(zephyr_console));

static char line[LINE_MAX];
static size_t line_len;

/*
 * A number off the wire, or the default it arrived with, and never a value
 * outside the range the field can mean.
 *
 * strtod happily returns nan, inf and 1e300, and every one of those was cast
 * straight to an int -- undefined behaviour in C, and on this soft-float
 * target a saturated or arbitrary integer on the panel. The `time` handler
 * has always bounded its two fields; the usage fields did not. Anything that
 * is not a real number in range leaves the default in place, which every
 * field here defines as "unknown" or "none".
 */
#define SECS_MAX 2147483647.0
/*
 * Percentages can legitimately exceed 100: extra usage carries a weekly window
 * past its limit. The ceiling used to be 100, and num() does not clamp -- it
 * refuses -- so 102 left the caller's `double wp = 0` untouched and the panel
 * drew an empty ring at the moment the user went over. Accept the real number
 * and let usage_view saturate the ring.
 */
#define PCT_MAX 1000.0

static void num(const char *json, const char *key, double *out,
		double lo, double hi)
{
	double v;

	if (!msg_get_double(json, key, &v)) {
		return;
	}
	if (v != v || v < lo || v > hi) { /* nan, or out of range */
		return;
	}
	*out = v;
}
static int64_t last_ping_ms;
static int64_t last_host_ms;
static bool host_seen;
static bool host_bye;		/* the app said it is going, on purpose */
static bool host_lost;		/* silence past the timeout, without a bye */
static char host_ver[16];	/* the daemon's release version, from welcome */
/*
 * The daemon's pairing token, from welcome, for the setup QR.
 *
 * 33 because the token is 32 hex characters. Sized exactly rather than
 * generously: a longer one is a daemon this firmware does not understand,
 * and truncating it into a QR would produce a code that scans perfectly and
 * pairs with nothing -- which is worse than no QR at all. msg_get_str
 * refuses rather than truncates, so an oversized token leaves this empty and
 * the board falls back to the plain setup URL.
 */
static char pair_tok[33];
static int host_proto;		/* ...and the protocol it speaks */

/*
 * RX is interrupt-driven, not polled. On a real UART at 115200 baud the 128-byte
 * hardware FIFO holds only ~11 ms of traffic, so any main-loop stall longer than
 * that (an LVGL frame, a TLS handshake) would silently truncate an inbound line.
 * The ISR drains the FIFO into this ring buffer; proto_service() consumes it at
 * whatever pace the main loop happens to run.
 */
RING_BUF_DECLARE(rx_ring, RX_RING_SIZE);
static uint32_t rx_dropped;

static void uart_isr(const struct device *dev, void *user_data)
{
	ARG_UNUSED(user_data);

	if (!uart_irq_update(dev)) {
		return;
	}

	while (uart_irq_rx_ready(dev)) {
		uint8_t buf[64];
		int n = uart_fifo_read(dev, buf, sizeof(buf));

		if (n <= 0) {
			break;
		}
		if (ring_buf_put(&rx_ring, buf, n) < (uint32_t)n) {
			rx_dropped++;
		}
	}
}

static void emit(const char *json)
{
	/* JSON lines go to the same console UART; '\n'-terminated. */
	printk("%s\n", json);
}

void proto_send_pref(void)
{
	char buf[64];

	snprintf(buf, sizeof(buf),
		 "{\"t\":\"pref\",\"v\":%d,\"provider\":\"%s\"}",
		 PROTO_VERSION,
		 cfg_get_main_src() == CFG_MAIN_SRC_CODEX ? "codex" : "claude");
	emit(buf);
}

void proto_send_launch(int slot)
{
	char buf[64];

	/*
	 * A slot number, never an app name or a path.
	 *
	 * The computer owns the list of what is launchable and the board is
	 * told only what to draw on the buttons, so nothing the board can say
	 * names a program. That keeps this message incapable of asking the
	 * host to run something the host has not already agreed to run -- the
	 * board is an index into the daemon's own table, not a command line.
	 *
	 * It is also 30 bytes against the 512 the line budget allows
	 * (pc/protocol.py MAX_LINE_BYTES), where a path would be unbounded.
	 */
	snprintf(buf, sizeof(buf), "{\"t\":\"launch\",\"v\":%d,\"slot\":%d}",
		 PROTO_VERSION, slot);
	emit(buf);
}

void proto_send_panel_tap(int panel, int tile)
{
	char buf[64];

	snprintf(buf, sizeof(buf),
		 "{\"t\":\"panel_tap\",\"v\":%d,\"p\":%d,\"i\":%d}",
		 PROTO_VERSION, panel, tile);
	emit(buf);
}

void proto_send_music(const char *cmd)
{
	char buf[64];

	/* Whitelisted here rather than trusted from the caller. The callers
	 * are three lv_event user_data pointers in ui_music.c today, and
	 * the check costs nothing next to a fourth one arriving later with a
	 * typo that reaches the customer's Mac as an unknown verb. */
	if (strcmp(cmd, "play") != 0 && strcmp(cmd, "prev") != 0 &&
	    strcmp(cmd, "next") != 0) {
		return;
	}
	snprintf(buf, sizeof(buf), "{\"t\":\"music\",\"v\":%d,\"cmd\":\"%s\"}",
		 PROTO_VERSION, cmd);
	emit(buf);
}

static void send_hello(void)
{
	uint8_t id[16];
	char idhex[33] = "unknown";
	ssize_t n = hwinfo_get_device_id(id, sizeof(id));

	if (n > 0) {
		for (ssize_t i = 0; i < n && i < 16; i++) {
			snprintf(idhex + i * 2, 3, "%02x", id[i]);
		}
	}

	uint32_t cause = 0;
	(void)hwinfo_get_reset_cause(&cause);

	char buf[160];
	snprintf(buf, sizeof(buf),
		 "{\"t\":\"hello\",\"v\":%d,\"board\":\"cyd\","
		 "\"board_id\":\"%s\",\"fw\":\"" OVERWATCH_FW_VERSION "\","
		 "\"reset\":\"0x%x\"}",
		 PROTO_VERSION, idhex, cause);
	emit(buf);
	/* Straight after hello: a daemon that starts later, or restarts, has
	 * no other way to learn a preference the user set while it was gone. */
	proto_send_pref();
}

static void send_ping(void)
{
	char buf[64];
	snprintf(buf, sizeof(buf), "{\"t\":\"ping\",\"v\":%d,\"up_ms\":%lld}",
		 PROTO_VERSION, (long long)k_uptime_get());
	emit(buf);
}
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

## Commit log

2026-07-14 CYD: restore typed-SSID field -- empty scans are bimodal, dropdown alone dead-ends
    Observed on hardware: some reboots scan 0 networks on all three retries
    while others find everything instantly. A typed name overrides the
    dropdown and also covers hidden SSIDs.
    [portal.c]
2026-07-14 Revert "CYD: restore typed-SSID field -- empty scans are bimodal, dropdown alone dead-ends"
    This reverts commit 0a48fa58e248acf176b8c9a0756d007e6f4d035e.
    [portal.c]
2026-07-14 CYD: fix DNS-thread teardown race (crash on retry path); reboot blind-radio boots
    dns_hijack_stop returned while its thread could still be wedged in a
    blocking sendto; the next start re-created the thread over the live one,
    corrupting kernel wait queues -- net RX thread faulted in k_condvar_signal
    (backtrace captured on hardware). stop now joins (abort as last resort)
    and the socket gets a send timeout.
    Boots whose scans all return empty also cannot join (radio blind until
    reset); reboot to re-roll, bounded via .noinit counters.
    [main.c]
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2026-07-14 CYD: join only from a clean boot -- post-AP joins never complete on this driver
    Phase 1 now persists credentials and reboots; the resume path (the one
    join sequence proven on hardware) does the connect. Wrong passwords
    self-correct: the boot join fails and phase 1 returns with the reason.
    [main.c]
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2026-07-14 CYD: WiFi mode wore USB-mode waiting text; log tz reply on parse failure
    Seen on hardware: standalone boot showed WAITING FOR HOST / start the
    bridge daemon -- wrong story when the board is joining WiFi. The takeover
    text is now settable per mode. The tz fetch also failed its first live
    run with a message that could not say why; the failure path now logs the
    byte count and reply head (public data).
    [main.c]
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2026-07-15 CYD: boot detects its mode instead of asking; touch axes un-swapped
    The selection screen died on contact with hardware twice over: its touch
    mapping was diagonal-mirrored (tapping WiFi pressed USB -- the overlay's
    swap-xy came from a CYD-T4 measurement that this unit's corner taps
    contradict), and even fixed it was a 10 s toll booth on every boot. Boot now
    detects: daemon talking during the splash -> USB (a late daemon still wins,
    since opening the port resets the board); stored SSID visible in a scan ->
    standalone; otherwise the portal, with the doomed-join case skipped and the
    reason on the form. Empty scans reuse the blind-radio reboot re-roll --
    absence of evidence is not evidence of abs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
    [main.c]
2026-07-15 CYD: the join IS the network probe -- this unit's scans miss real networks
    First live run of the scan gate sent a working device to the portal: 4
    networks found, the one it joins daily not among them (hidden SSIDs never
    scan, and this radio misses more). So no scan before standalone: try the
    join, retry a failure through the clean-boot reboot the driver demands, and
    only a 3-streak (noinit counter) concludes the network is really gone and
    opens the portal with the reason.
    [main.c]
2026-07-15 CYD: 5s radio settle before first join; log connect/disconnect reasons
    Joins fired ~3s after boot failed every time tonight while ~12s joins
    succeeded this morning, so the settle runway stays (cheap insurance even
    though tonight's failures turned out network-side: scans stopped showing
    the stored SSID and associations die with no reason code -- the driver
    reports disconn_reason -1 and never delivers CONNECT_RESULT).
    [main.c]
2026-07-15 CYD: restore the scan gate -- its 'failure' was the device moving homes
    The scan was right all along: it reported the SSID absent minutes after the
    device moved (2026-07-14), and misreading that as a scan defect bought a
    move-cost of three failed-join boot cycles before the portal. Scan first
    again: absent-from-a-populated-scan -> portal in seconds with the reason on
    the form; the join-strike backstop stays for scans that say yes wrongly;
    blind scans still re-roll the radio. Hidden SSIDs remain the known limit.
    [main.c]
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2026-07-15 CYD: token-holders' ack page stops promising a sign-in; tz logs IP + errno
    Re-provisioning at a new home worked exactly as designed (stored token ->
    straight to gauges after the join) but the ack page still narrated the
    fresh-device flow, promising a sign-in QR that never comes -- a healthy
    resume read as a malfunction. The page now says what will actually happen.
    tz_fetch also gets two more diagnostics: the resolved A record and the recv
    errno, to split port-80-filtered from DNS-poisoned from reset -- its reply
    was 0 bytes on two different networks while TLS worked on both.
    [main.c, portal.c]
2026-07-15 CYD: the provisioning phone supplies the timezone -- hotel WiFi eats port 80
    Root cause of the clock never appearing in WiFi mode, pinned by three
    diagnostics: DNS correct, TCP connects, then zero bytes ever return (errno
    11) -- while the same request from an already-authorized laptop on the SAME
    network answers instantly. Captive-style networks black-hole plain HTTP
    from clients that never clicked their terms page; a headless board never
    can. So the setup form now submits the phone browser's UTC offset (hidden
    field) and it persists to NVS beside the credentials -- you re-provision
    exactly when you change timezones, and the phone always knows. The ip-api
    fetch stays as a best-effort daily D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
    [main.c, portal.c]
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2026-07-15 CYD: scan hints, the join decides; 20s TLS connect budget for hotspots
    Two field lessons from one hotel evening. (1) The OAuth exchange timed out
    (-116, twice) over an iPhone hotspot inside the default 3 s socket connect
    budget -- cellular RTT plus a ~6 KB cert flight in 536-byte segments plus
    ECDHE on this CPU need more room; hotel WiFi passed the same exchange by
    luck of a shorter RTT. (2) The same hotspot then never appeared in the boot
    scan (phone hotspots barely beacon) and a freshly signed-in device bounced
    to setup. Scan-absent now still probes with one join; only invisible AND
    unjoinable -- two independent signals -- goes to the portal, immediately.
    [main.c]
2026-07-15 CYD: settle before the standalone join; one retry boot on scan-absent joins
    The only hotspot joins that completed tonight ran behind the 5s settle in
    the provisioning path; the standalone probe join skipped it and dropped
    mid-association. And for barely-beaconing hotspots scan-absent is chronic,
    so absent+one-flake meant a full re-setup -- give it one retry boot first.
    [main.c]
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2026-07-16 CYD: net worker thread + 32K LVGL pool in dram1 + boot bar + setup fixes
    The day's hardware findings, verified live piece by piece:
    - LVGL pool 16K->32K, relocated to dram1's noinit region (dram0 is
    full): gauge screen + settings overlay + confirm dialog exhausted 16K
    and lv_draw_add_task NULL-derefed -- the 'stuck' re-sign-in was this
    crash. Input queues 16/10 -> 64/64: releases dropped during TLS
    stalls made buttons flaky.
    - All standalone networking (SNTP, OAuth, usage poll, tz) moved off the
    UI thread onto a worker posting events through a msgq; spinners no
    longer freeze and touch stays live during fetches. cfg_store gets a
    mutex and net_time a spinlock for the new cross-t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
    [main.c]
2026-07-16 CYD+pc: review-debt cleanup -- SSID HTML-escape, tz status check, CSS %s, settings polish
    - portal: HTML-escape SSIDs before they enter pages (scanned neighbor
    names are radio input -- anyone can broadcast '<script>' as an SSID);
    CSS now rides into snprintf as a %s argument instead of living inside
    the format string, where its literal '%' was an unknown conversion
    (undefined behavior that happened to render, and eight -Wformat
    warnings); header comment caught up with reality (two-phase serving,
    one line of tz-harvesting JS).
    - tz_fetch: reject non-200 replies before grepping the body -- a captive
    portal's error page must not be parsed for a timezone.
    - settings: confirm button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
    [portal.c, ui_settings.c]
2026-07-16 CYD: announce the final setup reboot with a toast
    'Setup complete / Restarting now...' for 3 s (screen kept alive) before
    the post-provisioning reboot; 'Setup finished' variant on the timeout
    path. Third instance of the same lesson: every silent self-restart on
    this device has been read as a crash.
    [main.c]
2026-07-16 CYD: intentional reboots skip the splash animation
    A noinit flag (magic-guarded) set before every on-purpose sys_reboot --
    reboot-to-join, post-setup, blind-radio re-roll, token-refresh failure,
    settings actions. The next boot renders the same splash screen static
    (title at full opacity, no spinner) with a 0.3 s daemon-detect window
    instead of the 2.5 s show, so mid-flow restarts stop feeling like fresh
    power-ons. Power-on and crash resets still animate.
    [main.c, ui_settings.c]
2026-07-16 CYD: answer POST /token instantly, run the exchange after
    Holding the phone's POST open through the 15-25 s TLS exchange is the
    response that kept dying (spinner forever, user-reported twice). The
    POST now gets an immediate 'Signing in on the device...' page; the
    exchange runs after the socket closes, and every open page -- the
    submitter included -- learns the outcome from /status ('done' -> /done,
    'fail' -> back to the form; the form ignores 'fail' so a stale flag
    cannot loop). Listen backlog 2 -> 4 for the polls that stack up while
    the exchange blocks the server.
    [portal.c]
2026-07-16 CYD: run the token exchange on the worker so the portal never goes deaf
    The sign-in server is single-threaded; with the 15-25 s exchange run
    inline it answered nothing mid-sign-in -- /status polls piled into the
    backlog and the phone never learned the outcome, even after the
    answer-first rework (user-reported 2026-07-16, third round). The
    exchange now runs on the shared worker thread (provisioning and
    standalone use it serially, never together); the portal loop accepts in
    250 ms slices, polls the exchange, and keeps serving /status the whole
    time, so every open page flips to All set within a second of success.
    cb_sign_in loses its LVGL calls (worker context); ui_setup_set_state
    was already c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
    [main.c, portal.c]
2026-07-16 CYD: working page concludes even when it sleeps through the broadcast
    Browsers suspend page timers the moment the screen dims, and the user
    is watching the DEVICE during sign-in -- the phone routinely misses the
    whole done-broadcast window and spun forever (user-reported
    2026-07-16). The page now counts contact: once the board has answered
    at least one poll, four consecutive connection failures can only mean
    it finished and rebooted, so the page declares success on its own.
    Grace window 6 s -> 8 s for pages that stay awake.
    [portal.c]
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2026-07-17 CYD: screen takeover happens before the boot scan, not after
    A setup-flow reboot held the bare splash color through the 1-2 s SSID
    scan before the boot bar appeared; the scan now runs under the progress
    screen so intentional reboots land on UI immediately (user feedback on
    hardware). Cold boots get the same ordering after the clip ends.
    [main.c]
2026-07-17 CYD: mid-provisioning reboots land on the setup screen, no splash
    A reboot with WiFi stored but no token has exactly one destination, so
    it now routes straight to run_provisioning: no splash frame, no detect
    window. A daemon can never lose the board to the shortcut -- its
    port-open is a hard reset, which clears the intentional mark. Settings
    re-sign-in reboots take the same shortcut, and provisioning is the
    right destination for those too.
    [main.c]
2026-07-17 CYD: wrong password fails fast and says so on the device
    A doomed join never yields a CONNECT_RESULT until the full 30 s
    timeout; the driver's word is the mid-association disconnect events.
    Auth-class reasons (4-way handshake timeout etc.) now fail the wait on
    first sight -- seconds instead of 30 -- and map to "Wrong password";
    other reasons get one free retry. The portal round also passes the
    join error to the setup screen, so the reason shows on the device
    (red, step 2) and not only on the phone form.
    [main.c]
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2026-07-17 CYD: a failed resume-join clears the stored credentials
    Leaving the bad pair in NVS made every later boot re-run the doomed
    join before reaching the portal. Established devices (token present)
    never take this branch, so an AP outage can't wipe a working setup.
    [main.c]
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2026-07-17 CYD: resume boot renders CONNECTING from the very first frame
    The scan-QR default flashed for one frame before the resume join's
    CONNECTING state landed, betraying the reboot mid-setup. The state is
    now queued before the first pump, so the restart is invisible.
    [main.c]
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2026-07-17 CYD: Clauge 0.3.0 - invisible reboots, unified boot bar, edge nav, WPA2 setup AP, night dim, fable peek
    One release-sized pass over the whole UI surface, driven by two rounds of
    on-hardware feedback:
    Setup flow
    - Brand is Clauge everywhere: screens, AP SSID (clauge-xxxxxx), page titles.
    - Intentional reboots are invisible: the skip splash paints the UI
    background instead of the clay, the REBOOT interstitial state is gone,
    and CONNECTING spans the reset as one continuous screen.
    - Every setup error is a dismissable popup; the QR caption hangs directly
    under the code and never shows a raw URL.
    - The setup AP is WPA2: a random 10-char password, persisted in NVS and
    carried inside the j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
    [main.c, proto.c]
2026-07-17 Clauge: close out the deferred list
    - Weekly gauge selection (All models / Fable) persists in NVS; the gauge
    wears the right name from the first frame after a reboot.
    - Near-limit warning also watches fable's own window - it can run dry
    while the overall weekly looks calm.
    - Backlight transitions log '[ui] backlight N%', so night mode is
    verifiable without waiting for 23:00.
    - Bridge announces itself as clauge-bridge 0.3.0.
    - firmware/README rewritten for the CYD/Clauge reality (the old ESP32-C6
    UART-only text was two hardware generations stale); HANDOFF.md kept as
    the historical brief with dated corrections, including the working
    User-Agent and the fable window.
    - Flash encrypti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
    [main.c]
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2026-07-18 Portal + gauges: fix phone sign-in popup and stale session reset
    Sign-in/WiFi forms submit via same-origin fetch() instead of a plain-HTTP
    form navigation, so phone browsers no longer show the "not secure" warning;
    every portal response now sends Cache-Control: no-store and the sign-in URL
    carries a per-boot cache-buster query, so a cached old page can't re-render.
    The gauge flips to 0% the instant a countdown ends instead of sitting on
    "now" until the API stops echoing the ended window.
    [main.c, portal.c]
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2026-07-18 Settings: center section titles, pad reset tiles, widen touch queue
    Center the BRIGHTNESS/RESET section labels (were left-aligned) and give the
    reset tiles more room between icon and label. Bump the input event queues
    64 -> 96 (the most this board's DRAM allows): the resistive panel's contact
    bounce fires a burst of INT edges per touch that overflowed the 64-deep
    queue and dropped button press/release events -> missed +/- taps. A live
    tap test went from dozens of dropped events to zero.
    [ui_settings.c]
2026-07-18 Settings: breathing room under section labels and in reset tiles
    Drop the -/+ buttons and reset tiles ~8 px below their BRIGHTNESS/RESET
    labels instead of flush against them, and widen the icon-to-text gap inside
    each reset tile.
    [ui_settings.c]
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2026-07-20 OTA: test-boot self-confirm with watchdog + revert reporting + worker check/install wiring
    Health bar per mode: standalone confirms on the first applied usage event
    (WiFi + TLS + parse proven); USB mode on the daemon's first usage push;
    provisioning never confirms and lets the 90 s deadline revert. Hardware
    watchdog (wdt0) armed only during test boots. Verified on hardware: USB
    flash boots as confirmed (no test-boot line), joins WiFi, no resets over
    5 minutes. dram0 96.1%, image 1,274,835 B.
    [main.c]
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2026-07-22 settings: grouped-list redesign + tap/gesture hardening
    Reworks the panel into a grouped-list layout (cards, section rules,
    top-bar back chevron, danger-styled factory tile) and fixes touch
    regressions surfaced on hardware:
    - Clear the default GESTURE_BUBBLE on all controls (LVGL 9 sets it on
    every child) so a tap that drifts a few px no longer bubbles up as a
    right-swipe and closes settings.
    - Separate the back chevron from the brightness '-' stepper (they
    overlapped, so a high tap on '-' hit 'back' and bounced home).
    - Software-update row: clear SCROLLABLE (a horizontal-drift tap was
    eaten as a scroll, so the button felt dead) and keep the right-hand
    status blank when idle so it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
    [ui_settings.c]
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2026-07-22 wifi: retry first join; ui: light touch-echo feedback
    - The first WiFi join after a cold boot (especially right after a flash)
    is RF-warmup-flaky and would drop mid-association, sending the board to
    the setup screen until a manual reset. Retry once behind the same
    CONNECTING screen; two clean failures still go to setup as before.
    - Add ui_touchfx: a soft, half-transparent circle that blooms at the
    press point and fades out (~0.4s), floating over every screen on the
    top layer and never intercepting a touch.
    [main.c]
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2026-07-25 OTA: make the update path actually work end to end
    First successful over-the-air update on this hardware: check, download,
    SHA-256 verify, MCUboot swap, boot and self-confirm. Three independent
    defects had to be fixed together; each one alone still left OTA broken.
    1. Redirect truncation (the immediate blocker). GitHub's release-asset
    Location header has grown to ~905 chars (SAS query params plus a JWT),
    but redirect_url and hpath were 768, so the URL was cut mid-JWT and the
    CDN answered the mangled request with a non-HTTP status -- 618, which
    is what the update check reported. Whether the cut was survivable
    depended on where the per-request JWT happened to land, which is why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
    [main.c]
2026-07-25 UI: time remaining under the download bar, honest label while installing
    Two things the update screen got wrong once a human watched it run.
    Time remaining. There was no estimate at all, so a 1.28 MB download over
    a slow link looked indistinguishable from a stall. The first attempt
    anchored on the first percent seen and extrapolated from it, which was
    unusable: for the first ~20 s it divides a 1-2 percent delta by a couple
    of seconds, so one slow TCP window swings the answer by minutes, and
    since the baseline never moves the early noise never washes out.
    Now it measures milliseconds-per-percent across each step, smooths that
    with an exponential moving average, and shows nothing at all unti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
    [ui_settings.c]
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2026-07-25 UI: tear down the download overlay when an install fails (0.4.3)
    The progress overlay is full-screen and deliberately swallows every touch
    so nothing underneath can run mid-download. It was never deleted anywhere
    -- the only note on its lifetime said "only a reboot ends it", which holds
    for a SUCCESSFUL install because that ends in a reboot, but not for a
    failed one, which returns to a live UI with an invisible wall over it.
    Dismissing the "Update failed" popup then left the device unresponsive to
    every tap, and ui_settings' own close path refuses to run while the
    overlay exists, so settings could not be backed out of either. Only a
    power cycle recovered it. User-reported 2026-07-25 after a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
    [ui_settings.c]
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2026-07-25 UI: say the install takes a few minutes instead of leaving the screen mute
    The install screen freezes for the whole MCUboot swap -- 179 s on the
    current bootloader, 357 s before this week's flash fixes -- and said only
    "Keep the device powered", which does not tell a user whether to wait or
    whether it has hung. That was the original complaint and it survived three
    rounds of me fixing other things.
    Deliberately "a few minutes" rather than a figure. The app cannot tell
    which bootloader it is running on: MCUboot is not delivered over the air,
    so an OTA'd image may sit on either the fast or the slow one, and a device
    that promises three minutes then takes six has recreated the exact "is it
    stuc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
    [ui_settings.c]
2026-07-25 OTA: defer the encrypted 0xFF fill -- swap now 121 s, was 357 s (0.4.7)
    Third and last of the swap-speed changes. Erasing a range on this
    flash-encrypted part owed an immediate write of encrypted 0xFF over the
    whole range, because erased ciphertext decrypts as garbage and MCUboot's
    revert logic needs unwritten trailer flags to read as 0xFF. During a swap
    that fill was almost entirely wasted: nearly every erased sector is
    overwritten microseconds later, and worse, the fill left programmed
    ciphertext behind and so forced a SECOND erase in the write path.
    The fill is now recorded rather than performed, and materialised only when
    it can actually be observed: on an overlapping read, on a partial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
    [ui_settings.c]
2026-07-25 WiFi: re-join after the link drops (0.4.8) -- RECONNECT PATH UNVERIFIED
    The station drops on its own after long uptimes -- AP idle timeout, a roam,
    a radio glitch; the user saw it roughly every half hour -- and nothing ever
    re-joined. net_wifi's disconnect handler only cleared have_ip, and the sole
    join runs on the UI thread in run_standalone() before the poll loop even
    starts. The board therefore stayed offline until it was power-cycled, and a
    drop mid-download killed an OTA install outright (2026-07-26).
    The worker now checks the link each pass and re-joins with backoff: 15 s to
    start, doubling to a five-minute ceiling, because a router that is genuinely
    down stays down and retrying the r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
    [main.c]
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2026-07-26 Comments: correct the rejoin backoff and swap-time notes
    Two comments that no longer describe what the code does. Found while reviewing
    the re-join failure path, which has still never executed on hardware.
    main.c: the backoff comment said it "starts quick" at 15 s. It does not -- the
    failure path doubles rejoin_wait_ms before waiting, so the printed sequence is
    30 -> 60 -> 120 -> 240 -> 300 s and "retry in 15 s" never appears. 15 s is only
    the post-success reset value. Also record that a failed net_wifi_connect(.., 30)
    can block the worker ~36-66 s on its own (6 s request-retry loop, then the 30 s
    timeout applied to association and again to DHCP), so an outage shorter than
    that can be absor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
    [main.c, ui_settings.c]
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
